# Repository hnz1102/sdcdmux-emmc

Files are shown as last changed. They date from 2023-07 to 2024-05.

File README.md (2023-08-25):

<div align="center">
  <h1><code>SDCDMUX</code></h1>
  <p>
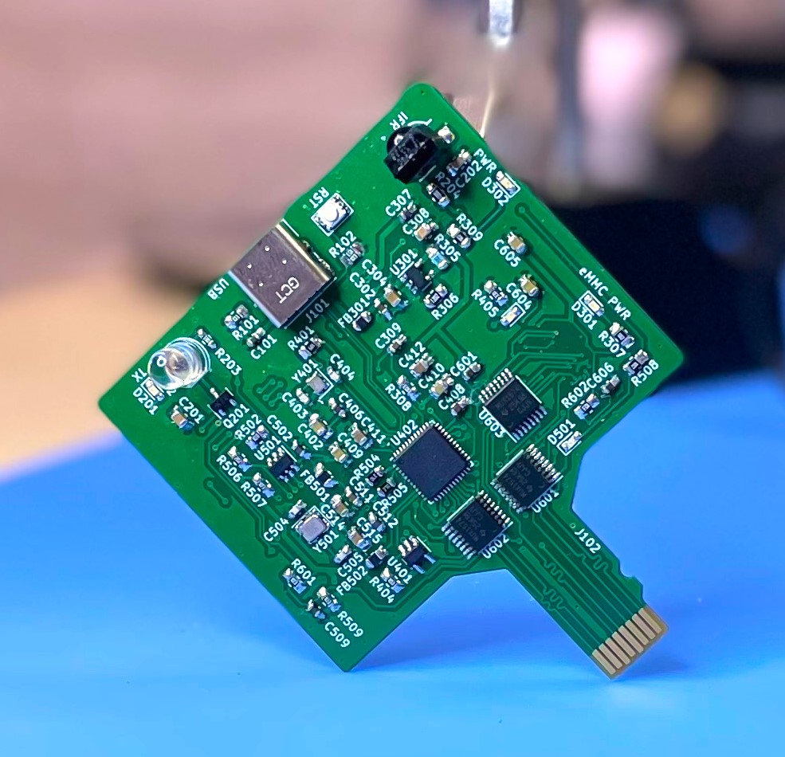
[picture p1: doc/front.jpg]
    
  </p>
</div>

# SDCDMUX : SD Card and eMMC Device Multiplexsor with Infrared Remote Control

The SDCDMUX provides a convenient and quick change of a SW image of a device that has an SD Card interface from a remote. 

When I am developing by booting from an SD memory card on a device such as the Raspberry Pi, it is not easy to rewrite the SD card image and replace it by hand. Remove the SD card, insert it into the host PC, and take a dozen minutes rewriting the SW image, after that, return the SD card to the device and turn on the power... But, This tool can change the image of the eMMC directly from the host PC, and the device can be booted as an SD card with the new image.

Usually, To boot with the new SW image, the device must be reset, but this tool can learn the ON/OFF command of the infrared power controller and outputs that command to turn the device on and off.

This tool frees me from the tedious SW image rewriting and resetting process.

https://github.com/hnz1102/sdcdmux-emmc/assets/111413646/edf4297e-6da3-4eba-aacd-01ee126e1040

### [2023.8.15] USB Type-C version Added.
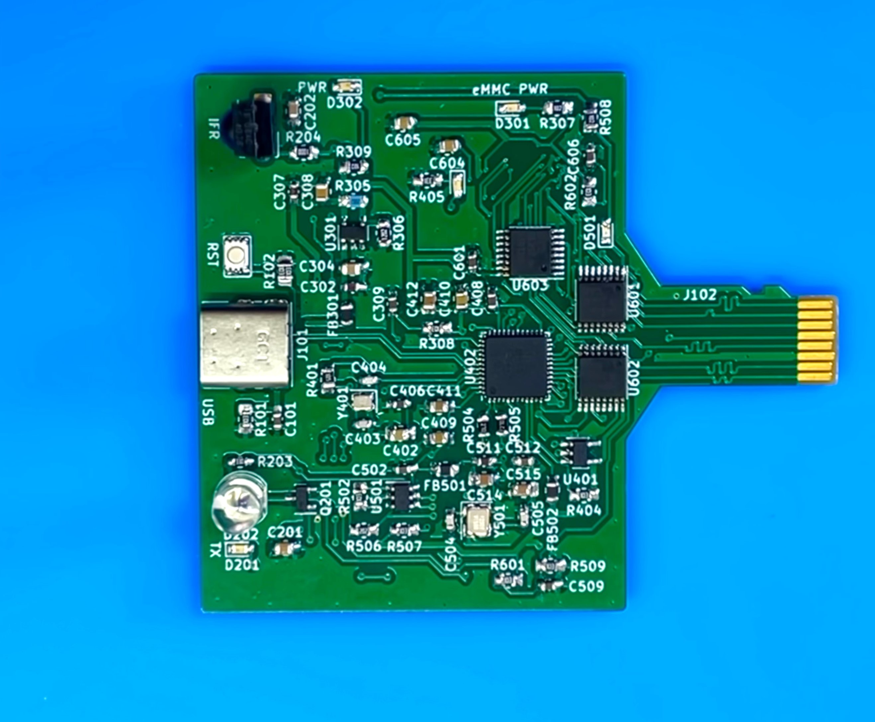
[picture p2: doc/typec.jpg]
USB Type-C

The Schematic is hardware/emmc-type-c-version/ directory.

## Features

- **Fast**. SDCDMUX can write an image to the eMMC device (32GB) instead of SD Memory Card via High-Speed USB. It is 4 times faster than an SD card. 

- **Remote Control**. SDCDMUX has an infrared interface that can receive an infrared remote control command and send it to power control devices. If you want to turn on a device, you can type the command "on" on the PC console.

- **Use Fast Switch**. When I used the prototype, Sometimes Rasbery Pi4 could not boot by read error. I tried to change faster switching devices in this tool. Then, Raspberry Pi always can boot correctly.

## Tested Devices

I have checked the following devices that can boot from this tool.

- [Raspberry Pi 4 Model B](https://www.raspberrypi.com/products/raspberry-pi-4-model-b/)
- [BeagleBone Black](https://beagleboard.org/black)
- [BeagleBone Blue](https://beagleboard.org/blue)

Only 3 devices because I have my own now.

## Infrared Remote Power Switch

The Infrared Remote Contorol Power Swtich I used is [OCR-05W OHM ELECTRIC INC.](https://www.ohm-electric.co.jp/product/c23/c2313/19582/). But I think other switch devices that can control by the infrared LED may be able to work too. 

## How to build the control SW.

This software (sdcdmux) is for Linux. 

The following example is for Ubuntu Linux Ubuntu 22.04.2 LTS.

1. Install build tools
```
$ sudo apt -y install build-essential libftdi-dev
```

2. Build the software.
```
$ cd sdcdmux
$ make
$ sudo cp sdcdmux /usr/local/bin/ 
```
3. Add a udev rule.
/etc/udev/rules.d/99-ft232h.rules
```
$ sudo su
# echo 'SUBSYSTEMS=="usb", ATTRS{idVendor}=="0403", ATTRS{idProduct}=="6014",  MODE=
"0666"' > /etc/udev/rules.d/99-ft232h.rules
# udevadm control --reload-rules
# udevadm trigger
```

## How to use SDCDMUX.

1. Connect to SDCDMUX via the USB cable with your PC. Power USB cable connect to the target device and USB adoptor. Please refer to the figure. 
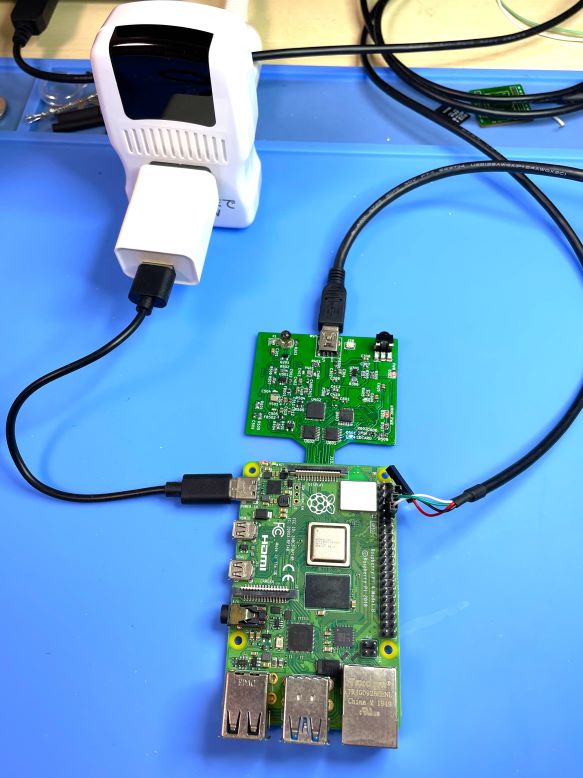
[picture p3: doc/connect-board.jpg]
cable connect

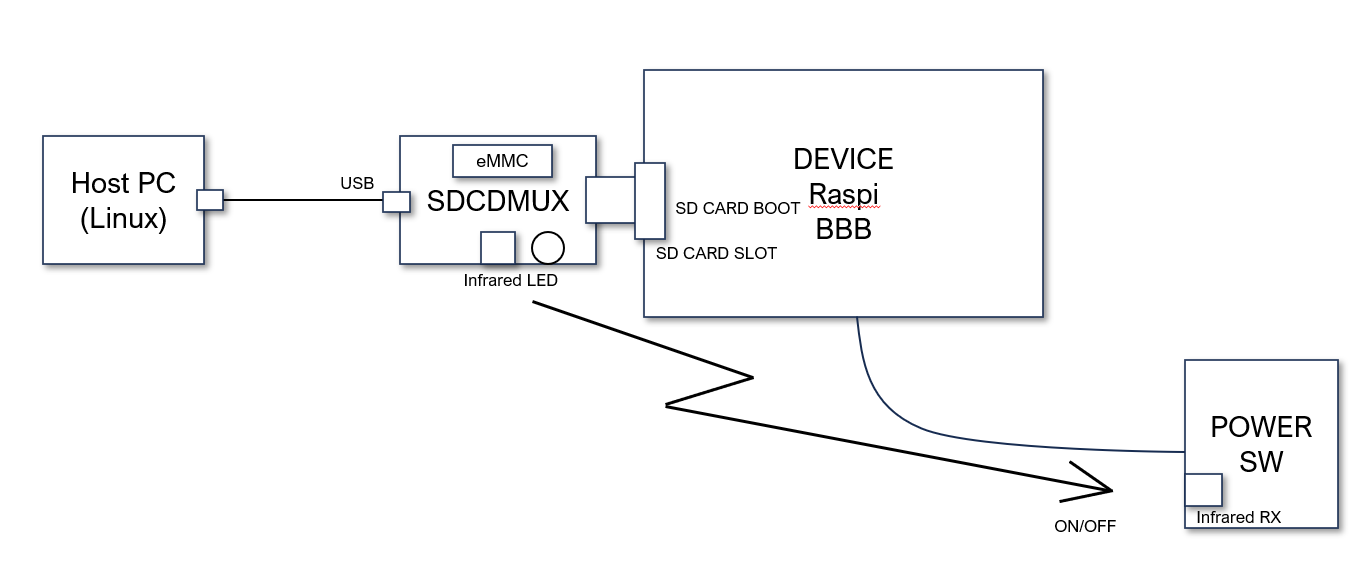
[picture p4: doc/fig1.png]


2. Use SDCDMUX

- Display current status.
```
$ sdcdmux
Memory Device is connected to : HOST.
```

- Capture infrared ON command.
```
$ sdcdmux -c on
Capture Start.. 
"Push ON button on your Infrared Remote Controller"
Recieve IFR data (18245B)
Captured command for on
```
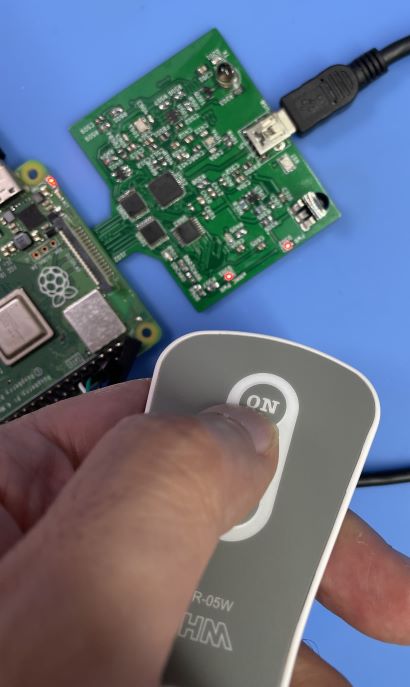
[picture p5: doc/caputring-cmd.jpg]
capture command


After capture the command, you can see the 'if-on' file in the current directory.

- Capture infrared OFF command.
```
$ sdcdmux -c off
Capture Start.. 
"Push OFF button on your Infrared Remote Controller"
Recieve IFR data (11449B)
Captured command for off
```

- Select eMMC memory to host PC side.
```
$ sdcdmux -s host
Memory Device is connected to : HOST.
```
You can see eMMC disk drive on your PC.
```
$ lsblk
:
sdb           8:16   1  29.1G  0 disk 
:
```
In my case, I can see the new disk drive as 'sdb'.

- Download the Raspberry Pi boot image and Write it to eMMC.

** !WARNING! ** DO NOT OVERWRITE YOUR SYSTEM DISK DRIVE! BE CAREFUL THE WRITING DISK DRIVE NAME.

```
$ wget https://downloads.raspberrypi.org/raspios_armhf/images/raspios_armhf-2023-05-03/2023-05-03-raspios-bullseye-armhf.img.xz
$ xzcat 2023-05-03-raspios-bullseye-armhf.img.xz | sudo dd of=/dev/sdb bs=1M status=progress
4125163520 bytes (4.1 GB, 3.8 GiB) copied, 94 s, 43.9 MB/s
0+491118 records in
0+491118 records out
4143972352 bytes (4.1 GB, 3.9 GiB) copied, 126.121 s, 32.9 MB/s
$ lsblk
sdb           8:16   1  29.1G  0 disk 
├─sdb1        8:17   1   256M  0 part 
└─sdb2        8:18   1   3.6G  0 part 
```

- Select eMMC memory to target (Raspberry Pi) device.
```
$ sdcdmux -s target
Memory Device is connected to : TARGET.
```
You can see the blue LED is turn on.

- Turn on the device using infrared on command.
```
$ sdcdmux -x on
```

- Turn off the device using infrared on command.
```
$ sdcdmux -x off
```

- Another devices control.

I also use the SDCDMUX as a controller to turn ceiling lights on and off.
```
$ sdcdmux -c lightson
Capture Start.. 
"Press ON on the remote controller of the ceiling light to make it learn the command."
Recieve IFR data (8498B)
Captured command for lightson

$ sdcdmux -c lightsoff
Capture Start.. 
"Press OFF on the remote controller of the ceiling light to make it learn the command."
Recieve IFR data (10701B)
Captured command for lightsoff

$ sdcdmux -x lightson
"Seiling lights turn on."

$ sdcdmux -x lightsoff
"Seiling lights turn off."
```

## Performance

I created an SD card type and an eMMC type. I compared their writing times.

4.2GB Image Writing Time (Average of 3 times)
|SD card (*1)|eMMC (*2)|
|----|----|
|482.3 sec (8.7MB/s)|134.7 sec (31.3MB/s)|

*1 San Disk Ultla 32GB HC1 SD CARD

*2 Delkin Devices EM32VSUKN 32GB eMMC

## SDCDMUX Board

SDCDMUX Board Schematic and a PCB layout are placed in the hardware directory. There are 2 types emmc-version and sdcard-version. This emmc-version uses an eMMC device instead of a SD memory card.
Schematic data is created by KidCad 7.0.

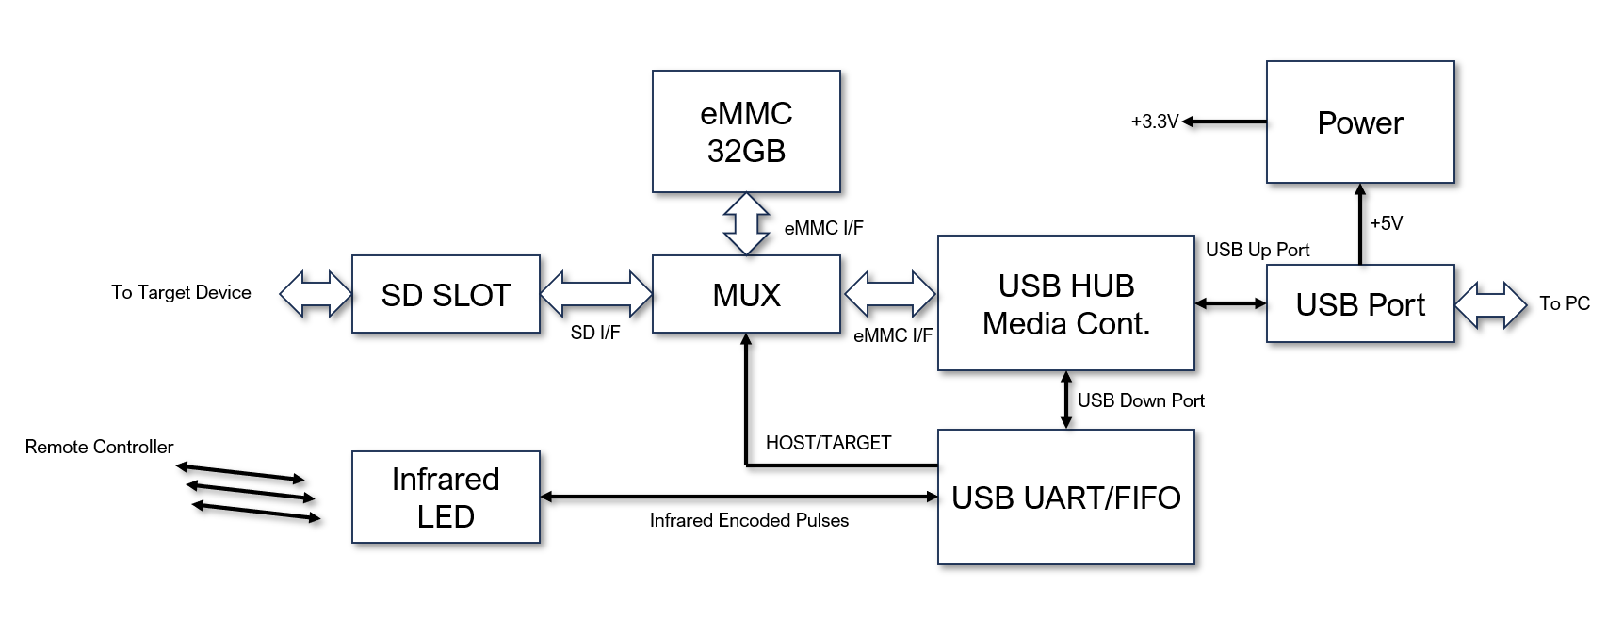
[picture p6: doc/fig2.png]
Block Diagram


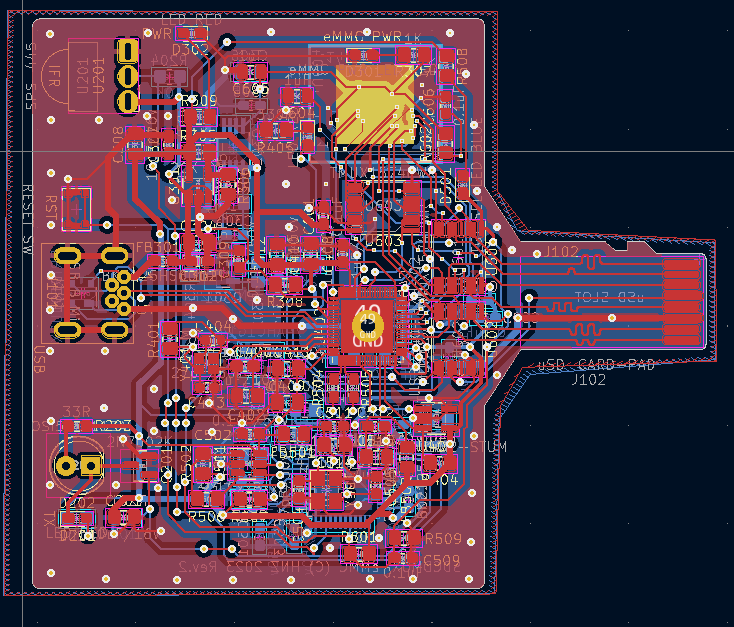
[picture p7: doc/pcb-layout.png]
PCB Layout


If you order a PCB board from a PCB maker, it must be 0.8mm thick. Otherwise, it will not fit in the SD card slot.

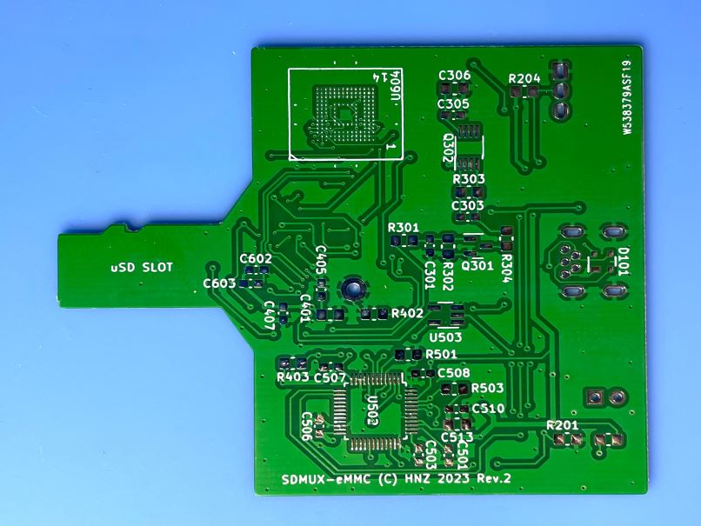
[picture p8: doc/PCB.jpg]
PCB


After building the board, It has to configure EEPROMs of the USB Media Controller and USB FIFO Interface.

The USB Media Controller has an EEPROM. It is programmed with the parameters by [USBDM tool](https://www.microchip.com/en-us/software-library/usbdm-tool).

- Manufacture String
- Serial Number String

Single Channel HiSpeed USB to Multipurpose UART/FIFO IC (FT232H) has an EEPROM too. It is programmed the parameters by [FT_Prog](https://ftdichip.com/wp-content/uploads/2023/06/FT_Prog_v3.12.32.640-Installer.zip).

- FT EEPROM - HARDWARE Specific IO Controls - C5, C6, C8 and C9 ports are I/O Mode set.

# CASE

I created the case for SDCDMUX type-C version by 3D printer. There are STL data in the hardware/emmc-type-c-version/case directory.

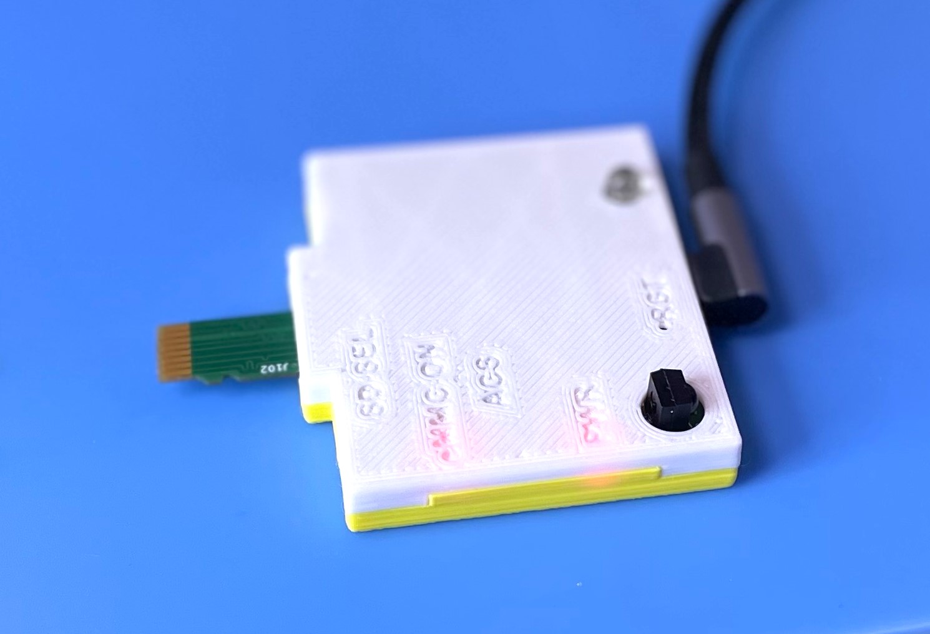
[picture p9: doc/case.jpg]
case


## LICENSE
This Software is licensed under MIT. Other Hardware Schematic documents are licensed under CC-BY-SA V4.0.

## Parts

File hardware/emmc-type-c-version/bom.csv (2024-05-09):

Reference | Value | Datasheet | Footprint | Qty | DNP | digikey | storeURL
C101,C301,C302,C305,C307,C309,C405,C406,C407,C408,C501,C502,C503,C506,C507,C508,C509,C510,C511,C512,C601,C602,C603,C606 | 0.1uF | ~ | Capacitor_SMD:C_0603_1608Metric_Pad1.08x0.95mm_HandSolder | 24 |  | 311-1824-1-ND | https://www.digikey.com/en/products/detail/yageo/CC0603MRX7R7BB104/5195231
C201,C304,C306,C308 | 10uF | ~ | Capacitor_SMD:C_0805_2012Metric_Pad1.18x1.45mm_HandSolder | 4 |  | 311-1355-1-ND | https://www.digikey.com/en/products/detail/yageo/CC0805ZKY5V6BB106/2103093
C202 | 22uF | ~ | Capacitor_SMD:C_0603_1608Metric_Pad1.08x0.95mm_HandSolder | 1 |  | 311-1815-1-ND | https://www.digikey.com/en/products/detail/yageo/CC0603MRX5R5BB226/5195222
C303 | 2.2uF | ~ | Capacitor_SMD:C_0603_1608Metric_Pad1.08x0.95mm_HandSolder | 1 |  | 311-1795-1-ND | https://www.digikey.com/en/products/detail/yageo/CC0603KRX7R5BB225/5195203
C401,C402,C409,C410,C604,C605 | 1uF | ~ | Capacitor_SMD:C_0805_2012Metric_Pad1.18x1.45mm_HandSolder | 6 |  | 311-3440-1-ND | https://www.digikey.com/en/products/detail/yageo/CC0805MRY5V7BB105/5884286
C403,C404,C504,C505 | 27pF | ~ | Capacitor_SMD:C_0603_1608Metric_Pad1.08x0.95mm_HandSolder | 4 |  | 311-1063-1-ND | https://www.digikey.com/en/products/detail/yageo/CC0603JRNPO9BN270/302797
C411,C412,C513,C514,C515 | 4.7uF | ~ | Capacitor_SMD:C_0805_2012Metric_Pad1.18x1.45mm_HandSolder | 5 |  | 490-14466-1-ND | https://www.digikey.com/en/products/detail/murata-electronics/GRM21BR71C475KE51L/6606095
D101 | PRTR5V0U2X | https://assets.nexperia.com/documents/data-sheet/PRTR5V0U2X.pdf | Package_TO_SOT_SMD:SOT-143 | 1 |  | 1727-3884-1-ND | https://www.digikey.com/en/products/detail/nexperia-usa-inc/PRTR5V0U2X-215/1163690
D201,D302,D401 | LED RED | ~ | tbctl:LED_0603_1608Metric_Pad1.05x0.95mm_HandSolder | 3 |  | 511-1587-1-ND | https://www.digikey.com/en/products/detail/rohm-semiconductor/SML-E12V8WT86/1641806
D202 | OED-EL-1L2 |  | LED_THT:LED_D5.0mm | 1 |  | 67-1001-ND | https://www.digikey.com/en/products/detail/lumex-opto-components-inc/OED-EL-1L2/270797
D301 | eMMC PWR LED RED | ~ | tbctl:LED_0603_1608Metric_Pad1.05x0.95mm_HandSolder | 1 |  | 511-1587-1-ND | https://www.digikey.com/en/products/detail/rohm-semiconductor/SML-E12V8WT86/1641806
D501 | TGT SEL LED BLUE | ~ | tbctl:LED_0603_1608Metric_Pad1.05x0.95mm_HandSolder | 1 |  | 846-1177-1-ND | https://www.digikey.com/en/products/detail/rohm-semiconductor/SMLE13BC8TT86/5053771
FB301,FB501,FB502 | BK2125HS601-T | ~ | Inductor_SMD:L_0603_1608Metric_Pad1.05x0.95mm_HandSolder | 3 |  | 490-1014-1-ND | https://www.digikey.com/en/products/detail/murata-electronics/BLM18AG601SN1D/584225
J101 | USB_C_Receptacle_USB2.0_GCT4085 | https://www.usb.org/sites/default/files/documents/usb_type-c.zip | Connector_USB:USB_C_Receptacle_GCT_USB4085 | 1 |  | 2073-USB4085-GF-ACT-ND | https://www.digikey.com/en/products/detail/gct/USB4085-GF-A/9859662
J102 | uSD-CARD-PAD | ~ | tbctl:uSD Card Pad | 1 |  | Just Pattern
Q201,Q301 | 2N7002K | https://www.diodes.com/assets/Datasheets/ds30896.pdf | Package_TO_SOT_SMD:SOT-23 | 2 |  | 2N7002K-7DICT-ND | https://www.digikey.com/en/products/detail/diodes-incorporated/2N7002K-7/1934378
Q302 | IRF7606TRPBF | http://www.irf.com/product-info/datasheets/data/irf7606pbf.pdf | Package_SO:MSOP-8_3x3mm_P0.65mm | 1 |  | IRF7606TRPBFCT-ND | https://www.digikey.com/en/products/detail/infineon-technologies/IRF7606TRPBF/856652
R101,R201,R205,R302,R303,R308,R403,R404,R502,R503,R507,R509,R601,R602 | 10K | ~ | Resistor_SMD:R_0805_2012Metric_Pad1.20x1.40mm_HandSolder | 14 |  | 311-10KARCT-ND | https://www.digikey.com/en/products/detail/yageo/RC0805JR-0710KL/728241
R102,R103 | 5.1K | ~ | Resistor_SMD:R_0805_2012Metric_Pad1.20x1.40mm_HandSolder | 2 |  | 311-5.1KARCT-ND | https://www.digikey.com/en/products/detail/yageo/RC0805JR-075K1L/728338
R202,R304,R307,R309,R508 | 1K | ~ | Resistor_SMD:R_0805_2012Metric_Pad1.20x1.40mm_HandSolder | 5 |  | 311-1.0KARCT-ND | https://www.digikey.com/en/products/detail/yageo/RC0805JR-071KL/728218
R203 | 33R | ~ | Resistor_SMD:R_0603_1608Metric_Pad0.98x0.95mm_HandSolder | 1 |  | 311-33GRCT-ND | https://www.digikey.com/en/products/detail/yageo/RC0603JR-0733RL/726771
R204 | 100 | ~ | Resistor_SMD:R_0805_2012Metric_Pad1.20x1.40mm_HandSolder | 1 |  | 311-100ARCT-ND | https://www.digikey.com/en/products/detail/yageo/RC0805JR-07100RL/728238
R301,R506 | 2K | ~ | Resistor_SMD:R_0805_2012Metric_Pad1.20x1.40mm_HandSolder | 2 |  | 311-2.0KARCT-ND | https://www.digikey.com/en/products/detail/yageo/RC0805JR-072KL/728268
R305 | 20K 1% | ~ | Resistor_SMD:R_0805_2012Metric_Pad1.20x1.40mm_HandSolder | 1 |  | 311-20.0KCRCT-ND | https://www.digikey.com/en/products/detail/yageo/RC0805FR-0720KL/727720
R306,R402,R501 | 12K 1% | ~ | Resistor_SMD:R_0805_2012Metric_Pad1.20x1.40mm_HandSolder | 3 |  | 311-12.0KCRCT-ND | https://www.digikey.com/en/products/detail/yageo/RC0805FR-0712KL/727568
R401 | 1M | ~ | Resistor_SMD:R_0805_2012Metric_Pad1.20x1.40mm_HandSolder | 1 |  | 311-1.0MARCT-ND | https://www.digikey.com/en/products/detail/yageo/RC0805JR-071ML/728219
R405 | 330R | ~ | Resistor_SMD:R_0805_2012Metric_Pad1.20x1.40mm_HandSolder | 1 |  | 311-330ARCT-ND | https://www.digikey.com/en/products/detail/yageo/RC0805JR-07330RL/728311
R504,R505 | 27R | ~ | Resistor_SMD:R_0603_1608Metric_Pad0.98x0.95mm_HandSolder | 2 |  | 311-27GRCT-ND | https://www.digikey.com/en/products/detail/yageo/RC0603JR-0727RL/726751
SW301 | RESET SW |  | tbctl:WS-TASV SMT Tact Switch | 1 |  | 732-435151014824CT-ND | https://www.digikey.com/en/products/detail/w%C3%BCrth-elektronik/435151014824/11627325
U201 | TSSP4038 |  | tbctl:TSSP4038 | 1 |  | TSSP4038-ND | https://www.digikey.com/en/products/detail/vishay-semiconductor-opto-division/TSSP4038/3789836
U301 | SPX3819M5-L | https://www.exar.com/content/document.ashx?id=22106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 | Package_TO_SOT_SMD:SOT-23-5 | 1 |  | 1016-1871-1-ND | https://www.digikey.com/en/products/detail/maxlinear-inc/SPX3819M5-L-TR/2472388
U401 | AT24MAC402-STUM | https://ww1.microchip.com/downloads/en/DeviceDoc/Atmel-8807-SEEPROM-AT24MAC402-602-Datasheet.pdf | Package_TO_SOT_SMD:SOT-23-5_HandSoldering | 1 |  | AT24MAC402-STUM-TCT-ND | https://www.digikey.com/en/products/detail/microchip-technology/AT24MAC402-STUM-T/3973071
U402 | USB2640-HZH-02 |  | tbctl:QFN-48-1EP_7x7mm_P0.5mm_EP5.15x5.15mm | 1 |  | USB2640-HZH-02-ND | https://www.digikey.com/en/products/detail/microchip-technology/USB2640-HZH-02/3873172
U501 | 93LCxxBxxOT | http://ww1.microchip.com/downloads/en/DeviceDoc/20001749K.pdf | Package_TO_SOT_SMD:SOT-23-6 | 1 |  | 93LC56BT-I/OTCT-ND | https://www.digikey.com/en/products/detail/microchip-technology/93LC56BT-I-OT/572825
U502 | FT232HL | https://www.ftdichip.com/Support/Documents/DataSheets/ICs/DS_FT232H.pdf | Package_QFP:LQFP-48_7x7mm_P0.5mm | 1 |  | 768-1348-ND | https://www.digikey.com/en/products/detail/ftdi-future-technology-devices-international-ltd/FT232HL-TRAY/4006918
U503 | 74AHC1G14 |  | Package_TO_SOT_SMD:SOT-23-5_HandSoldering | 1 |  | 74AHC1G14W5-7DICT-ND | https://www.digikey.com/en/products/detail/diodes-incorporated/74AHC1G14W5-7/2639249
U601,U602,U603 | TMUX1574PWR |  | Package_SO:TSSOP-16_4.4x5mm_P0.65mm | 3 |  | 296-53444-1-ND | https://www.digikey.com/en/products/detail/texas-instruments/TMUX1574PWR/9954224
U604 | EM32VSUKN |  | tbctl:EM32VSUKN FPGA153 | 1 |  | 3247-EM32VSUKN-BA000-2-ND | https://www.digikey.com/en/products/detail/delkin-devices-inc/EM32VSUKN-BA000-2/16357650
Y401 | 24MHz | ~ | tbctl:Crystal_SMD_2016-4Pin_2.0x1.6mm | 1 |  | XC3064CT-ND | https://www.digikey.com/en/products/detail/ecs-inc/ECS-240-12-37B-CKY-TR/9838851
Y501 | 12MHz | ~ | Crystal:Crystal_SMD_3225-4Pin_3.2x2.5mm | 1 |  | SER3682CT-ND | https://www.digikey.com/en/products/detail/epson/FA-238V-12-0000MB-K3/2403374

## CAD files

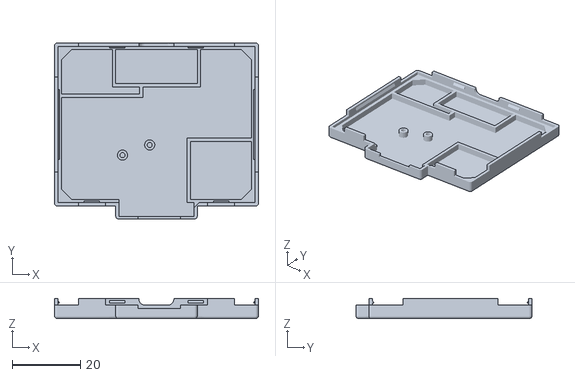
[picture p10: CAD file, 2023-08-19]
hardware/emmc-type-c-version/case/botom-body.stl
60.0 x 51.8 x 6.00

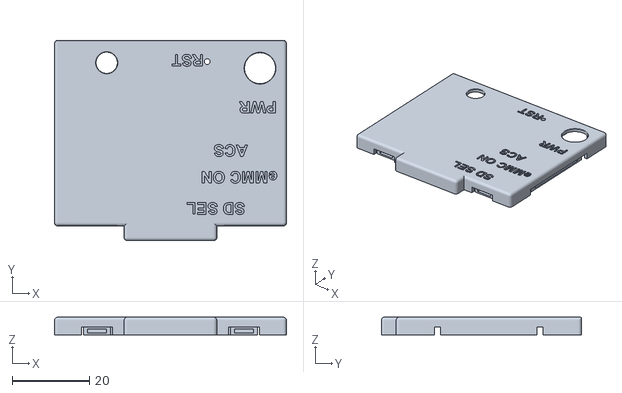
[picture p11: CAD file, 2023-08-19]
hardware/emmc-type-c-version/case/upper-body.stl
60.0 x 51.8 x 4.60

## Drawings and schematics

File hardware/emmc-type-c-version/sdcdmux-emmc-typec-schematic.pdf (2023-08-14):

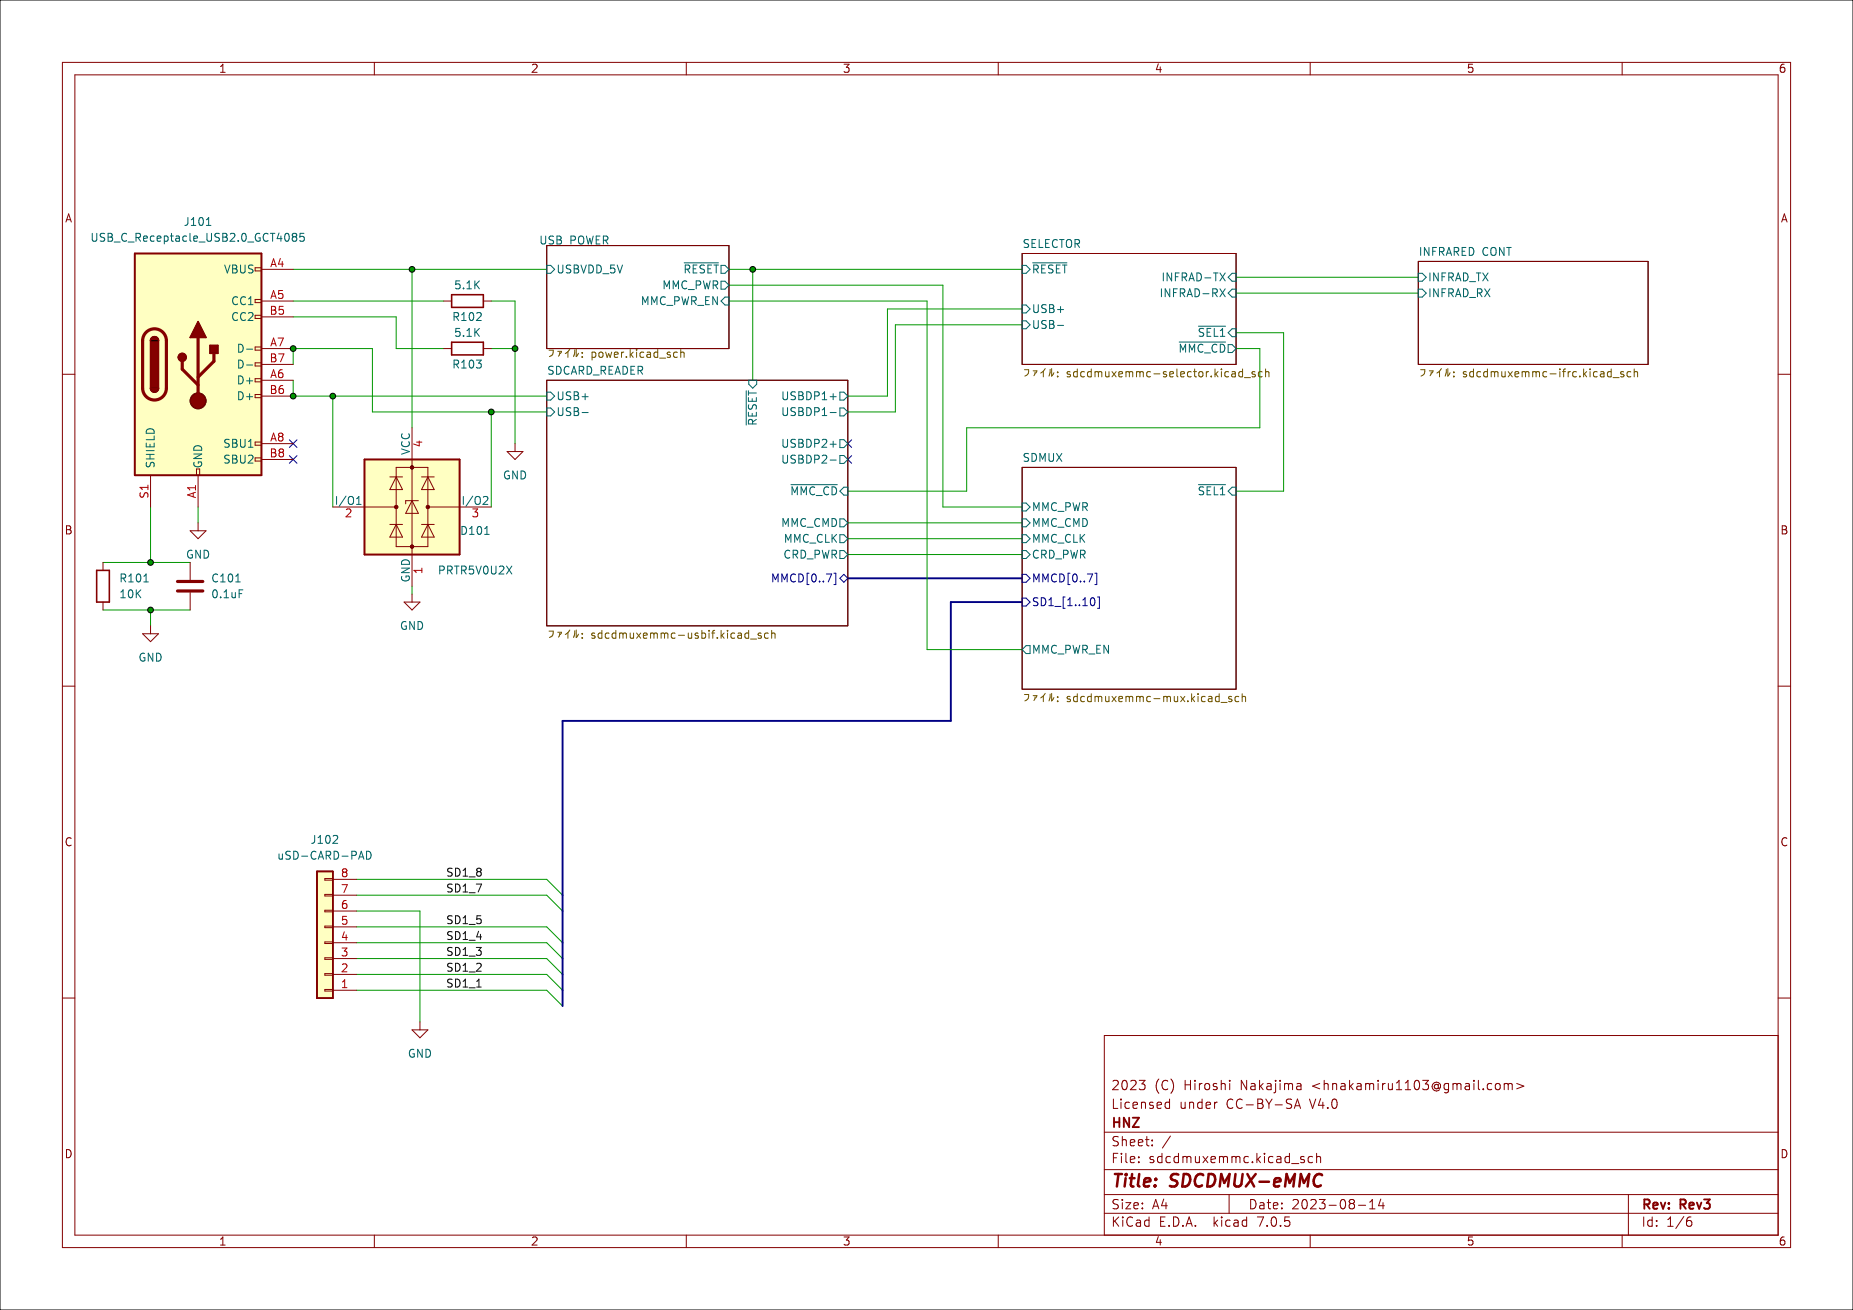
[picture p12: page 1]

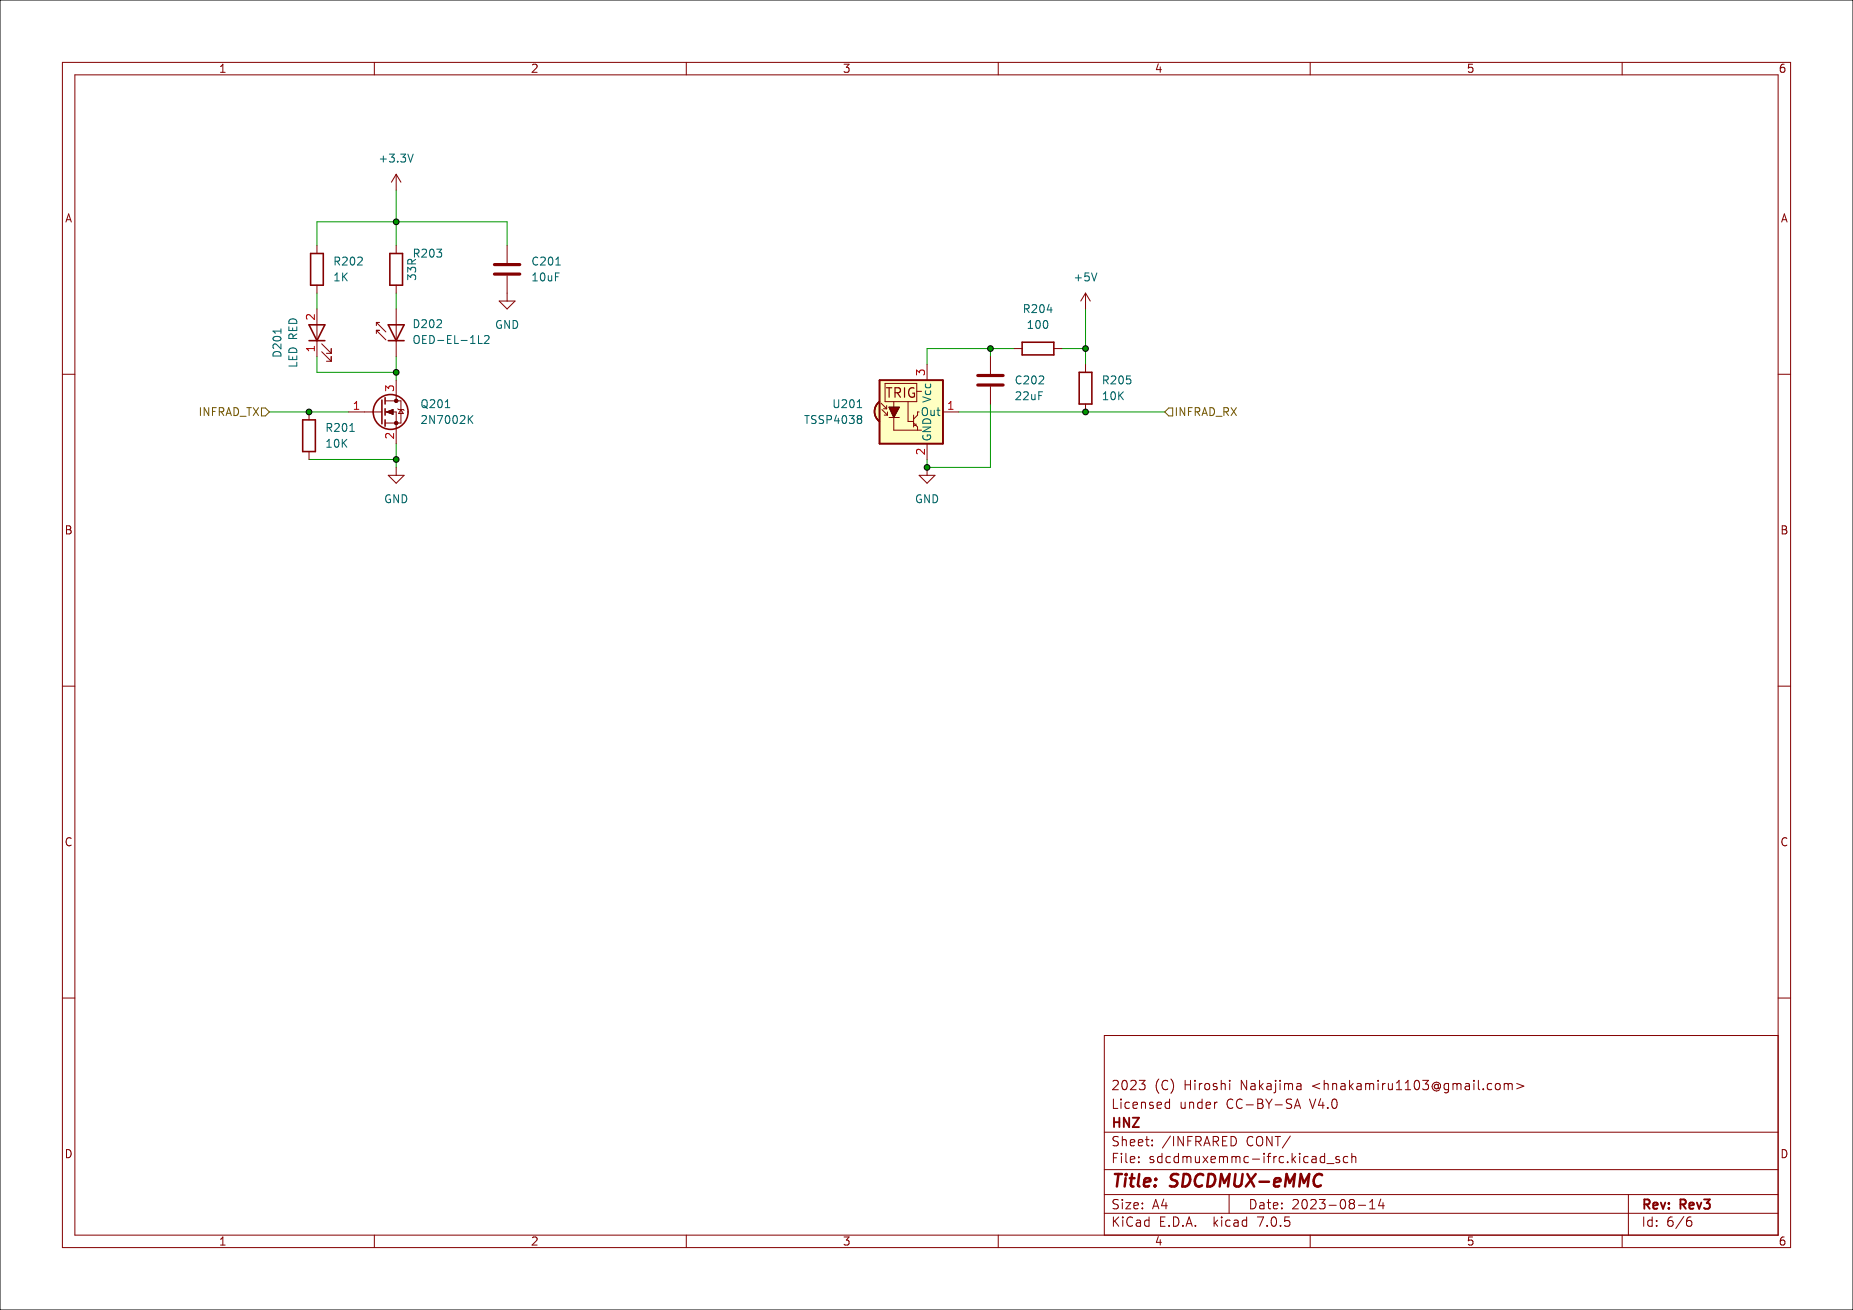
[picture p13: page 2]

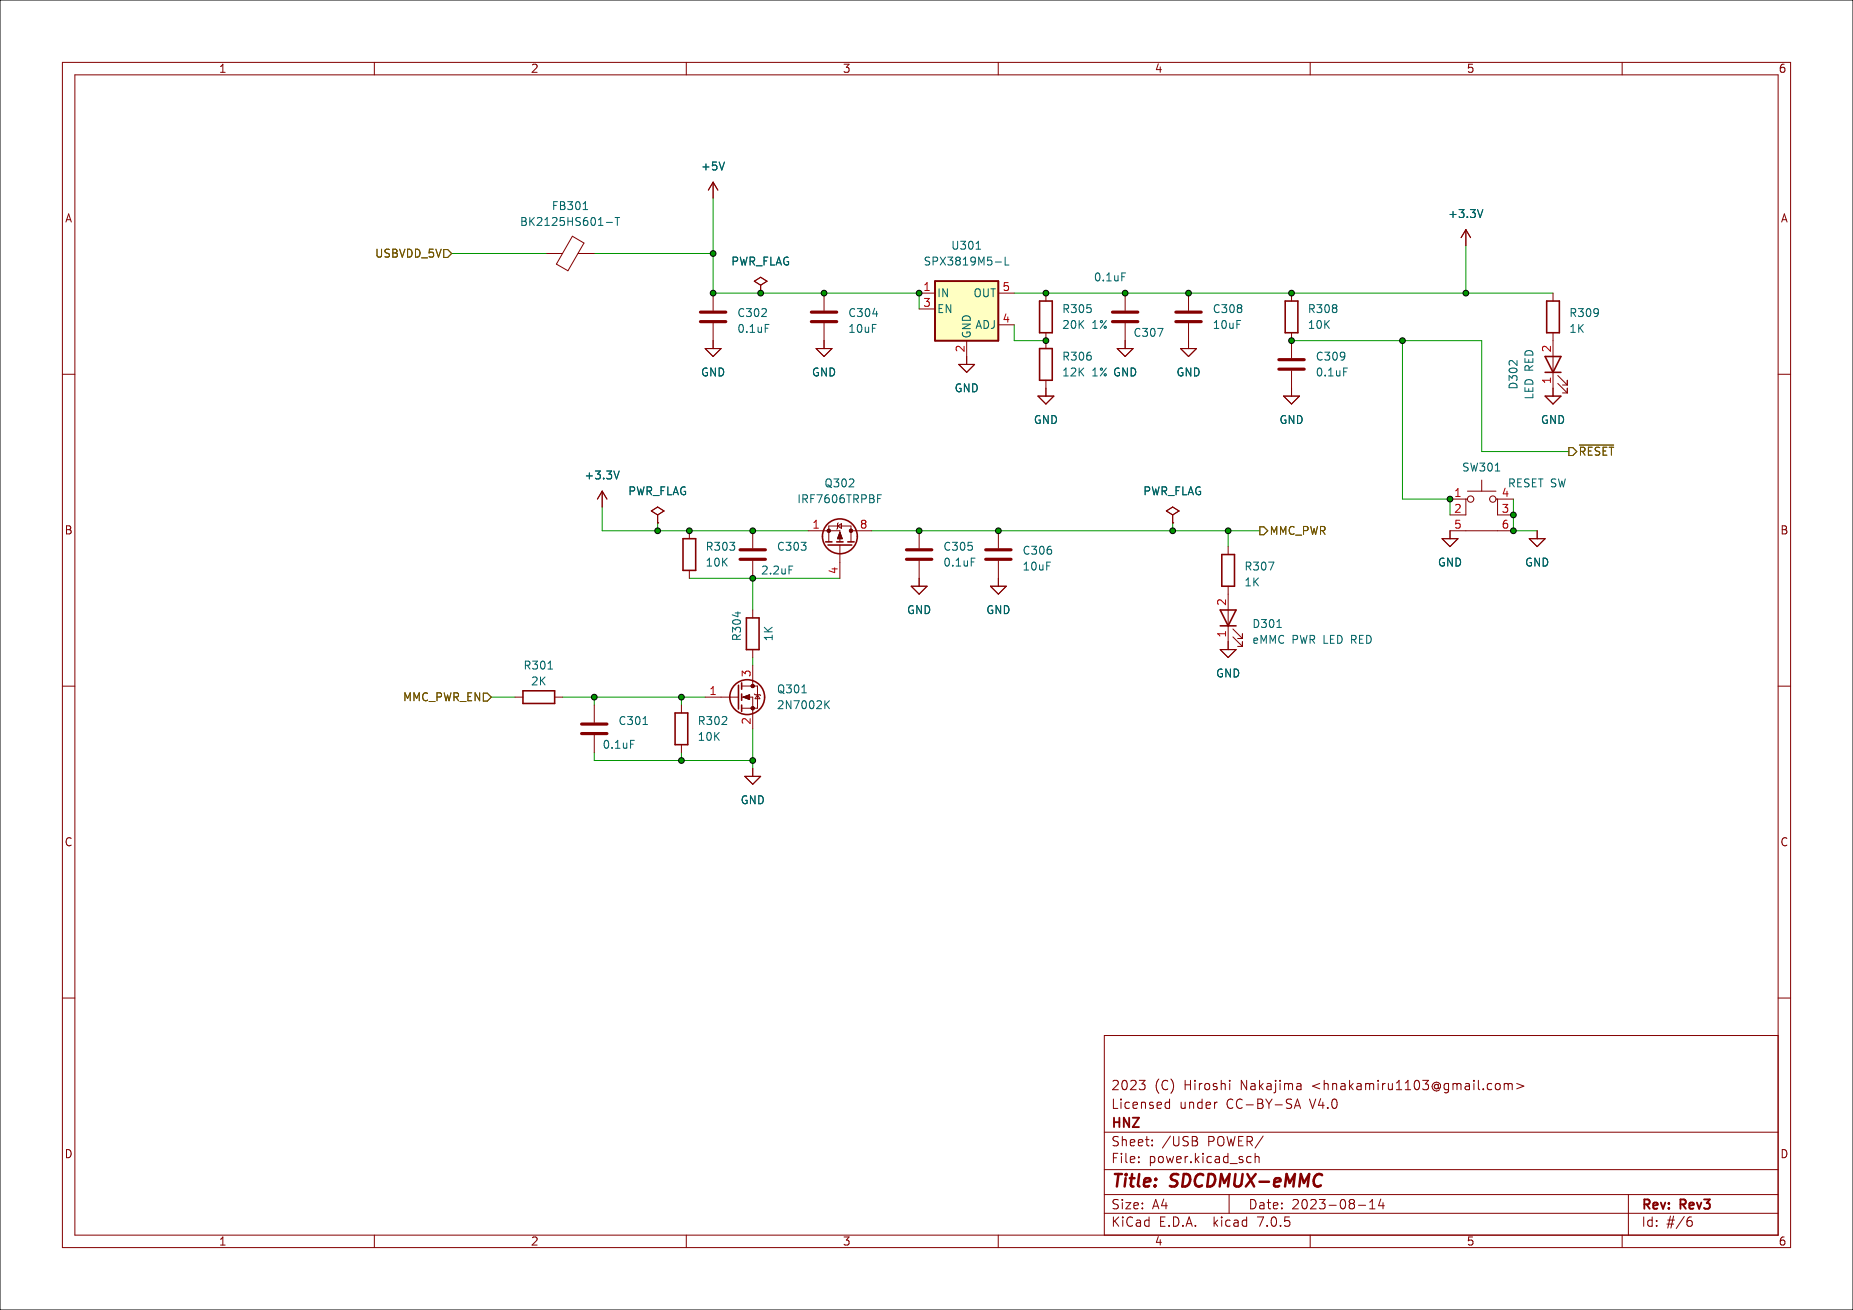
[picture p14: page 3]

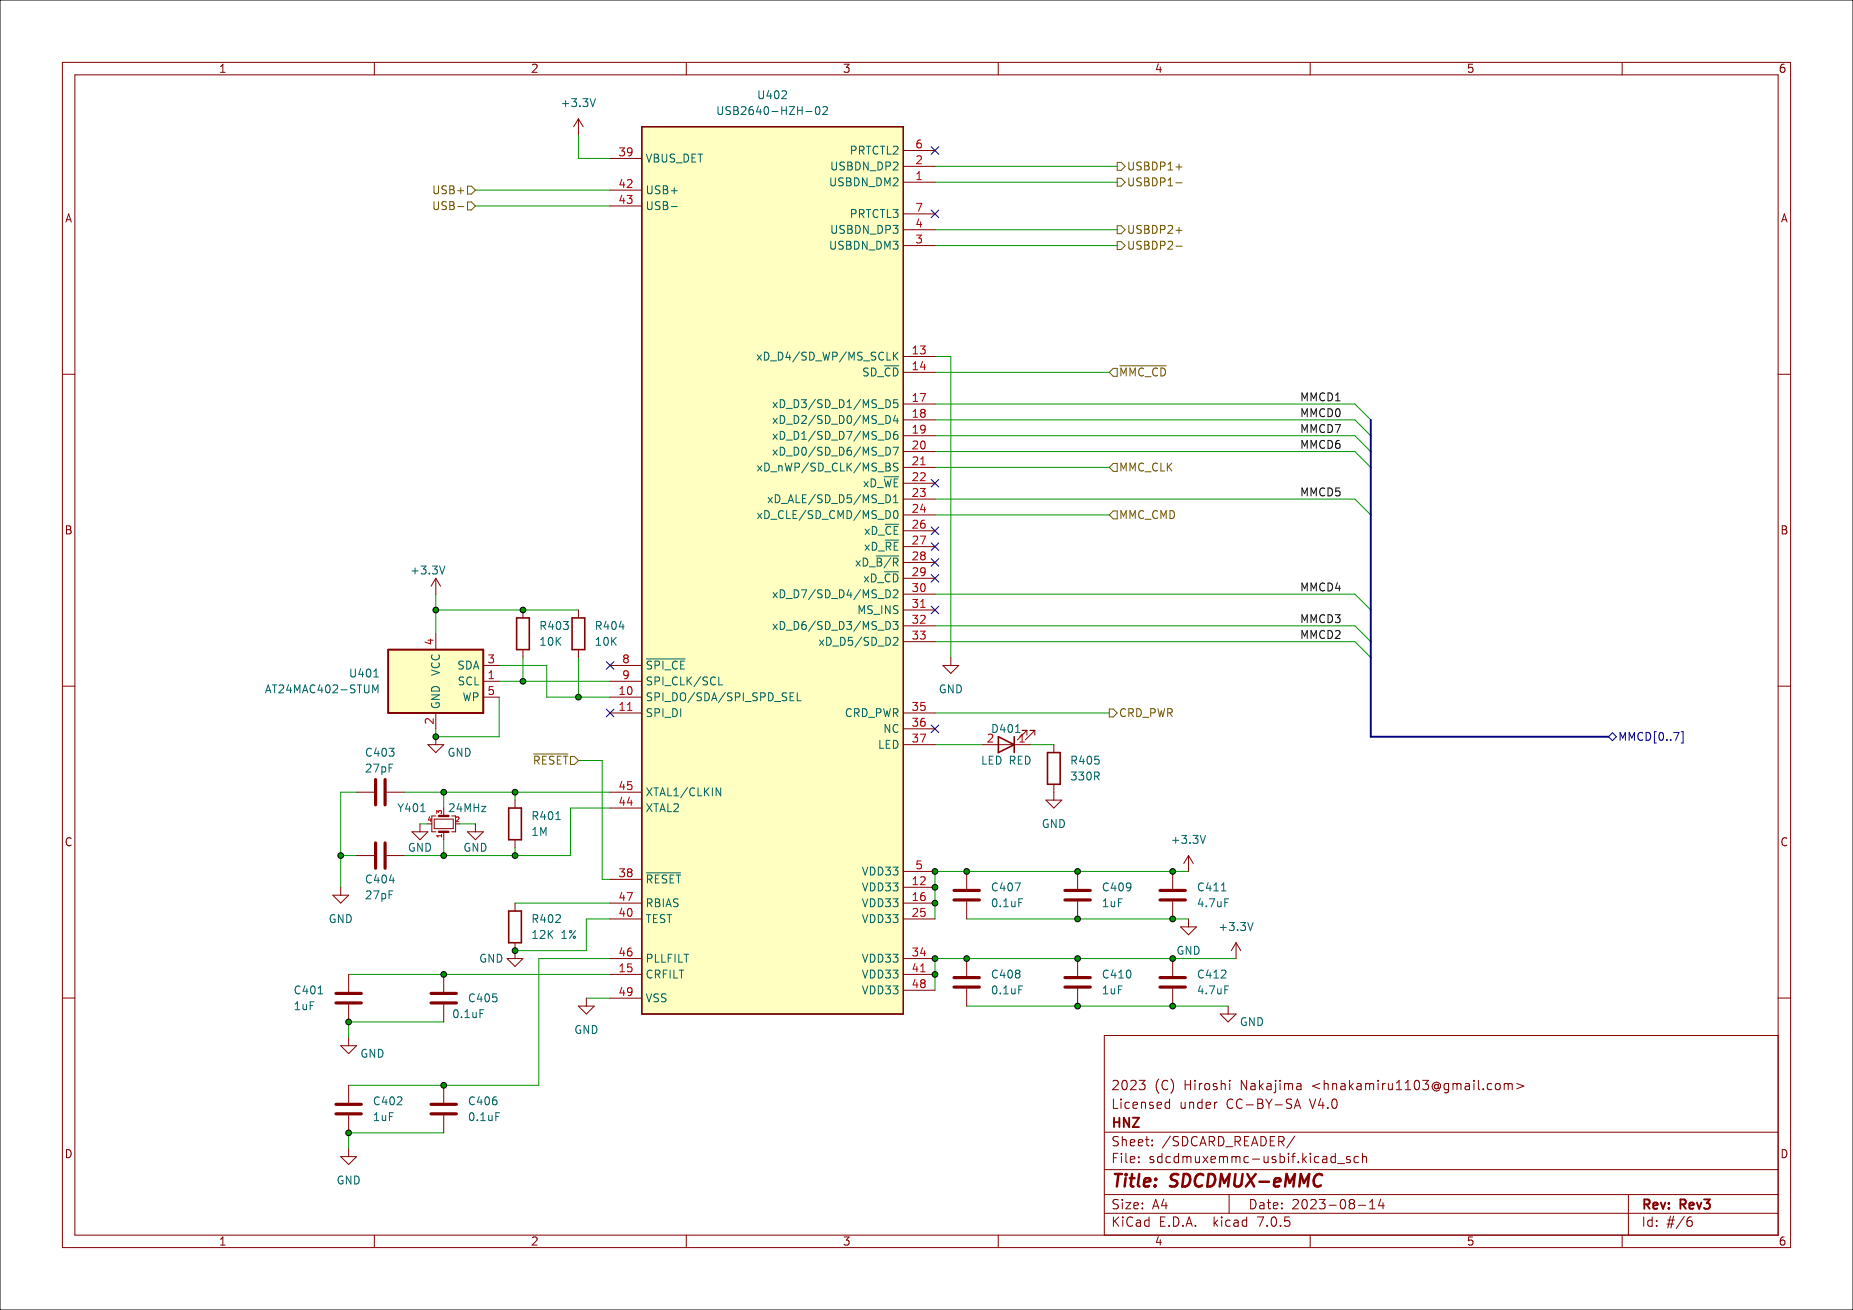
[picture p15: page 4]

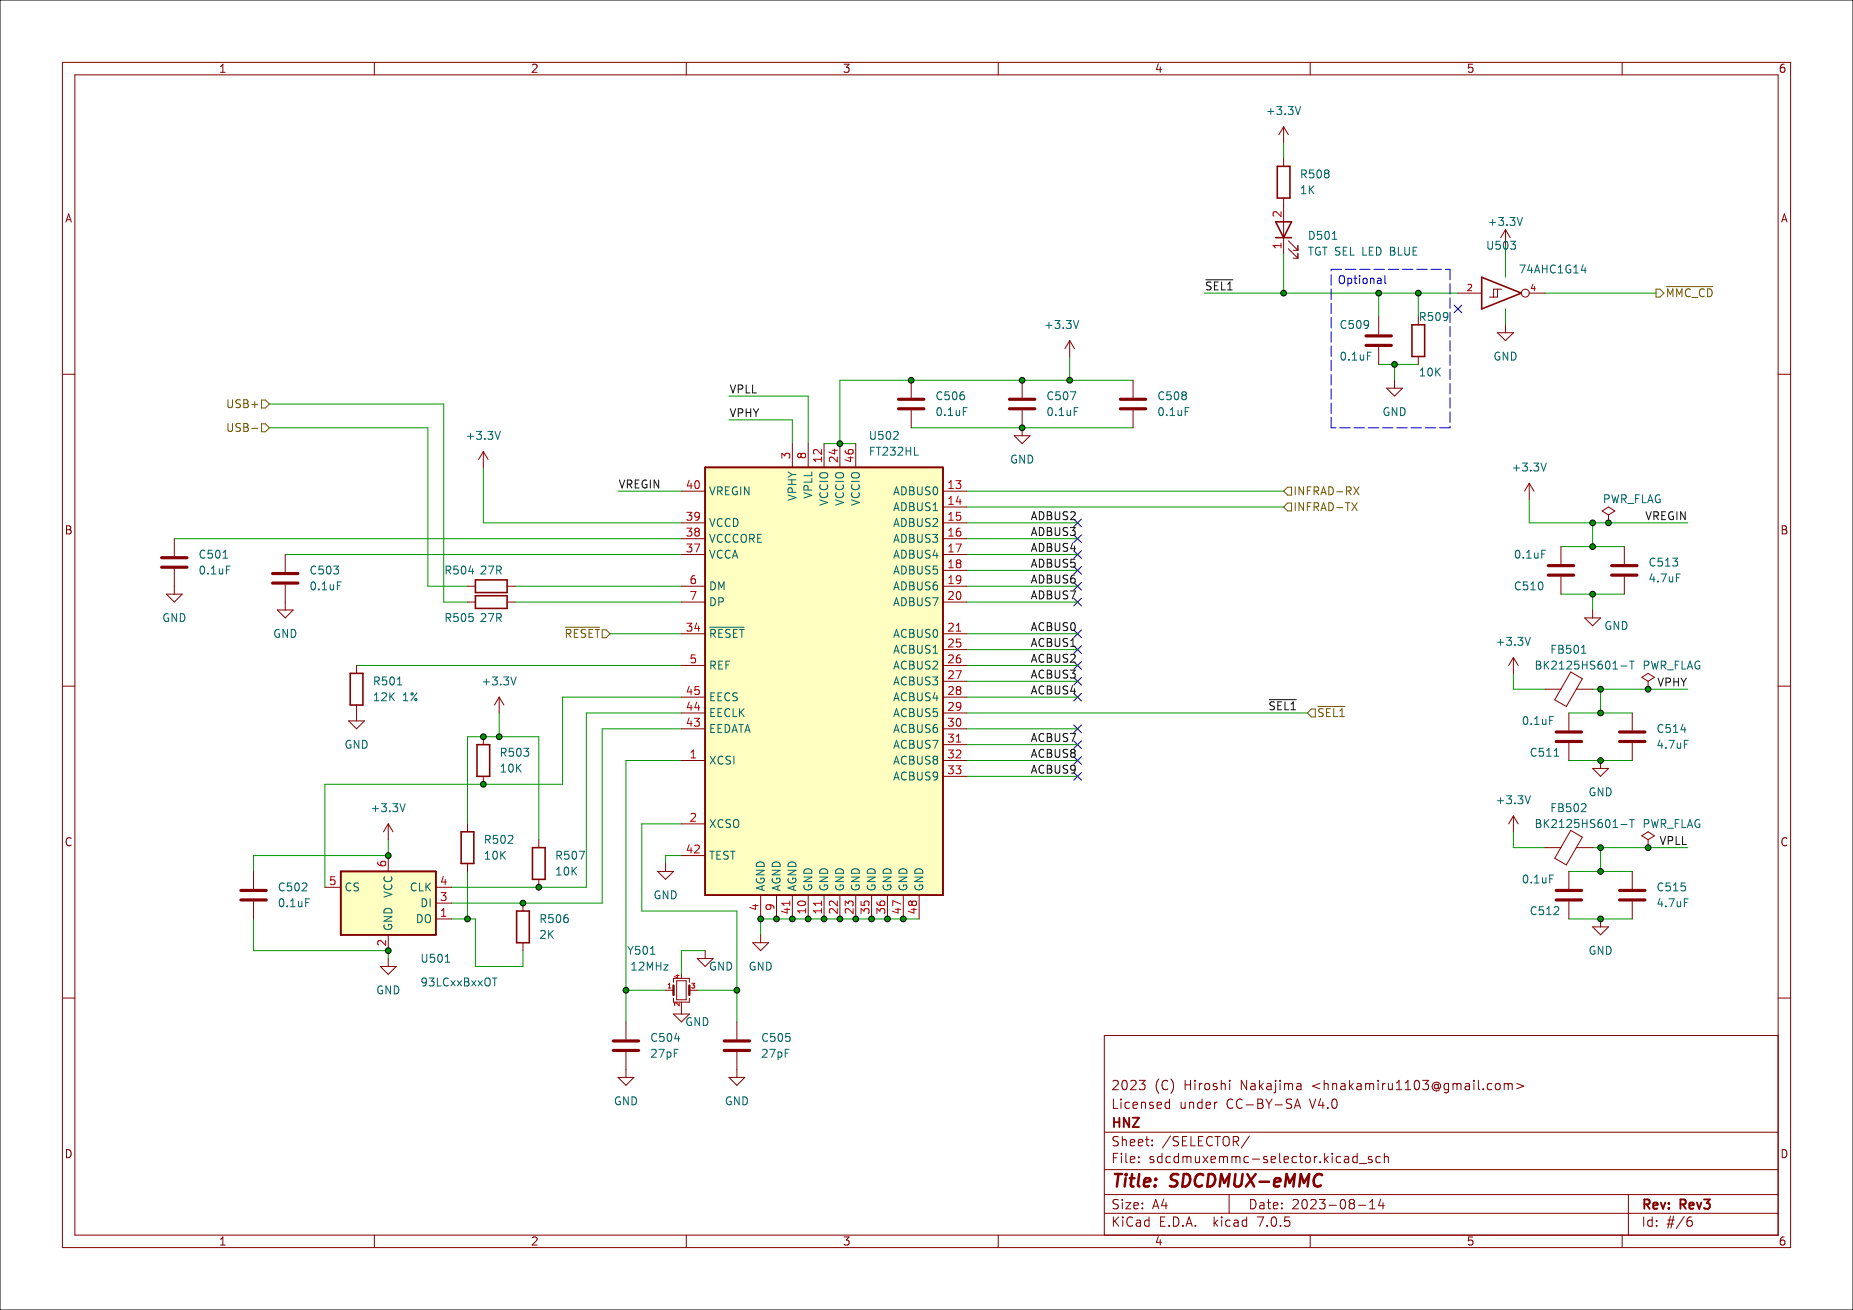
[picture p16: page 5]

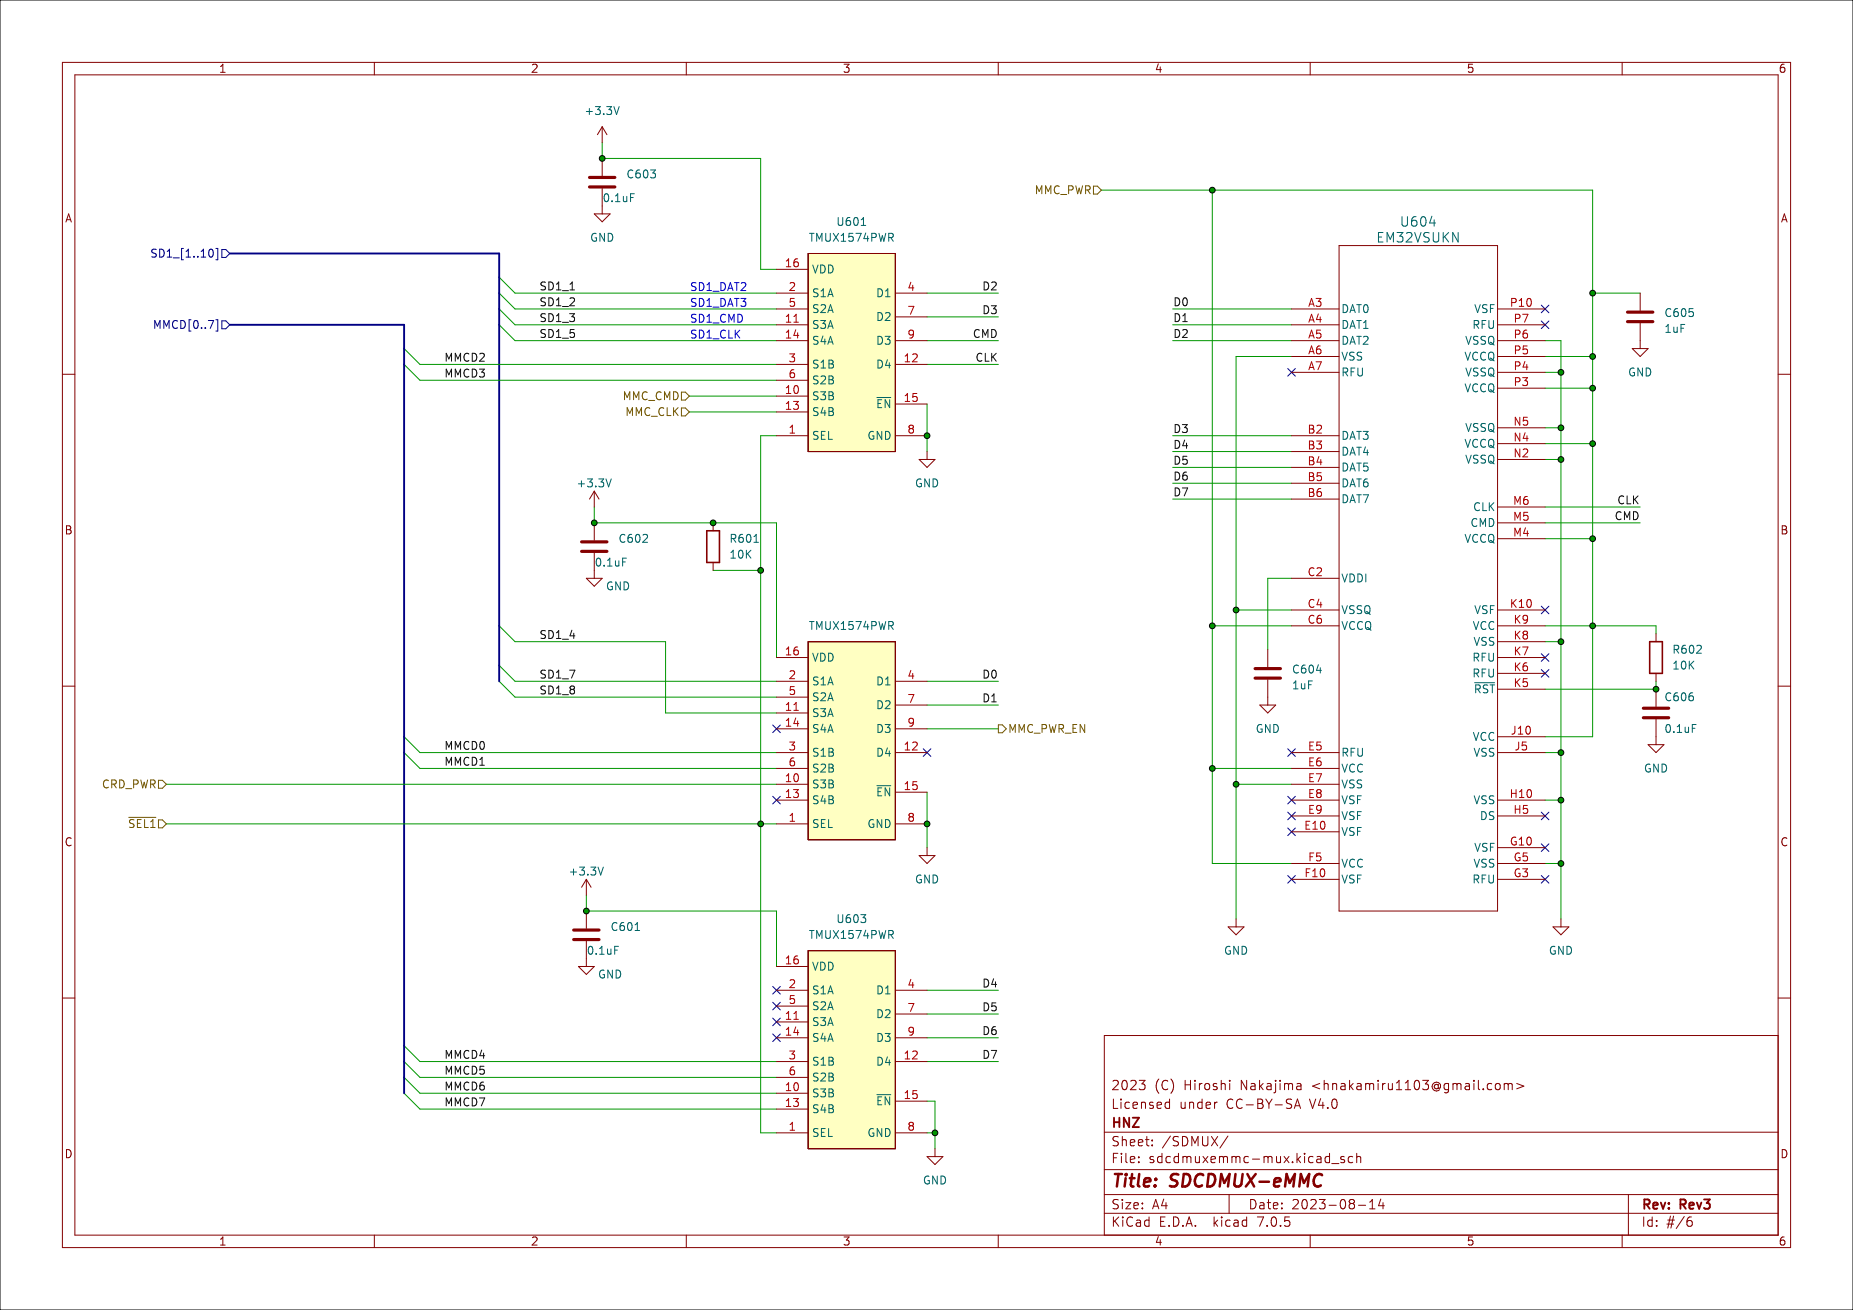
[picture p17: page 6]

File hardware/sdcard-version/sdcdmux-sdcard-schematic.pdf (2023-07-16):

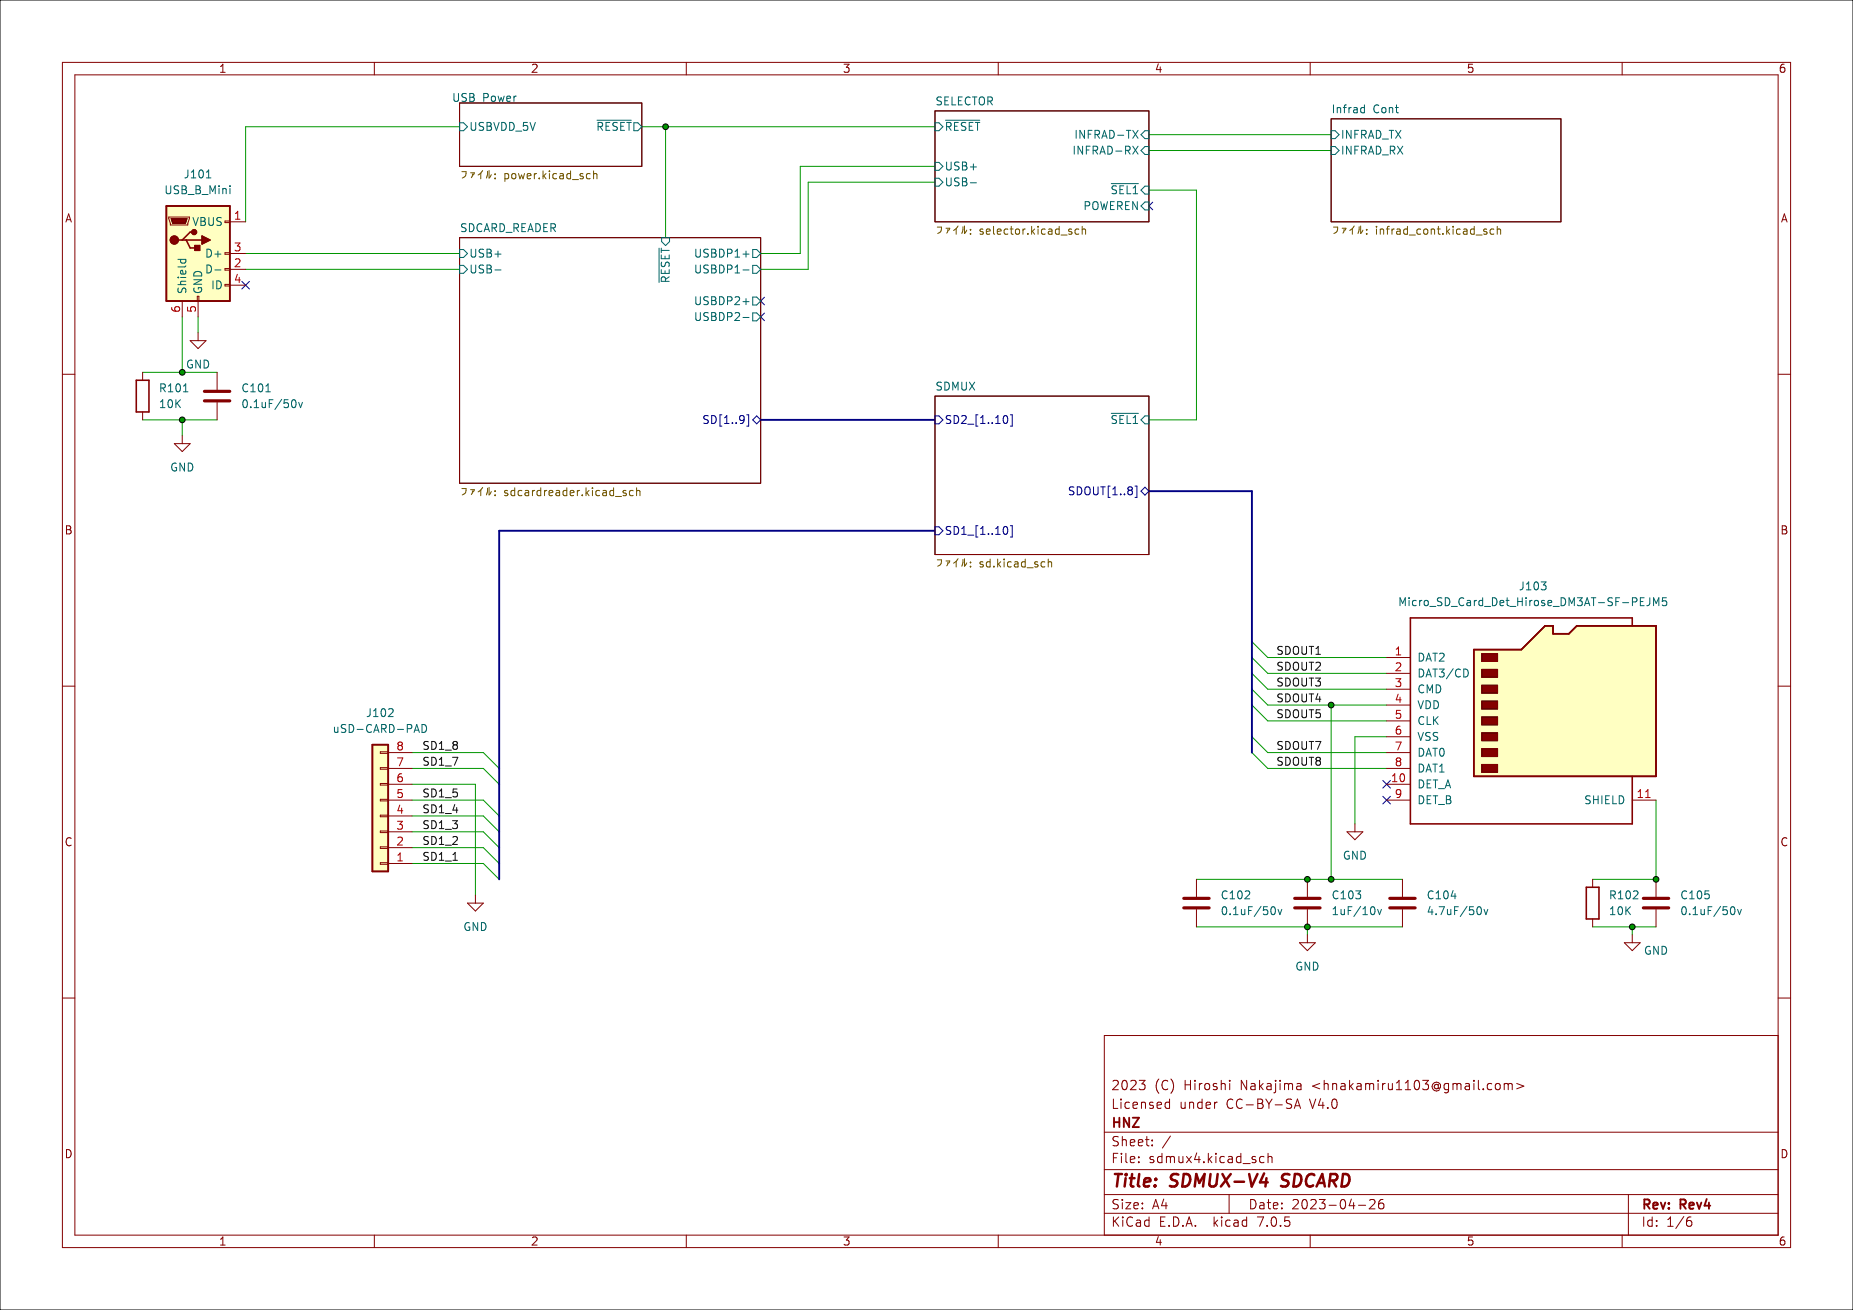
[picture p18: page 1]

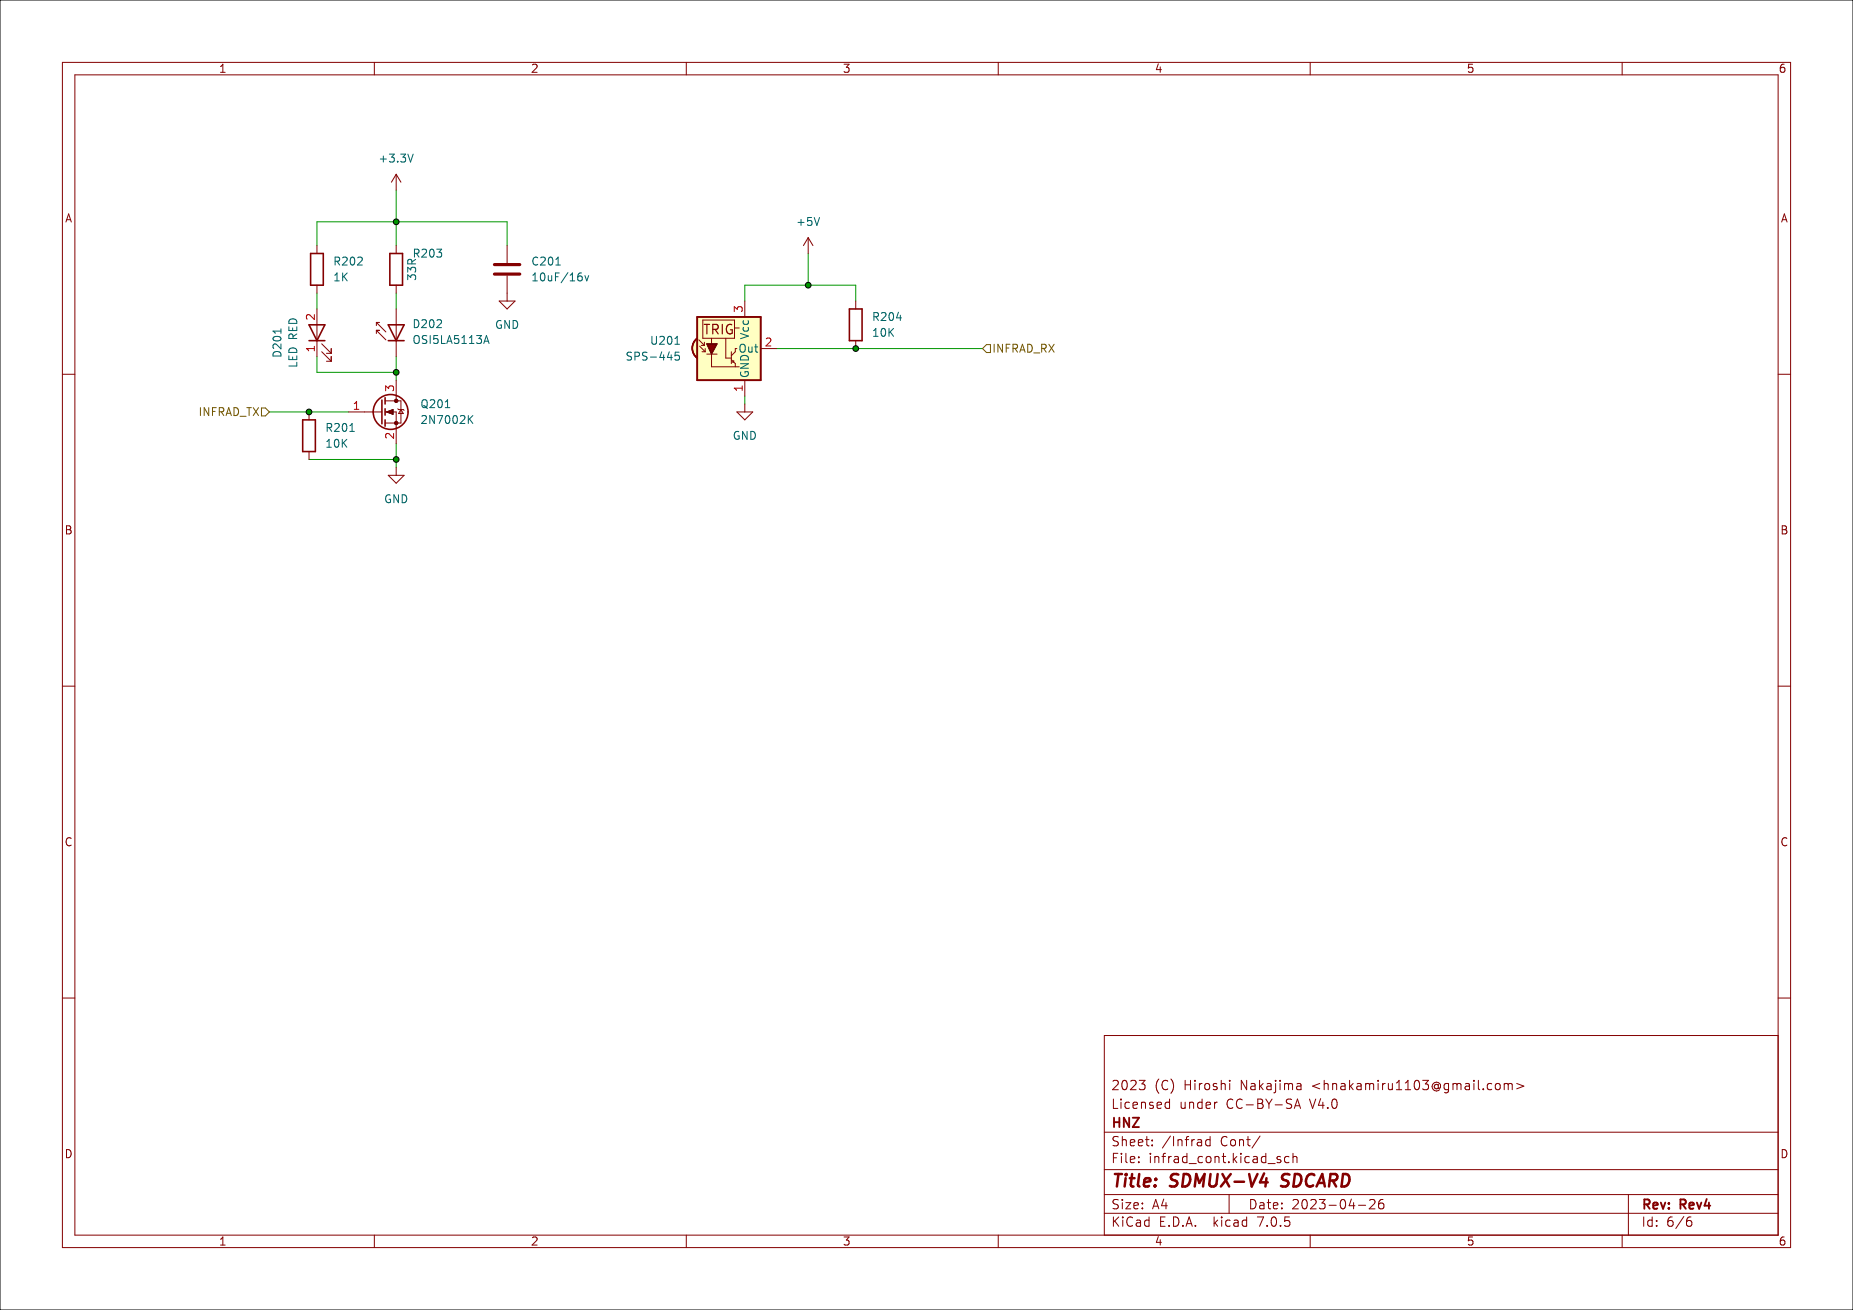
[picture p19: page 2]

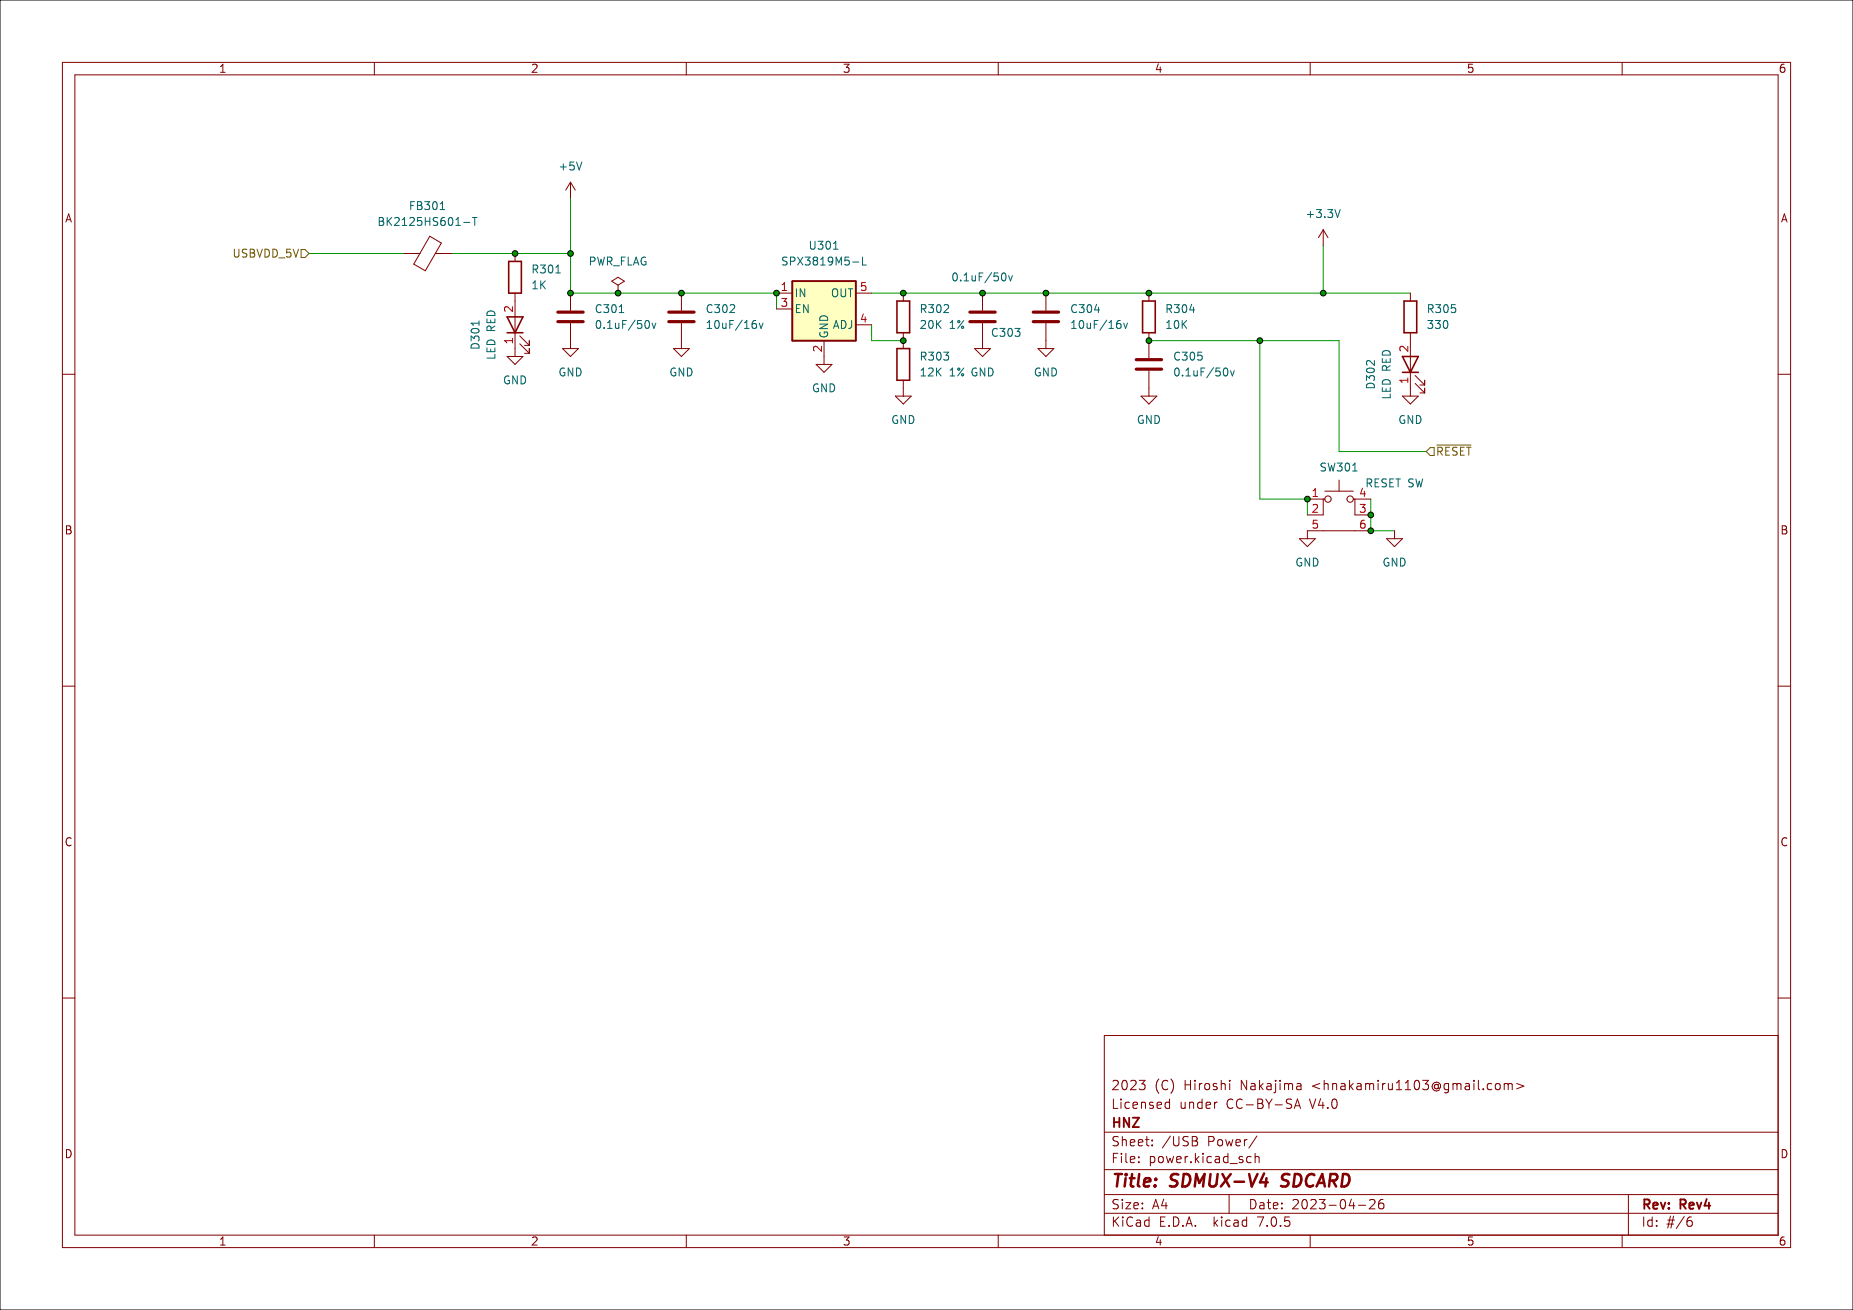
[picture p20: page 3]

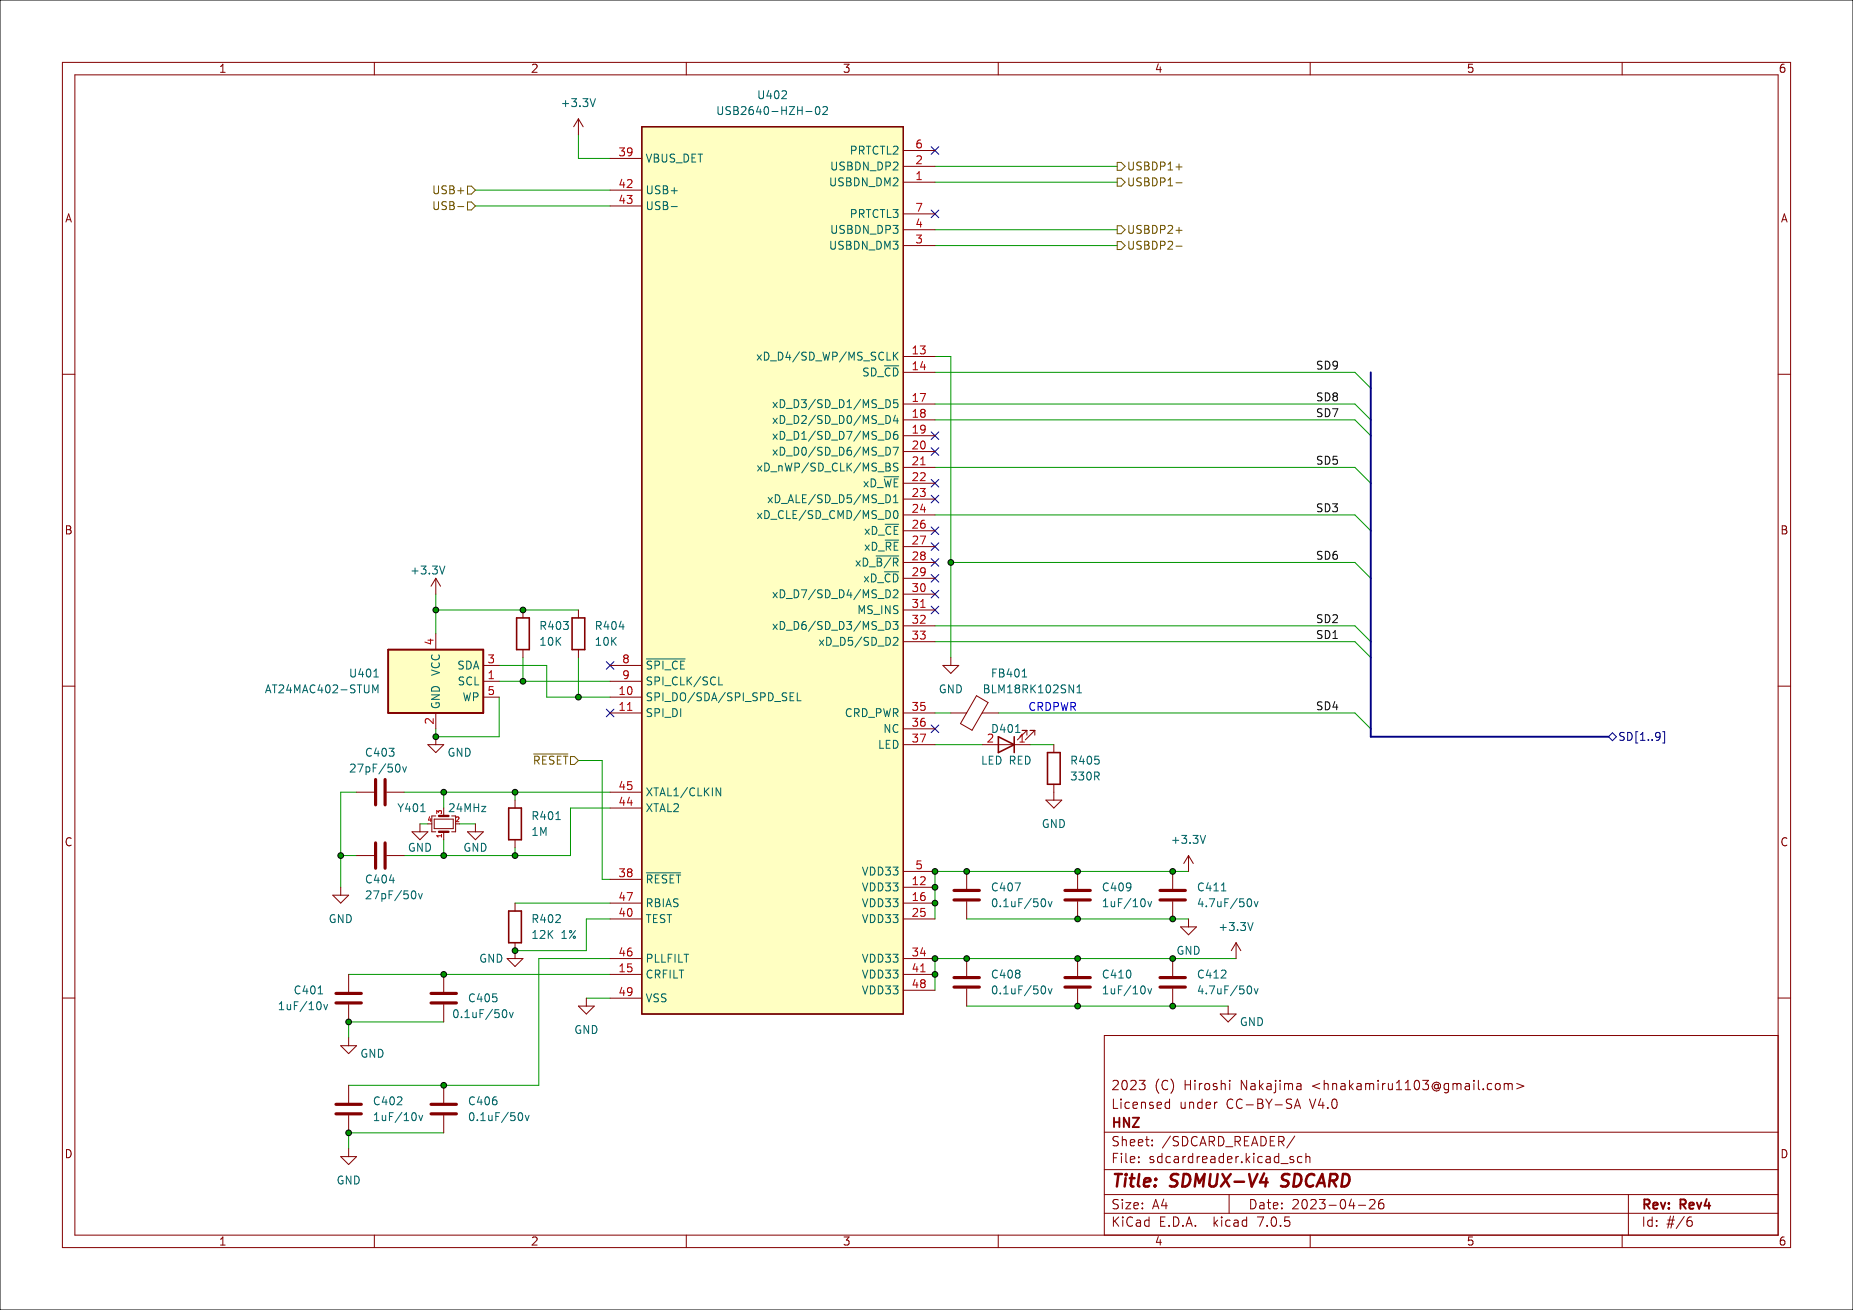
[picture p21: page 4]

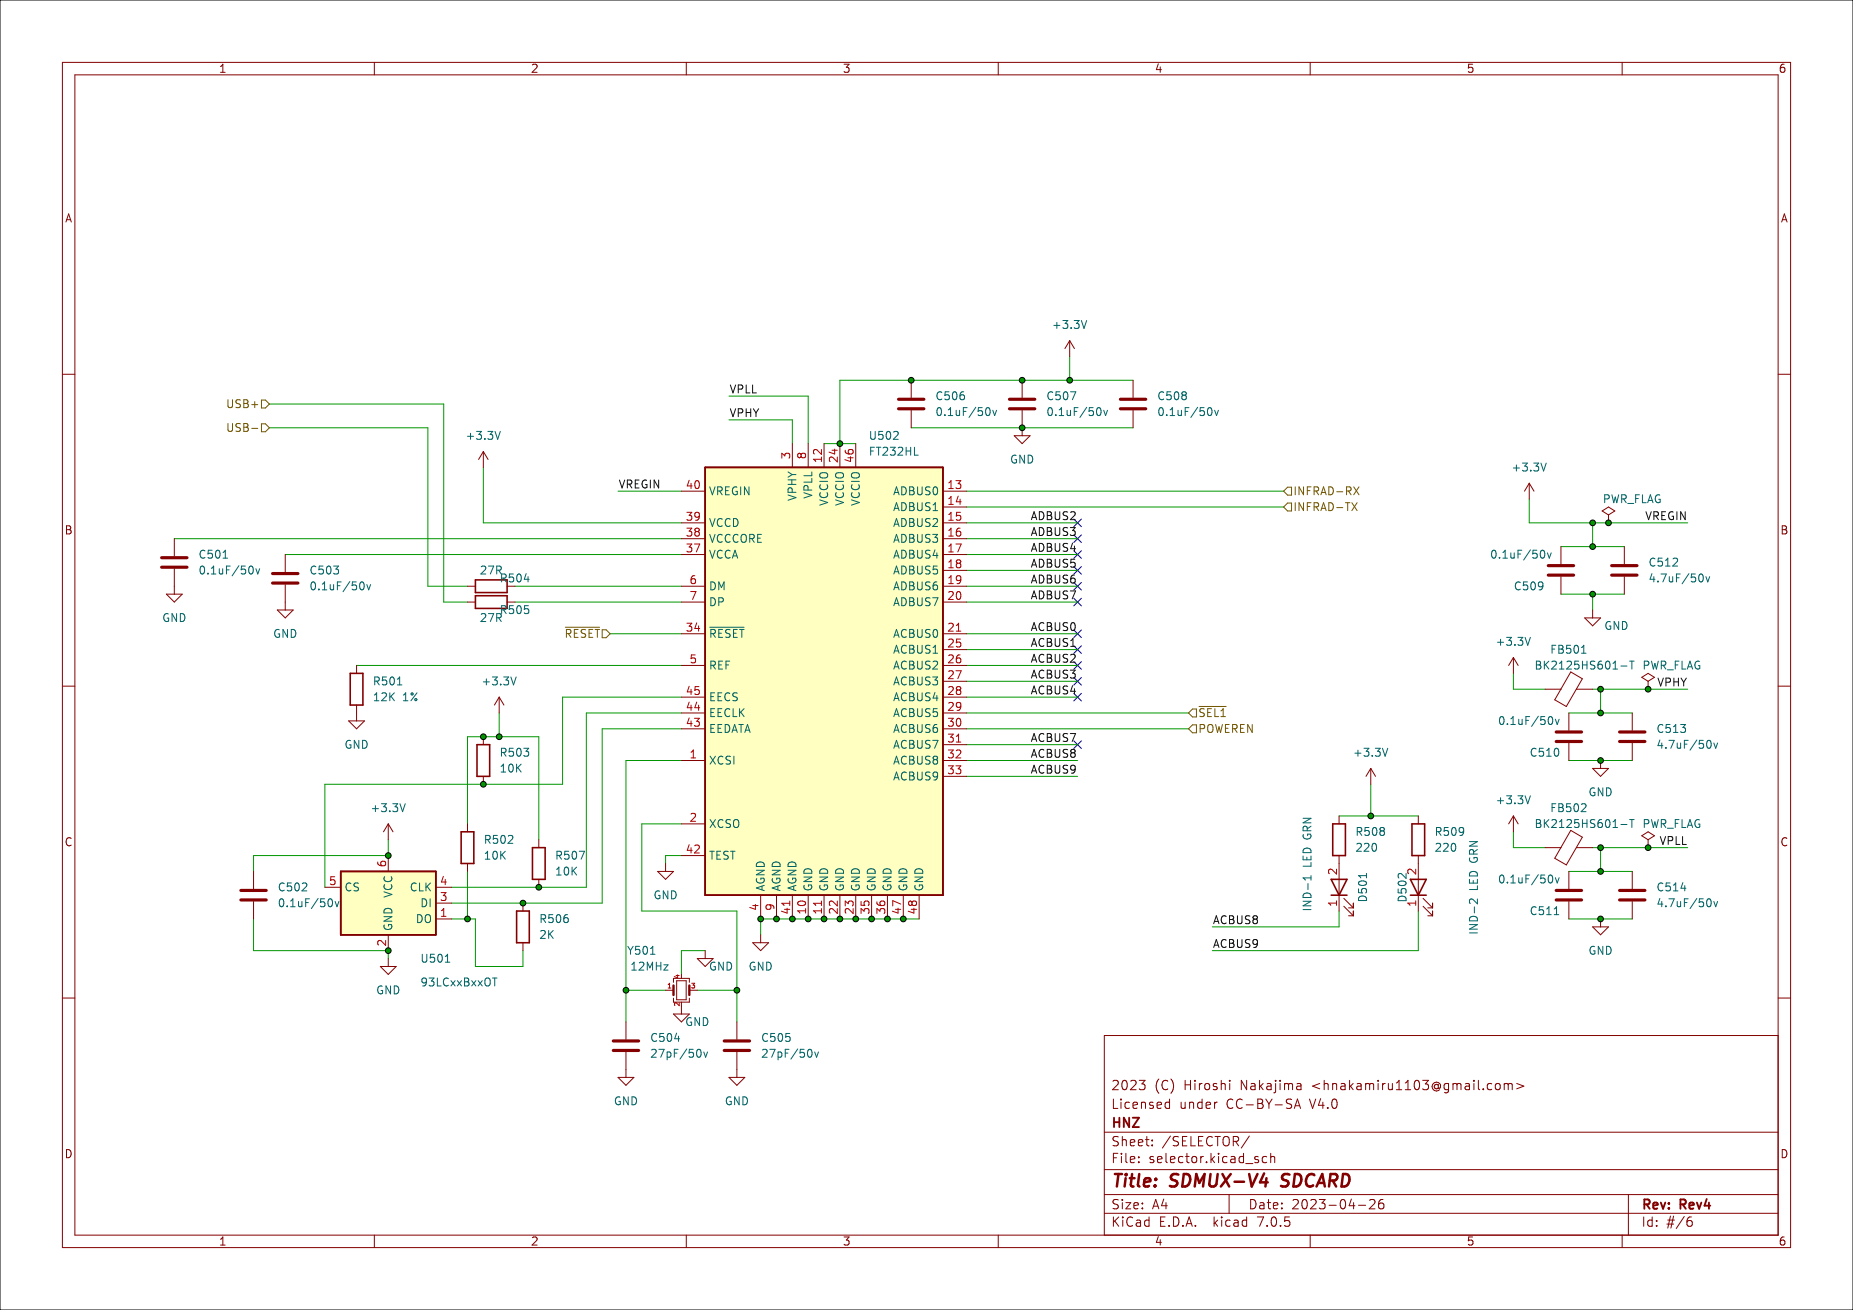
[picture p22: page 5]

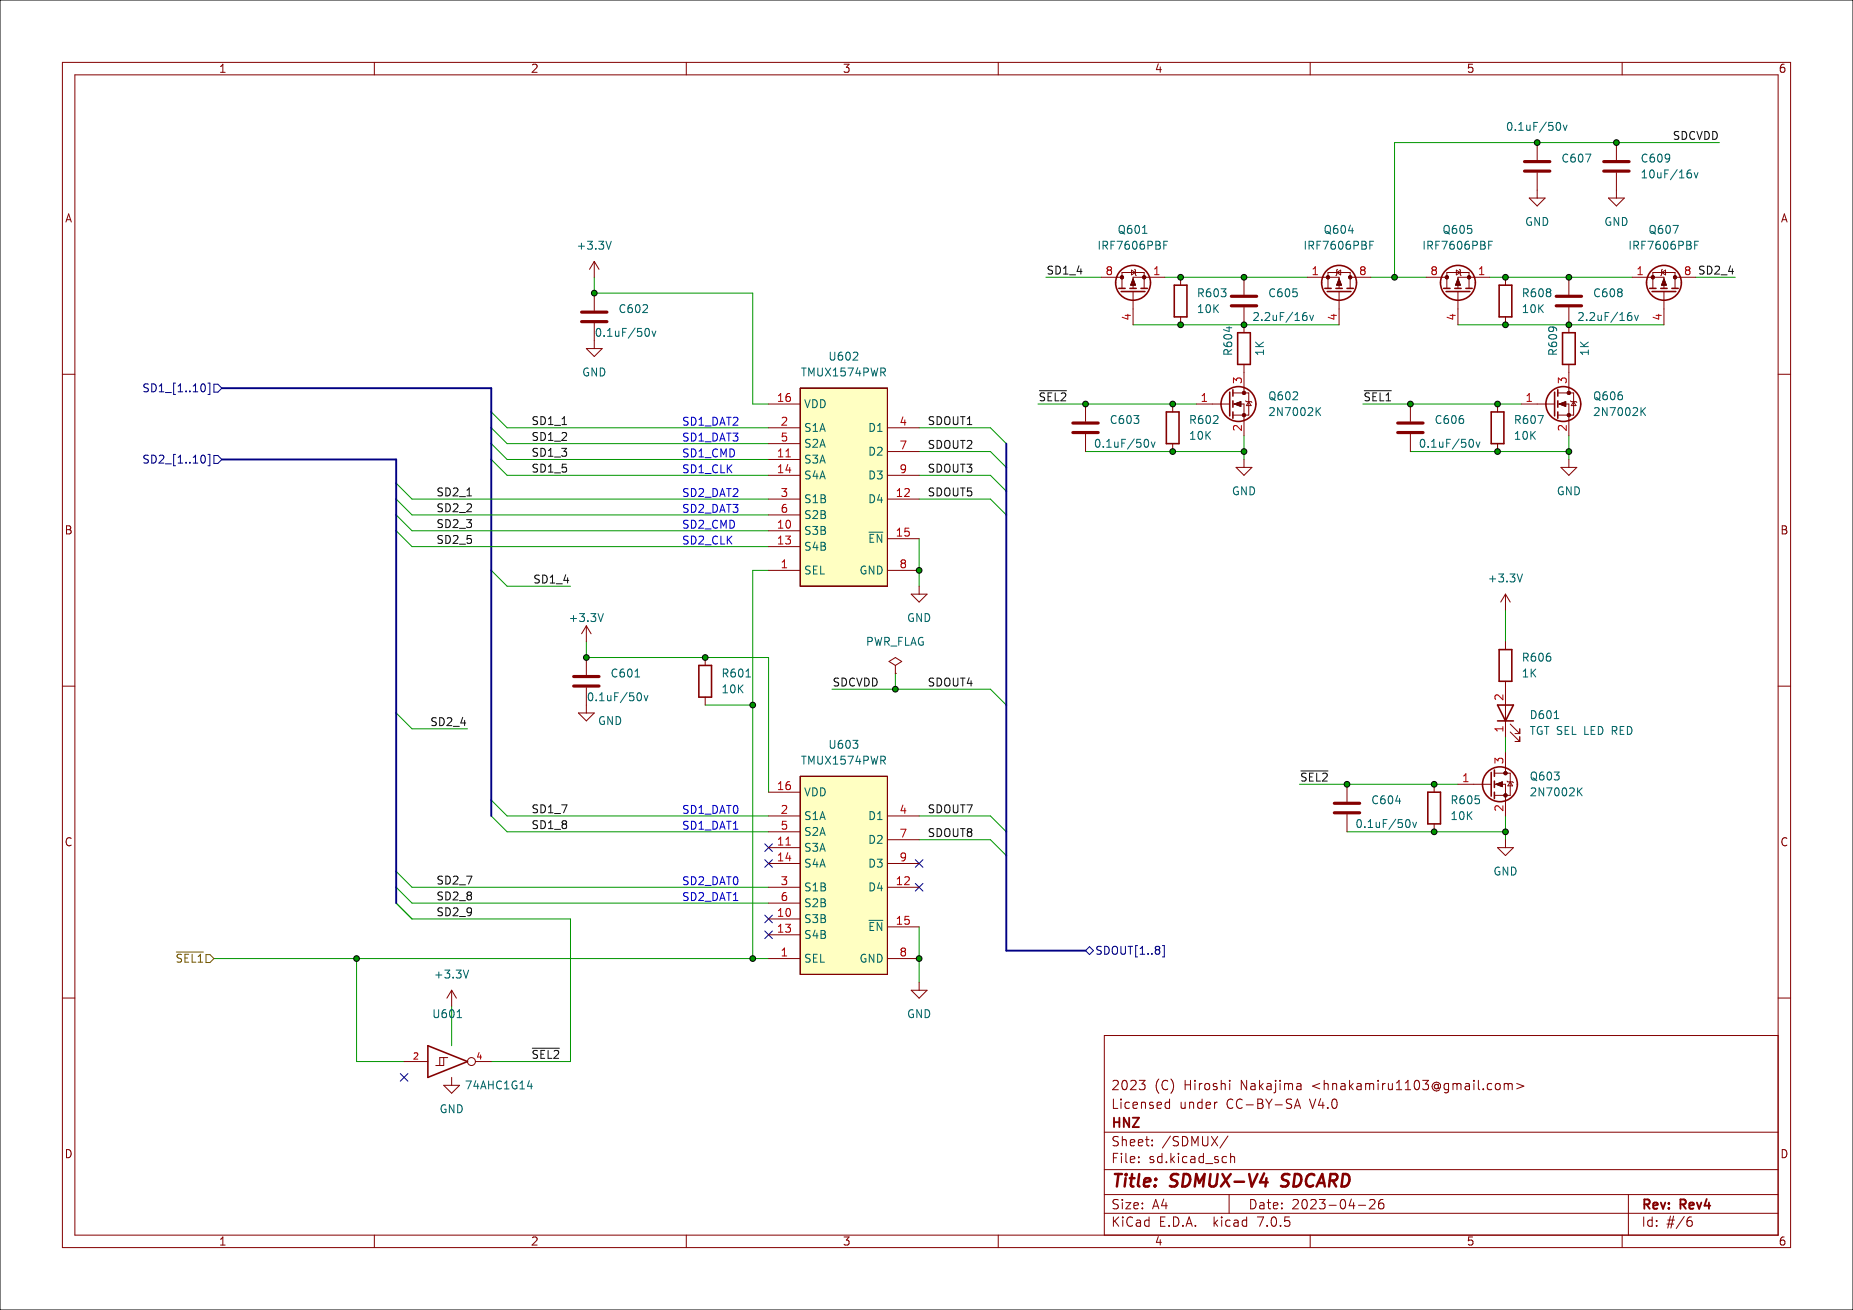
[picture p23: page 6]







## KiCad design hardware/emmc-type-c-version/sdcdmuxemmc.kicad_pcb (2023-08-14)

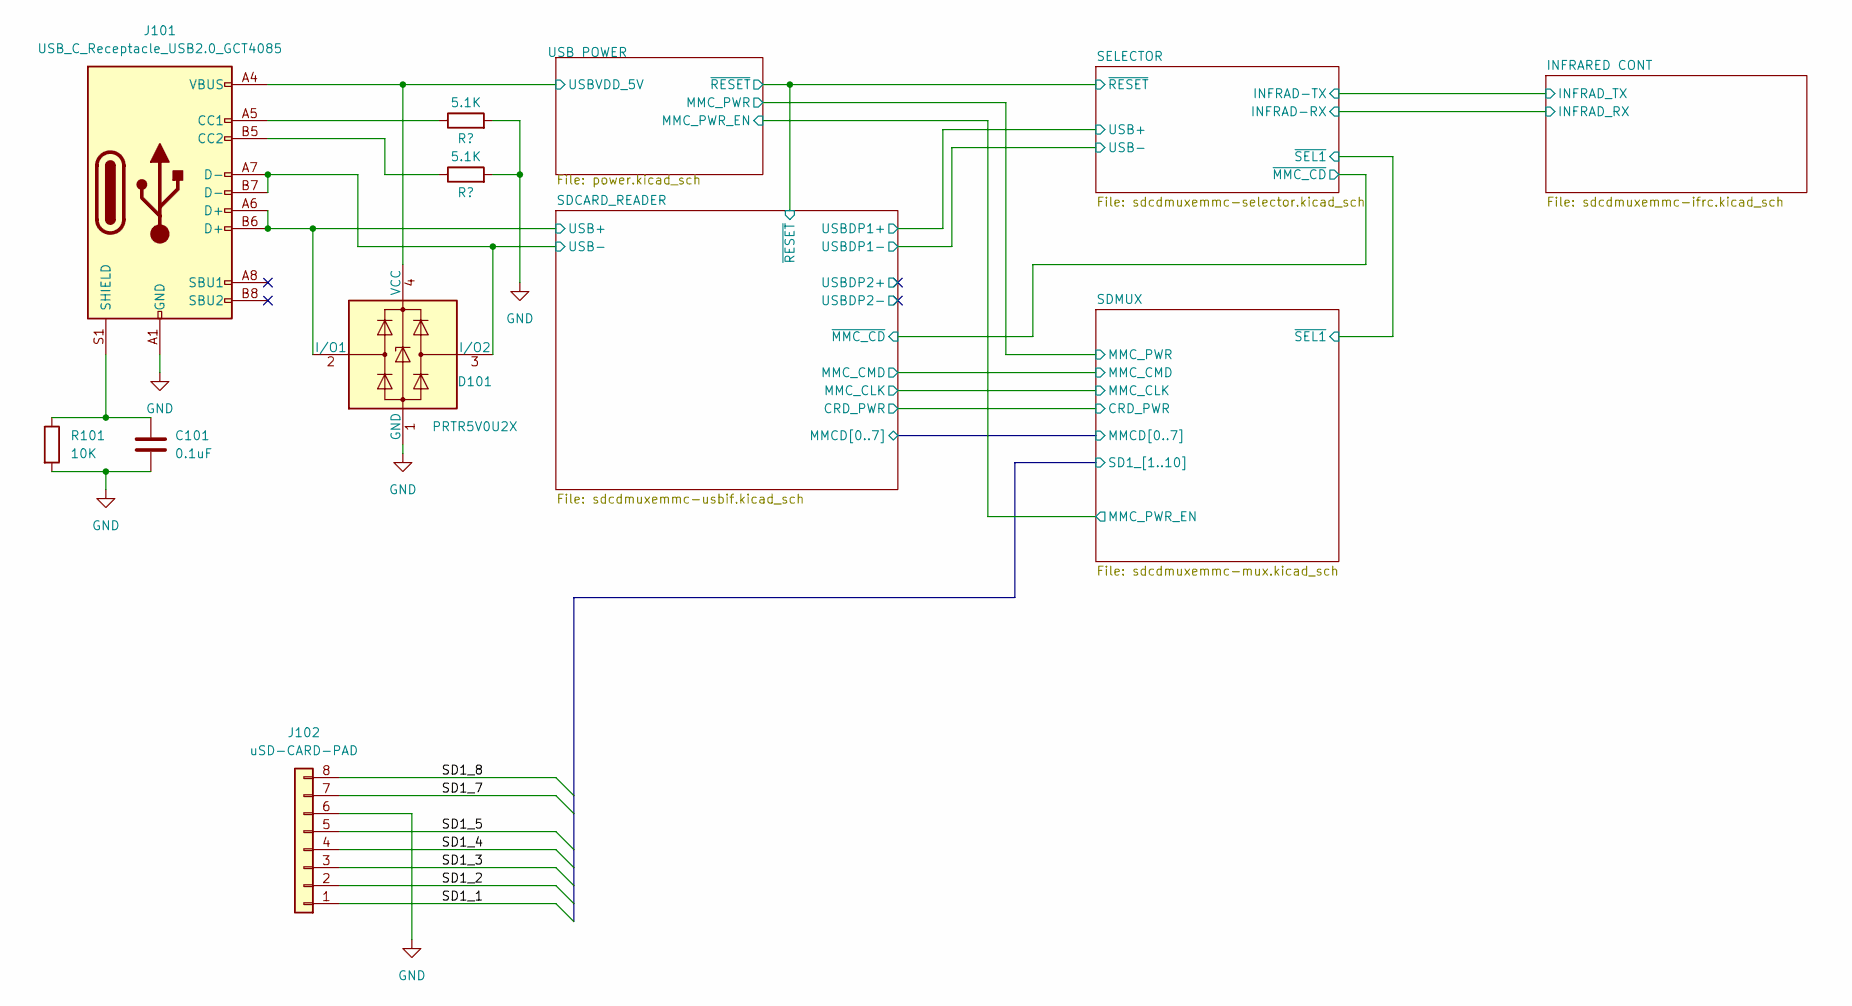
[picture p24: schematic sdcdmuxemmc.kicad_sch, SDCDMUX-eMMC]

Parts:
C101: 0.1uF; C_0603_1608Metric_Pad1.08x0.95mm_HandSolder; digikey 311-1824-1-ND
D101: PRTR5V0U2X; SOT-143; digikey 1727-3884-1-ND
J101: USB_C_Receptacle_USB2.0_GCT4085; USB_C_Receptacle_GCT_USB4085; digikey 2073-USB4085-GF-ACT-ND
J102: uSD-CARD-PAD; uSD Card Pad
R101: 10K; R_0805_2012Metric_Pad1.20x1.40mm_HandSolder; digikey 13-RC0603JR-1010KLCT-ND
R102, R103: 5.1K; R_0805_2012Metric_Pad1.20x1.40mm_HandSolder; digikey 13-RC0603JR-1010KLCT-ND

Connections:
/SDCARD_READER/USB+: D101.2 (I/O1), J101.A6 (D+), J101.B6 (D+); also elsewhere on the board
/SDCARD_READER/USB-: D101.3 (I/O2), J101.A7 (D-), J101.B7 (D-); also elsewhere on the board
/SDMUX/SD1_1: J102.1; also elsewhere on the board
/SDMUX/SD1_2: J102.2; also elsewhere on the board
/SDMUX/SD1_3: J102.3; also elsewhere on the board
/SDMUX/SD1_4: J102.4; also elsewhere on the board
/SDMUX/SD1_5: J102.5; also elsewhere on the board
/SDMUX/SD1_7: J102.7; also elsewhere on the board
/SDMUX/SD1_8: J102.8; also elsewhere on the board
/USB POWER/USBVDD_5V: D101.4 (VCC), J101.A4 (VBUS), J101.A9 (VBUS), J101.B4 (VBUS), J101.B9 (VBUS); also elsewhere on the board
GND: C101.2, D101.1 (GND), J101.A1 (GND), J101.A12 (GND), J101.B1 (GND), J101.B12 (GND), J102.6, R101.2, R102.2, R103.2; also elsewhere on the board
unnamed: J101.A5 (CC1), R102.1
unnamed: J101.B5 (CC2), R103.1
unnamed: C101.1, J101.S1 (SHIELD), R101.1

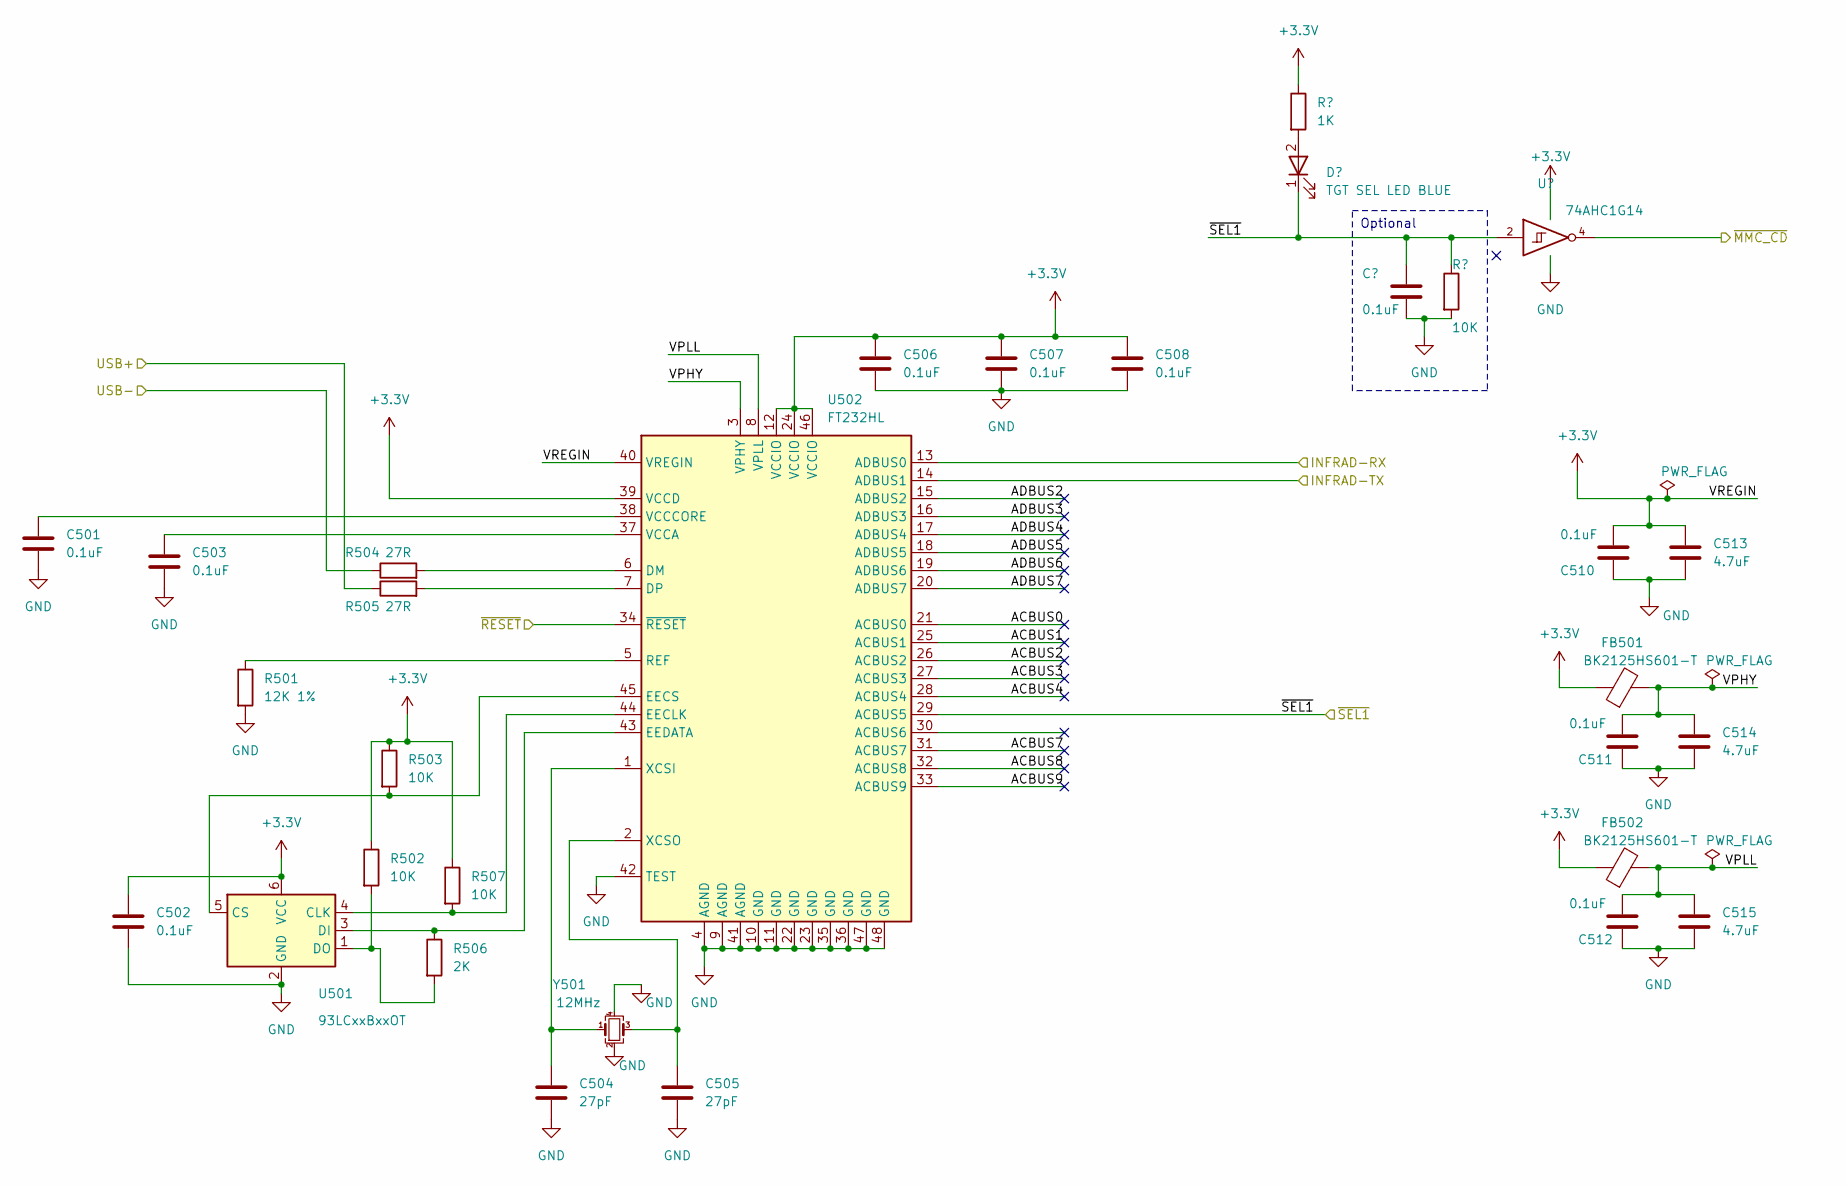
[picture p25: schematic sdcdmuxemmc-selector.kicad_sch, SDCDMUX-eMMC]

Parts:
C501, C502, C503, C506, C507, C508, C509, C510, C511, C512: 0.1uF; C_0603_1608Metric_Pad1.08x0.95mm_HandSolder; digikey 311-1824-1-ND
C504, C505: 27pF; C_0603_1608Metric_Pad1.08x0.95mm_HandSolder; digikey 311-1063-1-ND
C513, C514, C515: 4.7uF; C_0805_2012Metric_Pad1.18x1.45mm_HandSolder; digikey 311-1455-1-ND
D501: TGT SEL LED BLUE; LED_0603_1608Metric_Pad1.05x0.95mm_HandSolder; digikey 846-1177-1-ND
FB501, FB502: BK2125HS601-T; L_0805_2012Metric_Pad1.15x1.40mm_HandSolder; digikey 240-2399-1-ND
R501: 12K 1%; R_0805_2012Metric_Pad1.20x1.40mm_HandSolder; digikey 311-12.0KHRCT-ND
R502, R503, R507, R509: 10K; R_0805_2012Metric_Pad1.20x1.40mm_HandSolder; digikey 13-RC0603JR-1010KLCT-ND
R504, R505: 27R; R_0603_1608Metric_Pad0.98x0.95mm_HandSolder; digikey 311-27GRCT-ND
R506: 2K; R_0805_2012Metric_Pad1.20x1.40mm_HandSolder; digikey 311-2.0KGRCT-ND
R508: 1K; R_0805_2012Metric_Pad1.20x1.40mm_HandSolder; digikey 13-RC0603JR-101KLCT-ND
U501: 93LCxxBxxOT; SOT-23-6; digikey 93LC56BT-I/OTCT-ND
U502: FT232HL; LQFP-48_7x7mm_P0.5mm; digikey 768-1348-ND
U503: 74AHC1G14; SOT-23-5_HandSoldering; digikey 74AHC1G14W5-7DICT-ND
Y501: 12MHz; Crystal_SMD_3225-4Pin_3.2x2.5mm; digikey SER3682CT-ND

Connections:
+3.3V: C502.1, C506.1, C507.1, C508.1, C510.1, C513.1, FB501.1, FB502.1, R502.1, R503.1, R507.1, R508.1, U501.6 (VCC), U502.12 (VCCIO), U502.24 (VCCIO), U502.39 (VCCD), U502.40 (VREGIN), U502.46 (VCCIO), U503.5 (VCC); also elsewhere on the board
/INFRARED CONT/INFRAD_RX: U502.13 (ADBUS0); also elsewhere on the board
/INFRARED CONT/INFRAD_TX: U502.14 (ADBUS1); also elsewhere on the board
/SDCARD_READER/USBDP1+: R505.1; also elsewhere on the board
/SDCARD_READER/USBDP1-: R504.1; also elsewhere on the board
/SDCARD_READER/~MMC_CD: U503.4; also elsewhere on the board
/SDCARD_READER/~RESET: U502.34 (~RESET); also elsewhere on the board
/SELECTOR/ACBUS0: U502.21 (ACBUS0)
/SELECTOR/ACBUS1: U502.25 (ACBUS1)
/SELECTOR/ACBUS2: U502.26 (ACBUS2)
/SELECTOR/ACBUS3: U502.27 (ACBUS3)
/SELECTOR/ACBUS4: U502.28 (ACBUS4)
/SELECTOR/ACBUS7: U502.31 (ACBUS7)
/SELECTOR/ACBUS8: U502.32 (ACBUS8)
/SELECTOR/ACBUS9: U502.33 (ACBUS9)
/SELECTOR/ADBUS2: U502.15 (ADBUS2)
/SELECTOR/ADBUS3: U502.16 (ADBUS3)
/SELECTOR/ADBUS4: U502.17 (ADBUS4)
/SELECTOR/ADBUS5: U502.18 (ADBUS5)
/SELECTOR/ADBUS6: U502.19 (ADBUS6)
/SELECTOR/ADBUS7: U502.20 (ADBUS7)
/SELECTOR/VPHY: C511.1, C514.1, FB501.2, U502.3 (VPHY)
/SELECTOR/VPLL: C512.1, C515.1, FB502.2, U502.8 (VPLL)
/SELECTOR/~SEL1: C509.1, D501.1 (K), R509.1, U502.29 (ACBUS5), U503.2; also elsewhere on the board
GND: C501.2, C502.2, C503.2, C504.2, C505.2, C506.2, C507.2, C508.2, C509.2, C510.2, C511.2, C512.2, C513.2, C514.2, C515.2, R501.2, R509.2, U501.2 (GND), U502.4 (AGND), U502.9 (AGND), U502.10 (GND), U502.11 (GND), U502.22 (GND), U502.23 (GND), U502.35 (GND), U502.36 (GND), U502.41 (AGND), U502.42 (TEST), U502.47 (GND), U502.48 (GND), U503.3 (GND), Y501.2, Y501.4; also elsewhere on the board
unnamed: D501.2 (A), R508.2
unnamed: R507.2, U501.4 (CLK), U502.44 (EECLK)
unnamed: R503.2, U501.5 (CS), U502.45 (EECS)
unnamed: R506.1, U501.3 (DI), U502.43 (EEDATA)
unnamed: R502.2, R506.2, U501.1 (DO)
unnamed: R504.2, U502.6 (DM)
unnamed: R505.2, U502.7 (DP)
unnamed: R501.1, U502.5 (REF)
unnamed: C503.1, U502.37 (VCCA)
unnamed: C501.1, U502.38 (VCCCORE)
unnamed: C504.1, U502.1 (XCSI), Y501.1
unnamed: C505.1, U502.2 (XCSO), Y501.3

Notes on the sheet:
Optional

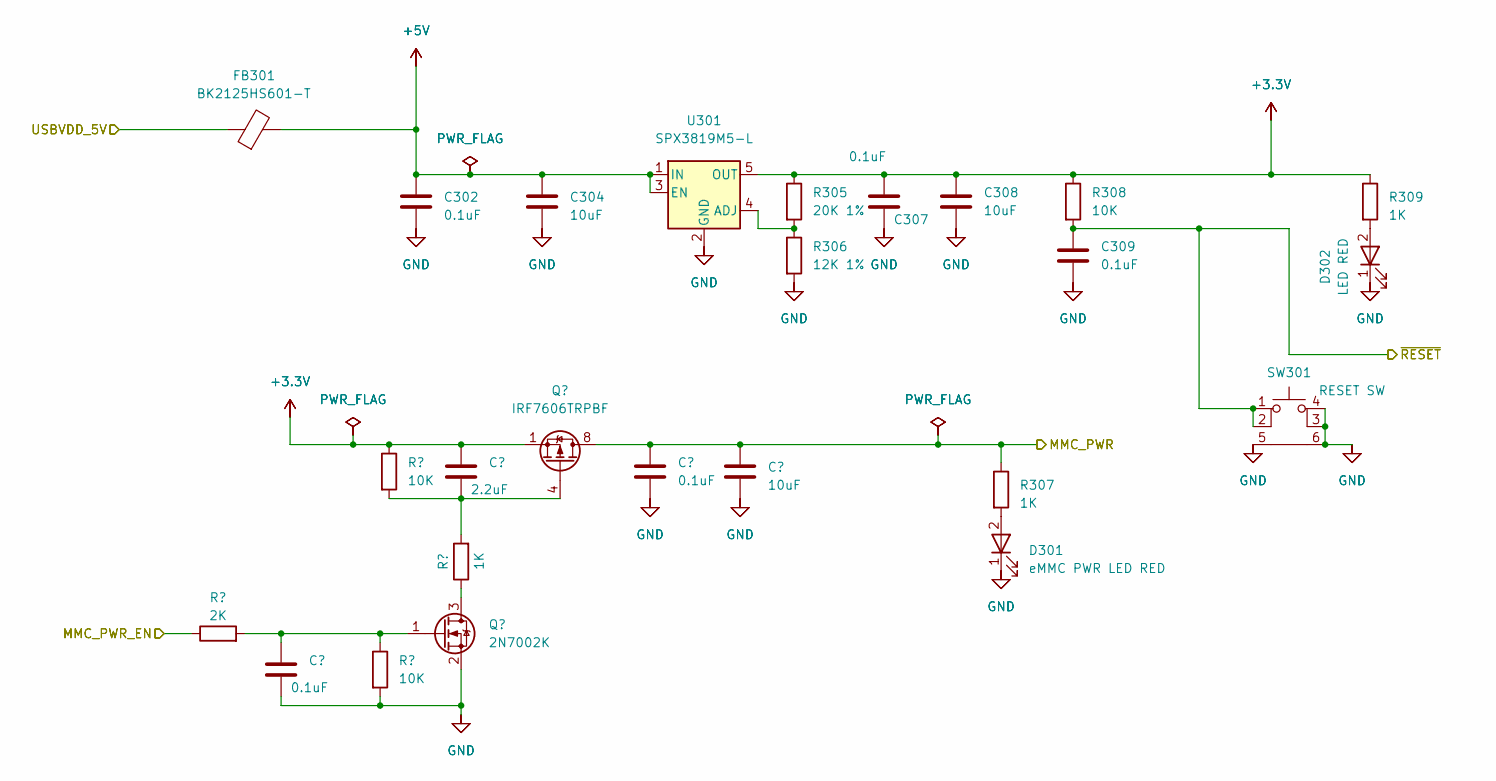
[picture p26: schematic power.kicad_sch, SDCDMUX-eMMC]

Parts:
C301, C302, C305, C307, C309: 0.1uF; C_0603_1608Metric_Pad1.08x0.95mm_HandSolder; digikey 311-1824-1-ND
C303: 2.2uF; C_0603_1608Metric_Pad1.08x0.95mm_HandSolder; digikey 311-1795-1-ND
C304, C306, C308: 10uF; C_0805_2012Metric_Pad1.18x1.45mm_HandSolder; digikey 311-3494-1-ND
D301: eMMC PWR LED RED; LED_0603_1608Metric_Pad1.05x0.95mm_HandSolder; digikey 511-1587-1-ND
D302: LED RED; LED_0603_1608Metric_Pad1.05x0.95mm_HandSolder; digikey 511-1587-1-ND
FB301: BK2125HS601-T; L_0603_1608Metric_Pad1.05x0.95mm_HandSolder; digikey 240-2399-1-ND
Q301: 2N7002K; SOT-23; digikey 2N7002K-7DICT-ND
Q302: IRF7606TRPBF; MSOP-8_3x3mm_P0.65mm; digikey IRF7606TRPBFCT-ND
R301: 2K; R_0805_2012Metric_Pad1.20x1.40mm_HandSolder; digikey 311-2.0KGRCT-ND
R302, R303, R308: 10K; R_0805_2012Metric_Pad1.20x1.40mm_HandSolder; digikey 13-RC0603JR-1010KLCT-ND
R304, R307, R309: 1K; R_0805_2012Metric_Pad1.20x1.40mm_HandSolder; digikey 13-RC0603JR-101KLCT-ND
R305: 20K 1%; R_0805_2012Metric_Pad1.20x1.40mm_HandSolder; digikey 13-RC0603FR-1320KLCT-ND
R306: 12K 1%; R_0805_2012Metric_Pad1.20x1.40mm_HandSolder; digikey 311-12.0KHRCT-ND
SW301: RESET SW; WS-TASV SMT Tact Switch; digikey 732-435151014824CT-ND
U301: SPX3819M5-L; SOT-23-5; digikey 1016-1871-1-ND

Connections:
+3.3V: C303.1, C307.1, C308.1, Q302.1 (S), Q302.2 (S), Q302.3 (S), R303.1, R305.1, R308.1, R309.1, U301.5 (OUT); also elsewhere on the board
+5V: C302.1, C304.1, FB301.2, U301.1 (IN), U301.3 (EN); also elsewhere on the board
/SDCARD_READER/~RESET: C309.1, R308.2, SW301.1, SW301.2; also elsewhere on the board
/SDMUX/MMC_PWR: C305.1, C306.1, Q302.5 (D), Q302.6 (D), Q302.7 (D), Q302.8 (D), R307.1; also elsewhere on the board
/SDMUX/MMC_PWR_EN: R301.1; also elsewhere on the board
/USB POWER/USBVDD_5V: FB301.1; also elsewhere on the board
GND: C301.2, C302.2, C304.2, C305.2, C306.2, C307.2, C308.2, C309.2, D301.1 (K), D302.1 (K), Q301.2 (S), R302.2, R306.2, SW301.3 (K), SW301.4 (A), SW301.5, SW301.6, U301.2 (GND); also elsewhere on the board
unnamed: D301.2 (A), R307.2
unnamed: D302.2 (A), R309.2
unnamed: Q301.3 (D), R304.1
unnamed: C301.1, Q301.1 (G), R301.2, R302.1
unnamed: C303.2, Q302.4 (G), R303.2, R304.2
unnamed: R305.2, R306.1, U301.4 (ADJ)

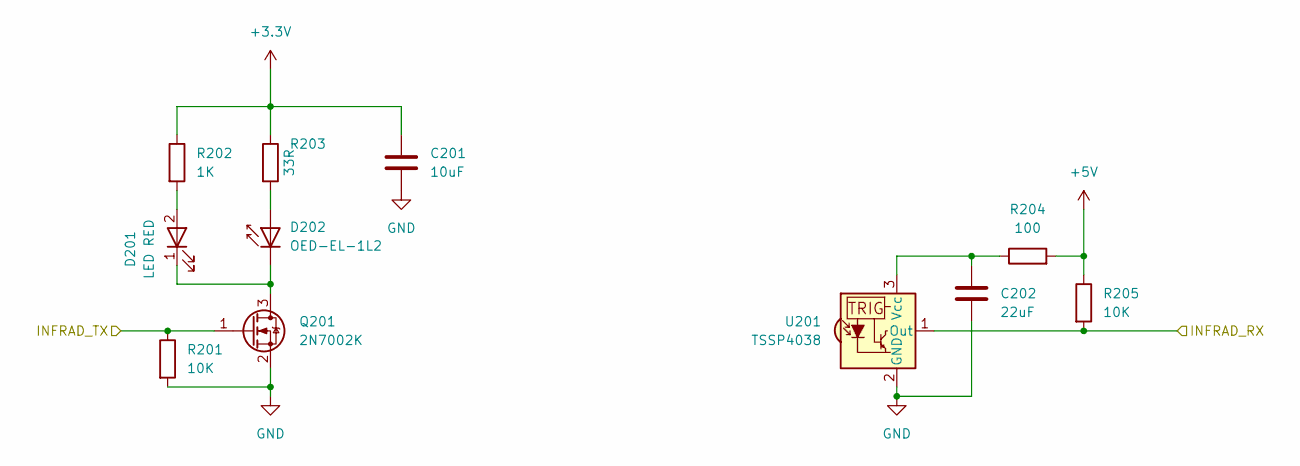
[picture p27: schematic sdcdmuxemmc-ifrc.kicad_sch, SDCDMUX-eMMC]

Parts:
C201: 10uF; C_0805_2012Metric_Pad1.18x1.45mm_HandSolder; digikey 311-3494-1-ND
C202: 22uF; C_0805_2012Metric_Pad1.18x1.45mm_HandSolder; digikey 311-3494-1-ND
D201: LED RED; LED_0603_1608Metric_Pad1.05x0.95mm_HandSolder; digikey 511-1587-1-ND
D202: OED-EL-1L2; LED_D5.0mm; digikey 67-1001-ND
Q201: 2N7002K; SOT-23; digikey 2N7002K-7DICT-ND
R201, R205: 10K; R_0805_2012Metric_Pad1.20x1.40mm_HandSolder; digikey 13-RC0603JR-1010KLCT-ND
R202: 1K; R_0805_2012Metric_Pad1.20x1.40mm_HandSolder; digikey 13-RC0603JR-101KLCT-ND
R203: 33R; R_0603_1608Metric_Pad0.98x0.95mm_HandSolder; digikey 311-33GRCT-ND
R204: 100; R_0805_2012Metric_Pad1.20x1.40mm_HandSolder; digikey 13-RC0603JR-1010KLCT-ND
U201: TSSP4038; digikey TSSP4038-ND

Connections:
+3.3V: C201.1, R202.1, R203.1; also elsewhere on the board
+5V: R204.2, R205.1; also elsewhere on the board
/INFRARED CONT/INFRAD_RX: R205.2, U201.1 (Out); also elsewhere on the board
/INFRARED CONT/INFRAD_TX: Q201.1 (G), R201.1; also elsewhere on the board
GND: C201.2, C202.2, Q201.2 (S), R201.2, U201.2 (GND); also elsewhere on the board
unnamed: D201.2 (A), R202.2
unnamed: D201.1 (K), D202.1 (K), Q201.3 (D)
unnamed: D202.2 (A), R203.2
unnamed: C202.1, R204.1, U201.3 (Vcc)

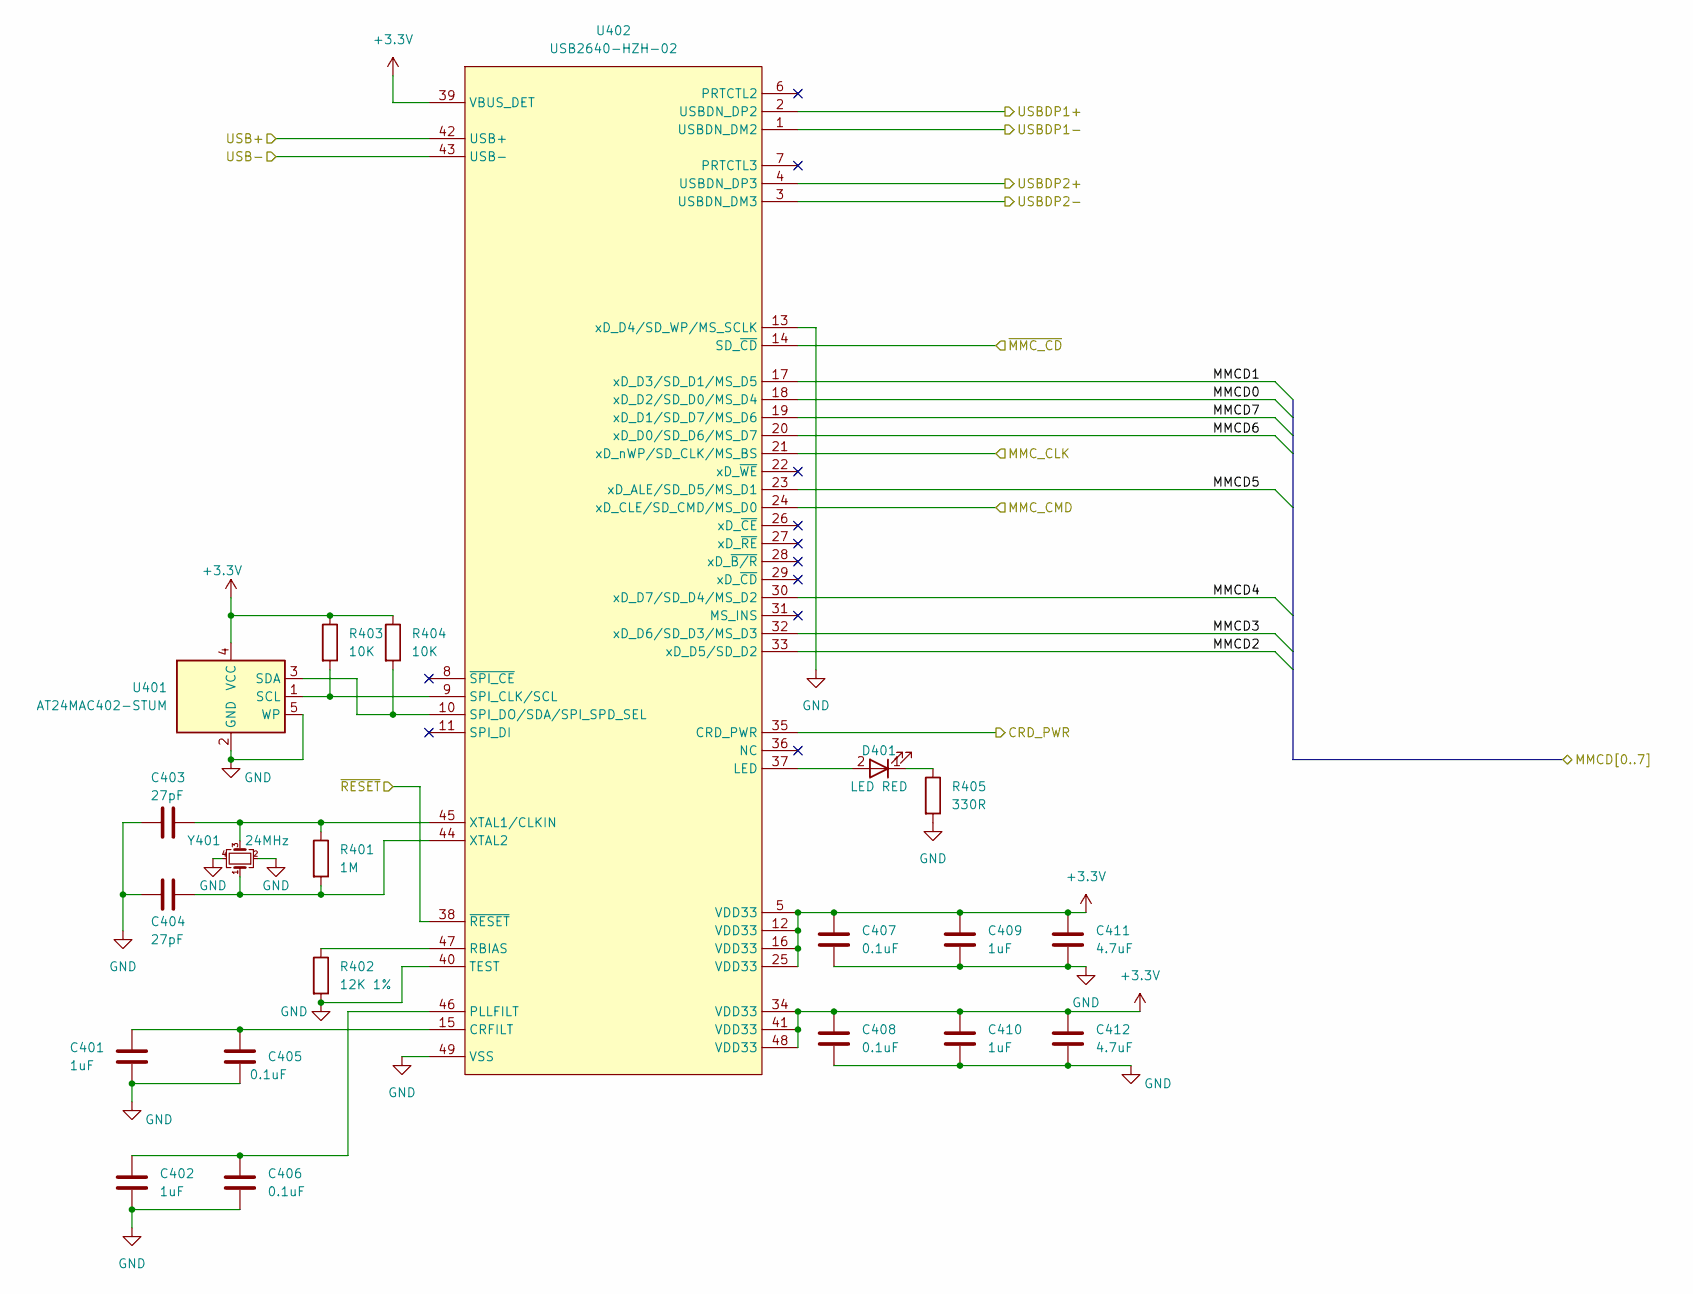
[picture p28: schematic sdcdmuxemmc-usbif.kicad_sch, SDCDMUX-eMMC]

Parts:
C401, C402, C409, C410: 1uF; C_0805_2012Metric_Pad1.18x1.45mm_HandSolder; digikey 13-CC0603KPX7R7BB105CT-ND
C403, C404: 27pF; C_0603_1608Metric; digikey 311-1063-1-ND
C405, C406, C407, C408: 0.1uF; C_0603_1608Metric_Pad1.08x0.95mm_HandSolder; digikey 311-1824-1-ND
C411, C412: 4.7uF; C_0805_2012Metric_Pad1.18x1.45mm_HandSolder; digikey 311-1455-1-ND
D401: LED RED; LED_0603_1608Metric_Pad1.05x0.95mm_HandSolder; digikey 511-1587-1-ND
R401: 1M; R_0805_2012Metric_Pad1.20x1.40mm_HandSolder; digikey 311-1.0MGRCT-ND
R402: 12K 1%; R_0805_2012Metric_Pad1.20x1.40mm_HandSolder; digikey 311-12.0KHRCT-ND
R403, R404: 10K; R_0805_2012Metric_Pad1.20x1.40mm_HandSolder; digikey 13-RC0603JR-1010KLCT-ND
R405: 330R; R_0805_2012Metric_Pad1.20x1.40mm_HandSolder; digikey 311-330GRCT-ND
U401: AT24MAC402-STUM; SOT-23-5_HandSoldering; digikey AT24MAC402-STUM-TCT-ND
U402: USB2640-HZH-02; QFN-48-1EP_7x7mm_P0.5mm_EP5.15x5.15mm; digikey USB2640-HZH-02-ND
Y401: 24MHz; Crystal_SMD_2016-4Pin_2.0x1.6mm; digikey XC3064CT-ND

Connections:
+3.3V: C407.1, C408.1, C409.1, C410.1, C411.1, C412.1, R403.1, R404.1, U401.4 (VCC), U402.5 (VDD33), U402.12 (VDD33), U402.16 (VDD33), U402.25 (VDD33), U402.34 (VDD33), U402.39 (VBUS_DET), U402.41 (VDD33), U402.48 (VDD33); also elsewhere on the board
/SDCARD_READER/CRD_PWR: U402.35 (CRD_PWR); also elsewhere on the board
/SDCARD_READER/MMCD0: U402.18 (xD_D2/SD_D0/MS_D4); also elsewhere on the board
/SDCARD_READER/MMCD1: U402.17 (xD_D3/SD_D1/MS_D5); also elsewhere on the board
/SDCARD_READER/MMCD2: U402.33 (xD_D5/SD_D2); also elsewhere on the board
/SDCARD_READER/MMCD3: U402.32 (xD_D6/SD_D3/MS_D3); also elsewhere on the board
/SDCARD_READER/MMCD4: U402.30 (xD_D7/SD_D4/MS_D2); also elsewhere on the board
/SDCARD_READER/MMCD5: U402.23 (xD_ALE/SD_D5/MS_D1); also elsewhere on the board
/SDCARD_READER/MMCD6: U402.20 (xD_D0/SD_D6/MS_D7); also elsewhere on the board
/SDCARD_READER/MMCD7: U402.19 (xD_D1/SD_D7/MS_D6); also elsewhere on the board
/SDCARD_READER/MMC_CLK: U402.21 (xD_nWP/SD_CLK/MS_BS); also elsewhere on the board
/SDCARD_READER/MMC_CMD: U402.24 (xD_CLE/SD_CMD/MS_D0); also elsewhere on the board
/SDCARD_READER/USB+: U402.42 (USB+); also elsewhere on the board
/SDCARD_READER/USB-: U402.43 (USB-); also elsewhere on the board
/SDCARD_READER/USBDP1+: U402.2 (USBDN_DP2); also elsewhere on the board
/SDCARD_READER/USBDP1-: U402.1 (USBDN_DM2); also elsewhere on the board
/SDCARD_READER/USBDP2+: U402.4 (USBDN_DP3)
/SDCARD_READER/USBDP2-: U402.3 (USBDN_DM3)
/SDCARD_READER/~MMC_CD: U402.14 (SD_~CD); also elsewhere on the board
/SDCARD_READER/~RESET: U402.38 (~RESET); also elsewhere on the board
GND: C401.2, C402.2, C403.1, C404.1, C405.2, C406.2, C407.2, C408.2, C409.2, C410.2, C411.2, C412.2, R402.2, R405.2, U401.2 (GND), U401.5 (WP), U402.13 (xD_D4/SD_WP/MS_SCLK), U402.40 (TEST), U402.49 (VSS), Y401.2, Y401.4; also elsewhere on the board
unnamed: D401.2 (A), U402.37 (LED)
unnamed: D401.1 (K), R405.1
unnamed: R403.2, U401.1 (SCL), U402.9 (SPI_CLK/SCL)
unnamed: R404.2, U401.3 (SDA), U402.10 (SPI_DO/SDA/SPI_SPD_SEL)
unnamed: C401.1, C405.1, U402.15 (CRFILT)
unnamed: C402.1, C406.1, U402.46 (PLLFILT)
unnamed: R402.1, U402.47 (RBIAS)
unnamed: C403.2, R401.1, U402.45 (XTAL1/CLKIN), Y401.3
unnamed: C404.2, R401.2, U402.44 (XTAL2), Y401.1

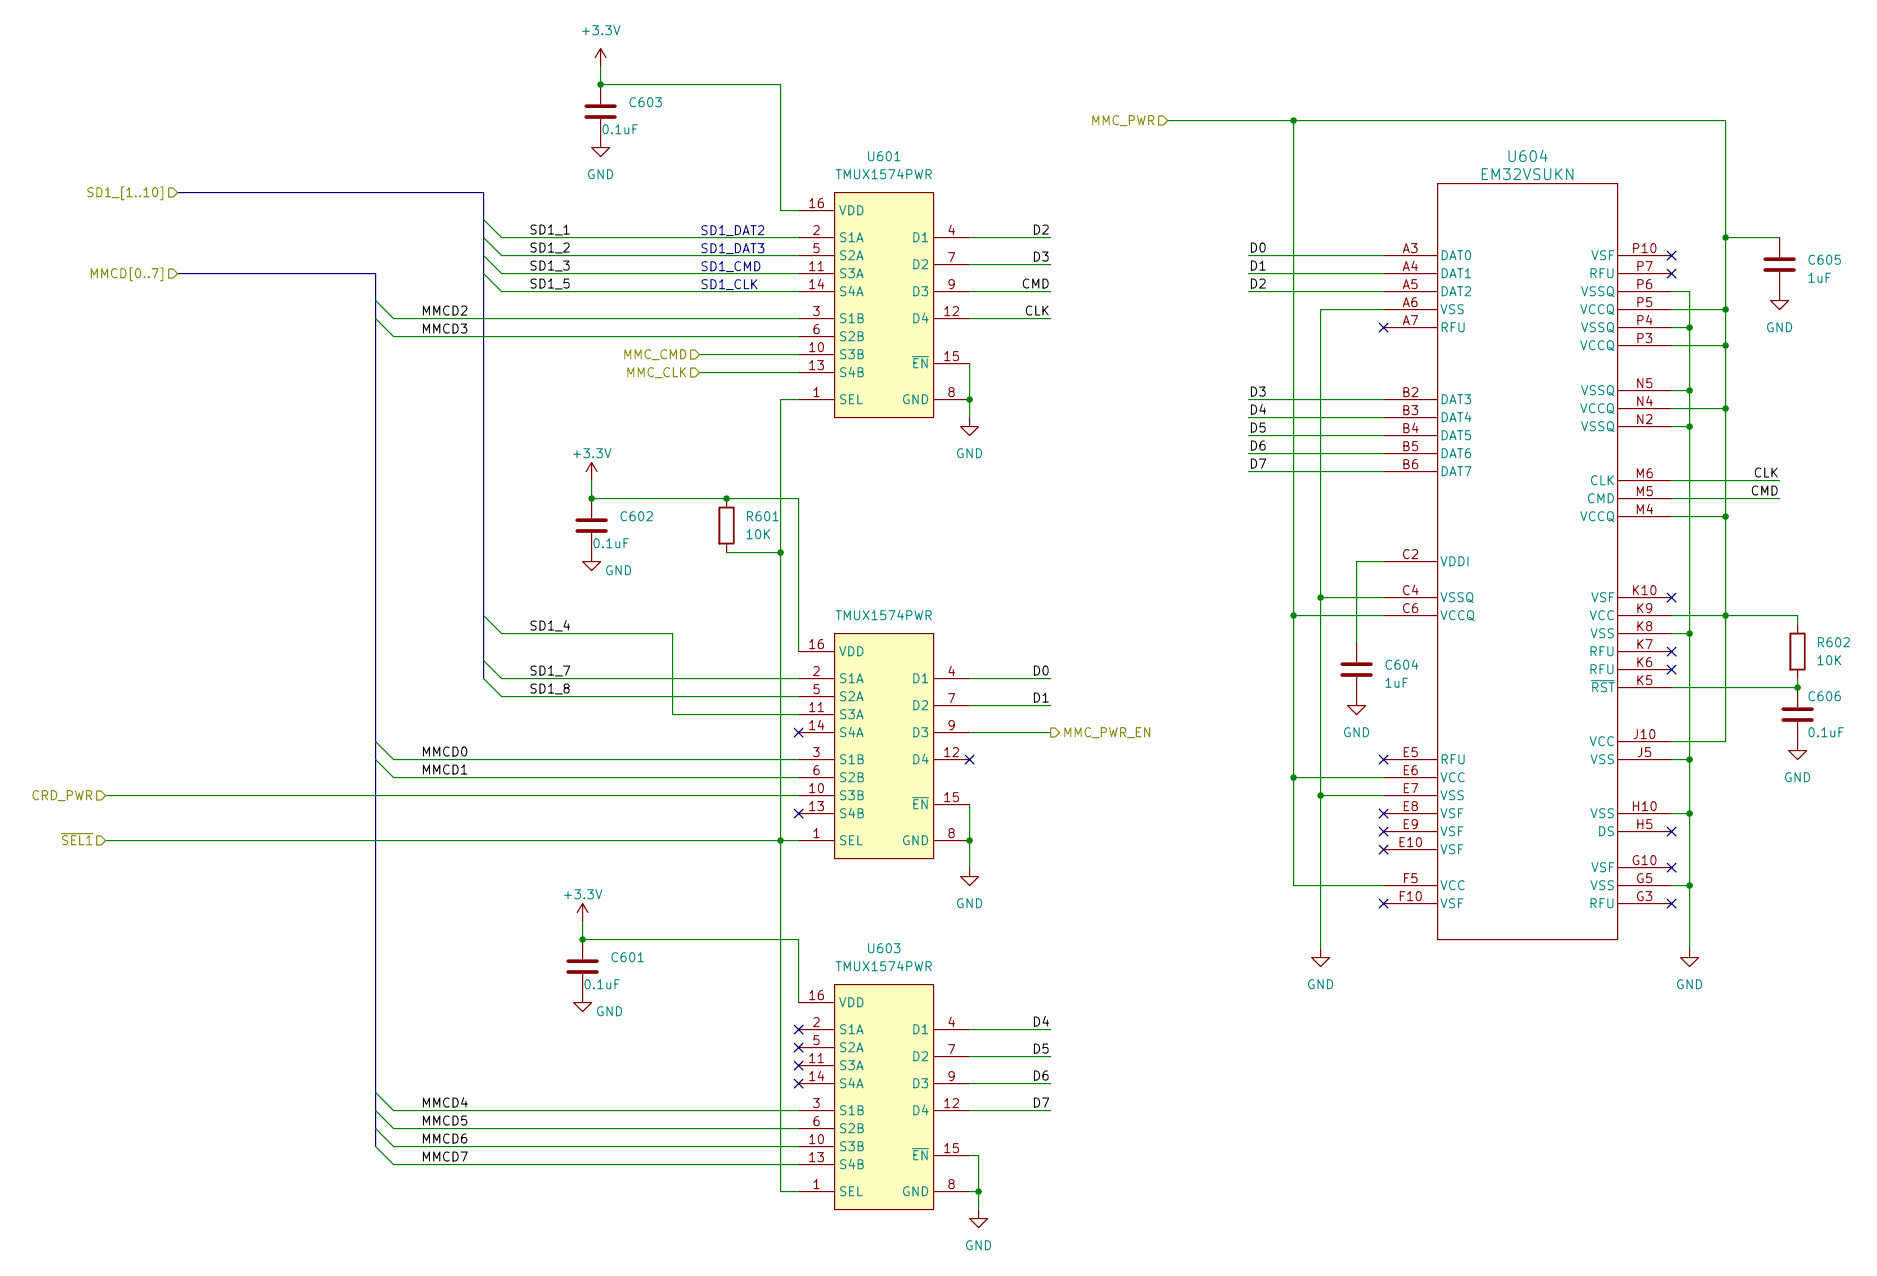
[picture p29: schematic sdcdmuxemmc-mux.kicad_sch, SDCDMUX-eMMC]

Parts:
C601, C602, C603, C606: 0.1uF; C_0603_1608Metric_Pad1.08x0.95mm_HandSolder; digikey 311-1824-1-ND
C604, C605: 1uF; C_0805_2012Metric; digikey 13-CC0603KPX7R7BB105CT-ND
R601, R602: 10K; R_0805_2012Metric_Pad1.20x1.40mm_HandSolder; digikey 13-RC0603JR-1010KLCT-ND
U601, U602, U603: TMUX1574PWR; TSSOP-16_4.4x5mm_P0.65mm; digikey 296-53444-1-ND
U604: EM32VSUKN; EM32VSUKN FPGA153; digikey 3247-EM32VSUKN-BA000-2-ND

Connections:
+3.3V: C601.1, C602.1, C603.1, R601.1, U601.16 (VDD), U602.16 (VDD), U603.16 (VDD); also elsewhere on the board
/SDCARD_READER/CRD_PWR: U602.10 (S3B); also elsewhere on the board
/SDCARD_READER/MMCD0: U602.3 (S1B); also elsewhere on the board
/SDCARD_READER/MMCD1: U602.6 (S2B); also elsewhere on the board
/SDCARD_READER/MMCD2: U601.3 (S1B); also elsewhere on the board
/SDCARD_READER/MMCD3: U601.6 (S2B); also elsewhere on the board
/SDCARD_READER/MMCD4: U603.3 (S1B); also elsewhere on the board
/SDCARD_READER/MMCD5: U603.6 (S2B); also elsewhere on the board
/SDCARD_READER/MMCD6: U603.10 (S3B); also elsewhere on the board
/SDCARD_READER/MMCD7: U603.13 (S4B); also elsewhere on the board
/SDCARD_READER/MMC_CLK: U601.13 (S4B); also elsewhere on the board
/SDCARD_READER/MMC_CMD: U601.10 (S3B); also elsewhere on the board
/SDMUX/CLK: U601.12 (D4), U604.M6 (CLK)
/SDMUX/CMD: U601.9 (D3), U604.M5 (CMD)
/SDMUX/D0: U602.4 (D1), U604.A3 (DAT0)
/SDMUX/D1: U602.7 (D2), U604.A4 (DAT1)
/SDMUX/D2: U601.4 (D1), U604.A5 (DAT2)
/SDMUX/D3: U601.7 (D2), U604.B2 (DAT3)
/SDMUX/D4: U603.4 (D1), U604.B3 (DAT4)
/SDMUX/D5: U603.7 (D2), U604.B4 (DAT5)
/SDMUX/D6: U603.9 (D3), U604.B5 (DAT6)
/SDMUX/D7: U603.12 (D4), U604.B6 (DAT7)
/SDMUX/MMC_PWR: C605.1, R602.1, U604.C6 (VCCQ), U604.E6 (VCC), U604.F5 (VCC), U604.J10 (VCC), U604.K9 (VCC), U604.M4 (VCCQ), U604.N4 (VCCQ), U604.P3 (VCCQ), U604.P5 (VCCQ); also elsewhere on the board
/SDMUX/MMC_PWR_EN: U602.9 (D3); also elsewhere on the board
/SDMUX/SD1_1: U601.2 (S1A); also elsewhere on the board
/SDMUX/SD1_2: U601.5 (S2A); also elsewhere on the board
/SDMUX/SD1_3: U601.11 (S3A); also elsewhere on the board
/SDMUX/SD1_4: U602.11 (S3A); also elsewhere on the board
/SDMUX/SD1_5: U601.14 (S4A); also elsewhere on the board
/SDMUX/SD1_7: U602.2 (S1A); also elsewhere on the board
/SDMUX/SD1_8: U602.5 (S2A); also elsewhere on the board
/SELECTOR/~SEL1: R601.2, U601.1 (SEL), U602.1 (SEL), U603.1 (SEL); also elsewhere on the board
GND: C601.2, C602.2, C603.2, C604.2, C605.2, C606.2, U601.8 (GND), U601.15 (~EN), U602.8 (GND), U602.15 (~EN), U603.8 (GND), U603.15 (~EN), U604.A6 (VSS), U604.C4 (VSSQ), U604.E7 (VSS), U604.G5 (VSS), U604.H10 (VSS), U604.J5 (VSS), U604.K8 (VSS), U604.N2 (VSSQ), U604.N5 (VSSQ), U604.P4 (VSSQ), U604.P6 (VSSQ); also elsewhere on the board
unnamed: C604.1, U604.C2 (VDDI)
unnamed: C606.1, R602.2, U604.K5 (~RST)

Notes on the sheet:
SD1_DAT3
SD1_CLK
SD1_DAT2
SD1_CMD

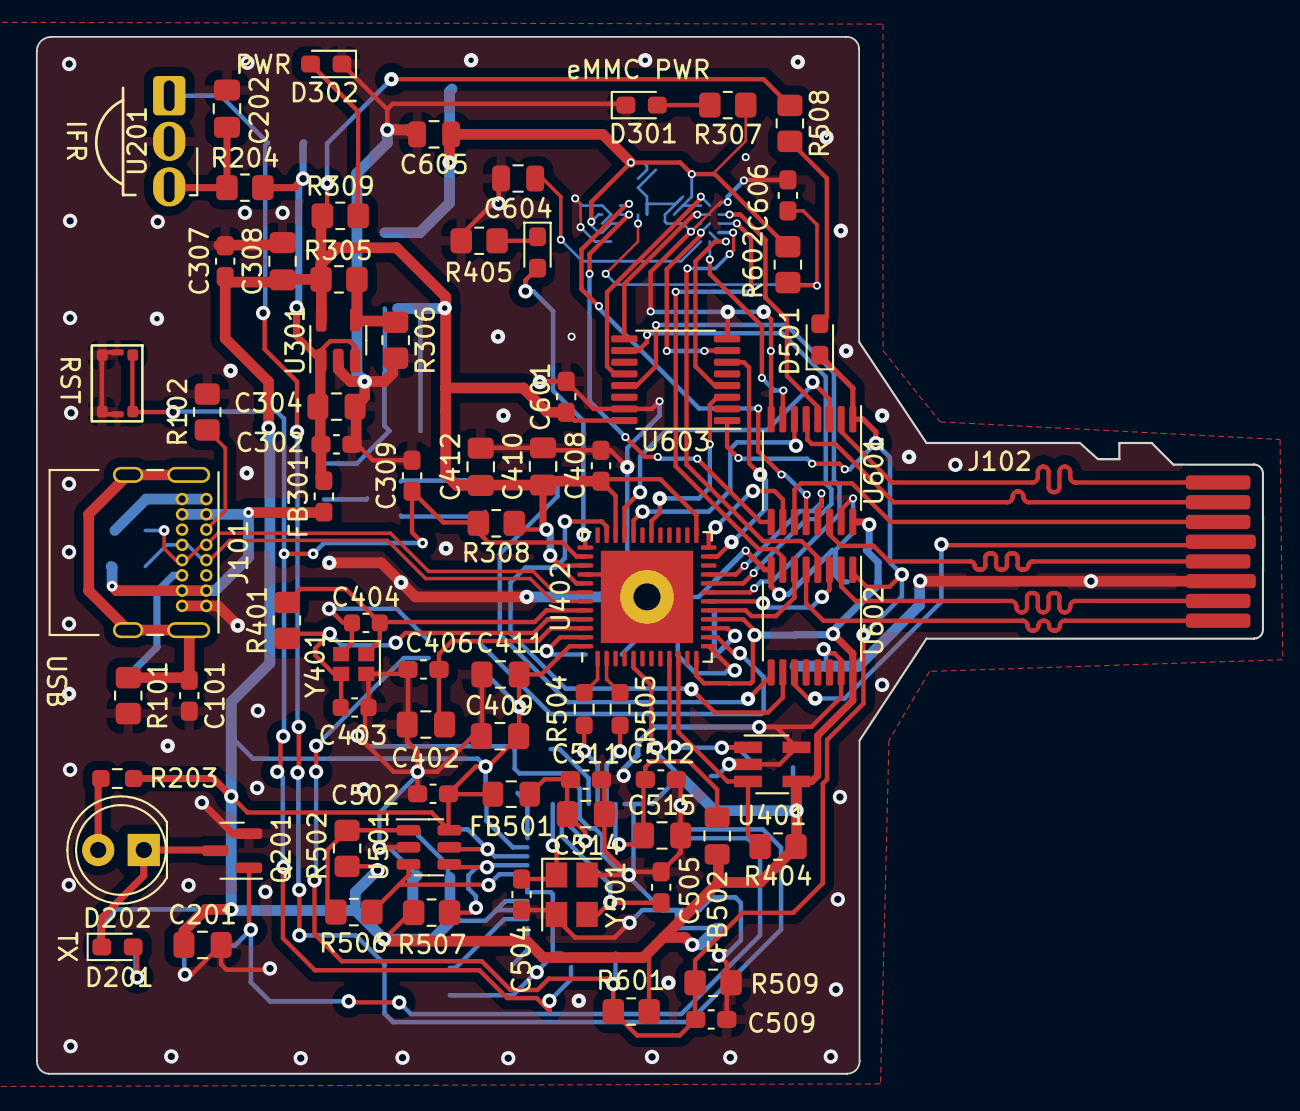
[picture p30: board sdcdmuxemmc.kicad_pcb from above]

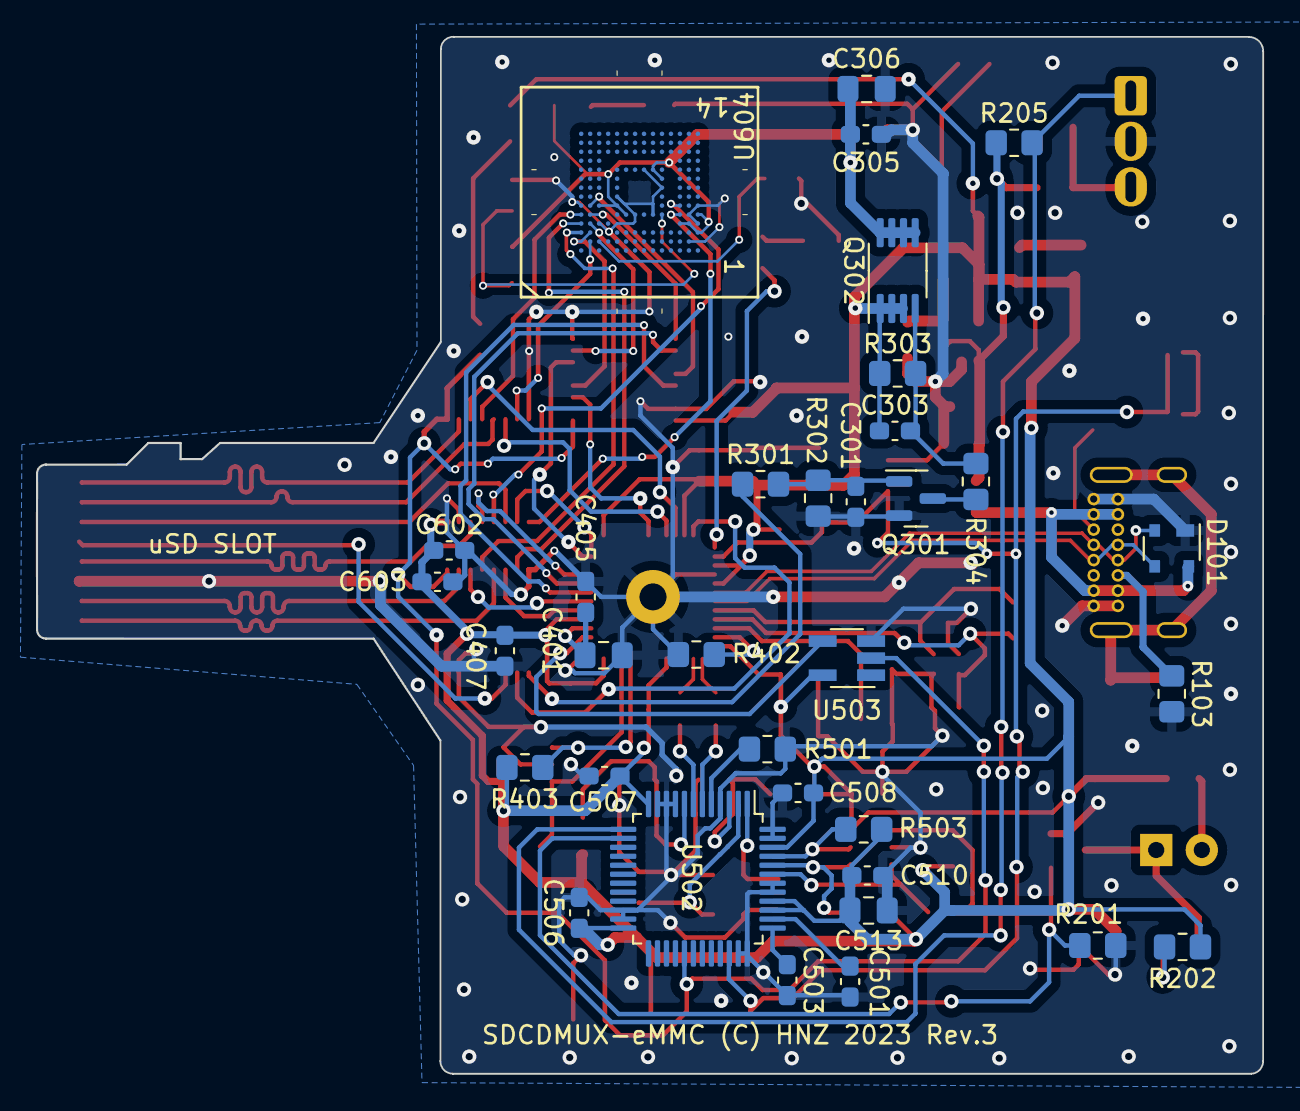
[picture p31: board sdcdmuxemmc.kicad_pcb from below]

Board: 2 copper layers, 68.3 x 57.8 mm, 107 parts (34 on the bottom side), 81 nets.

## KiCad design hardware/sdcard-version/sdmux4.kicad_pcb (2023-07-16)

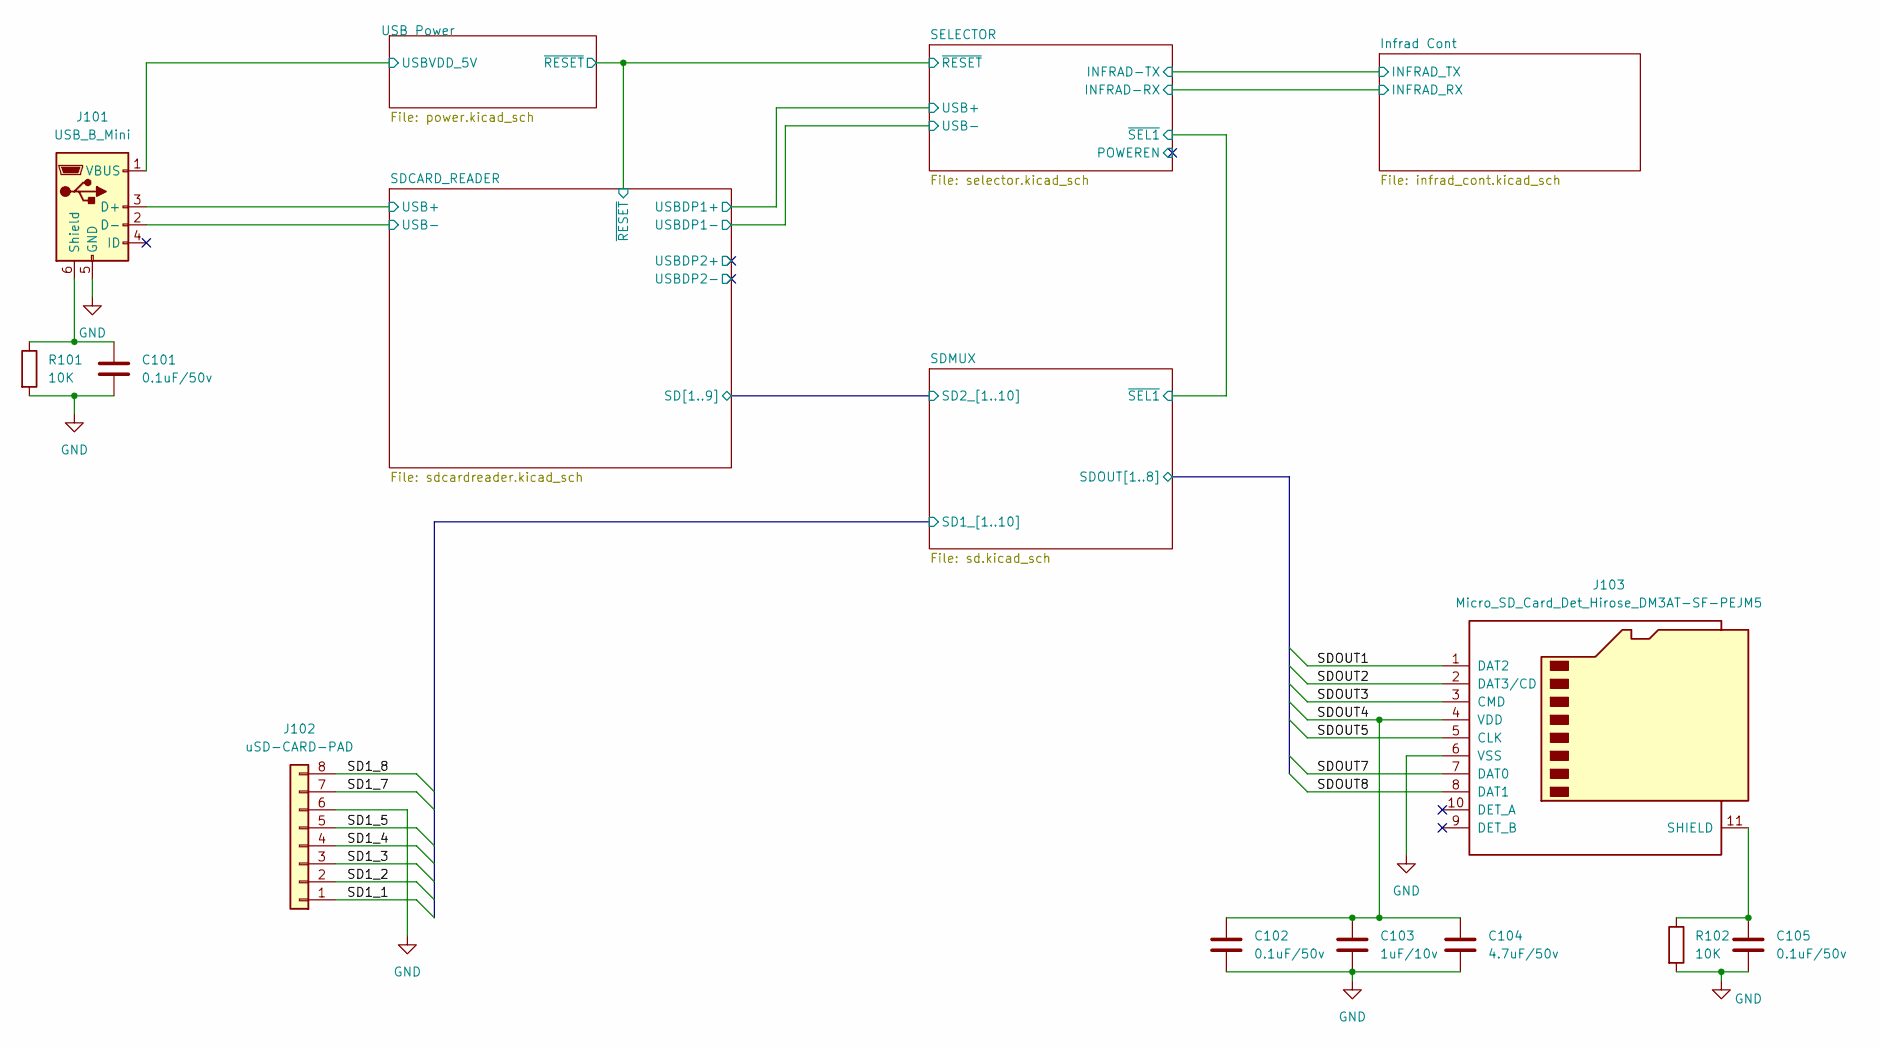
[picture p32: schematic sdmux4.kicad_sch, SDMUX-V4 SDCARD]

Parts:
C101, C102, C105: 0.1uF/50v; C_0603_1608Metric_Pad1.08x0.95mm_HandSolder
C103: 1uF/10v; C_0805_2012Metric_Pad1.18x1.45mm_HandSolder
C104: 4.7uF/50v; C_0805_2012Metric_Pad1.18x1.45mm_HandSolder
J101: USB_B_Mini; usb mini B connector c2235 dim 2
J102: uSD-CARD-PAD; uSD Card Pad
J103: Micro_SD_Card_Det_Hirose_DM3AT-SF-PEJM5; microSD_HC_Hirose_DM3AT-SF-PEJM5
R101, R102: 10K; R_0805_2012Metric_Pad1.20x1.40mm_HandSolder

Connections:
/SDCARD_READER/USB+: J101.3 (D+); also elsewhere on the board
/SDCARD_READER/USB-: J101.2 (D-); also elsewhere on the board
/SDMUX/SD1_1: J102.1; also elsewhere on the board
/SDMUX/SD1_2: J102.2; also elsewhere on the board
/SDMUX/SD1_3: J102.3; also elsewhere on the board
/SDMUX/SD1_4: J102.4; also elsewhere on the board
/SDMUX/SD1_5: J102.5; also elsewhere on the board
/SDMUX/SD1_7: J102.7; also elsewhere on the board
/SDMUX/SD1_8: J102.8; also elsewhere on the board
/SDMUX/SDOUT1: J103.1 (DAT2); also elsewhere on the board
/SDMUX/SDOUT2: J103.2 (DAT3/CD); also elsewhere on the board
/SDMUX/SDOUT3: J103.3 (CMD); also elsewhere on the board
/SDMUX/SDOUT4: C102.1, C103.1, C104.1, J103.4 (VDD); also elsewhere on the board
/SDMUX/SDOUT5: J103.5 (CLK); also elsewhere on the board
/SDMUX/SDOUT7: J103.7 (DAT0); also elsewhere on the board
/SDMUX/SDOUT8: J103.8 (DAT1); also elsewhere on the board
/USB Power/USBVDD_5V: J101.1 (VBUS); also elsewhere on the board
GND: C101.2, C102.2, C103.2, C104.2, C105.2, J101.5 (GND), J102.6, J103.6 (VSS), R101.2, R102.2; also elsewhere on the board
unnamed: C101.1, J101.6 (Shield), R101.1
unnamed: C105.1, J103.11 (SHIELD), R102.1

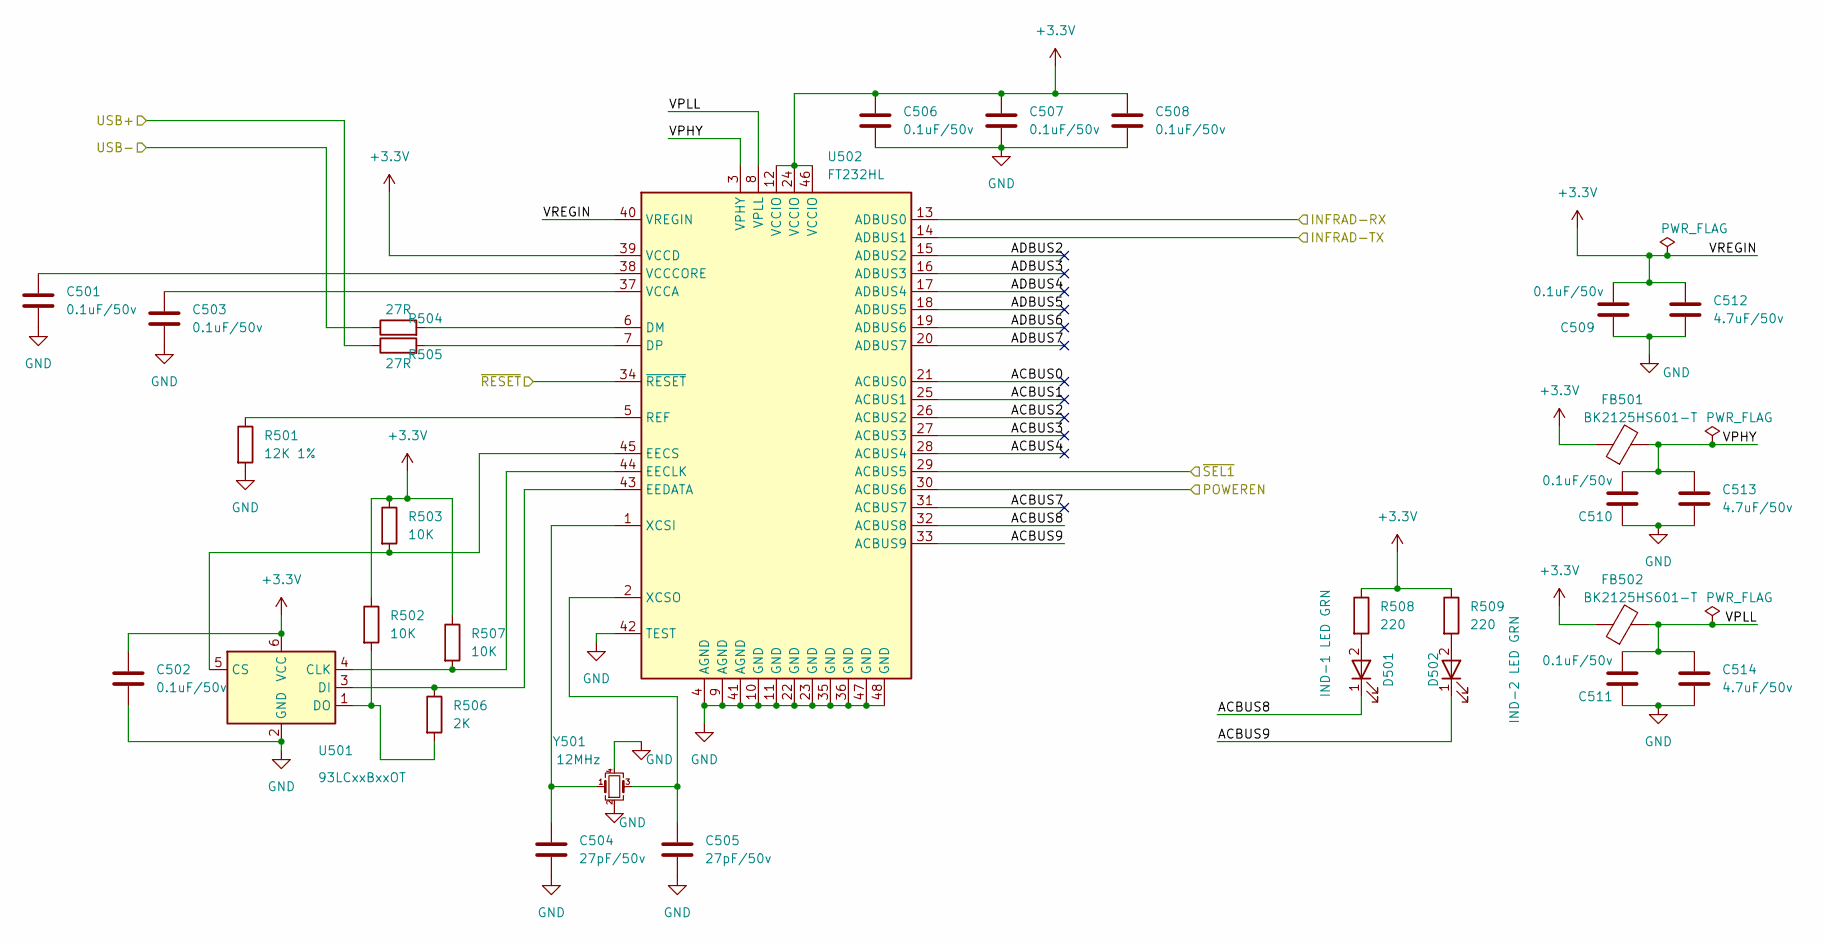
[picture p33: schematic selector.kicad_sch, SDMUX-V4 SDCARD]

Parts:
C501, C502, C503, C506, C507, C508, C509, C510, C511: 0.1uF/50v; C_0603_1608Metric_Pad1.08x0.95mm_HandSolder
C504, C505: 27pF/50v; C_0603_1608Metric_Pad1.08x0.95mm_HandSolder
C512, C513, C514: 4.7uF/50v; C_0805_2012Metric_Pad1.18x1.45mm_HandSolder
D501: IND-1 LED GRN; LED_0603_1608Metric_Pad1.05x0.95mm_HandSolder
D502: IND-2 LED GRN; LED_0603_1608Metric_Pad1.05x0.95mm_HandSolder
FB501, FB502: BK2125HS601-T; L_0805_2012Metric_Pad1.15x1.40mm_HandSolder
R501: 12K 1%; R_0805_2012Metric_Pad1.20x1.40mm_HandSolder
R502, R503, R507: 10K; R_0805_2012Metric_Pad1.20x1.40mm_HandSolder
R504, R505: 27R; R_0603_1608Metric_Pad0.98x0.95mm_HandSolder
R506: 2K; R_0805_2012Metric_Pad1.20x1.40mm_HandSolder
R508, R509: 220; R_0805_2012Metric_Pad1.20x1.40mm_HandSolder
U501: 93LCxxBxxOT; SOT-23-6
U502: FT232HL; LQFP-48_7x7mm_P0.5mm
Y501: 12MHz; Crystal_SMD_3225-4Pin_3.2x2.5mm

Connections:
+3.3V: C502.1, C506.1, C507.1, C508.1, C509.1, C512.1, FB501.1, FB502.1, R502.1, R503.1, R507.1, R508.1, R509.1, U501.6 (VCC), U502.12 (VCCIO), U502.24 (VCCIO), U502.39 (VCCD), U502.40 (VREGIN), U502.46 (VCCIO); also elsewhere on the board
/Infrad Cont/INFRAD_RX: U502.13 (ADBUS0); also elsewhere on the board
/Infrad Cont/INFRAD_TX: U502.14 (ADBUS1); also elsewhere on the board
/SDCARD_READER/USBDP1+: R505.1; also elsewhere on the board
/SDCARD_READER/USBDP1-: R504.1; also elsewhere on the board
/SDCARD_READER/~RESET: U502.34 (~RESET); also elsewhere on the board
/SDMUX/~SEL1: U502.29 (ACBUS5); also elsewhere on the board
/SELECTOR/ACBUS0: U502.21 (ACBUS0)
/SELECTOR/ACBUS1: U502.25 (ACBUS1)
/SELECTOR/ACBUS2: U502.26 (ACBUS2)
/SELECTOR/ACBUS3: U502.27 (ACBUS3)
/SELECTOR/ACBUS4: U502.28 (ACBUS4)
/SELECTOR/ACBUS7: U502.31 (ACBUS7)
/SELECTOR/ACBUS8: D501.1 (K), U502.32 (ACBUS8)
/SELECTOR/ACBUS9: D502.1 (K), U502.33 (ACBUS9)
/SELECTOR/ADBUS2: U502.15 (ADBUS2)
/SELECTOR/ADBUS3: U502.16 (ADBUS3)
/SELECTOR/ADBUS4: U502.17 (ADBUS4)
/SELECTOR/ADBUS5: U502.18 (ADBUS5)
/SELECTOR/ADBUS6: U502.19 (ADBUS6)
/SELECTOR/ADBUS7: U502.20 (ADBUS7)
/SELECTOR/POWEREN: U502.30 (ACBUS6)
/SELECTOR/VPHY: C510.1, C513.1, FB501.2, U502.3 (VPHY)
/SELECTOR/VPLL: C511.1, C514.1, FB502.2, U502.8 (VPLL)
GND: C501.2, C502.2, C503.2, C504.2, C505.2, C506.2, C507.2, C508.2, C509.2, C510.2, C511.2, C512.2, C513.2, C514.2, R501.2, U501.2 (GND), U502.4 (AGND), U502.9 (AGND), U502.10 (GND), U502.11 (GND), U502.22 (GND), U502.23 (GND), U502.35 (GND), U502.36 (GND), U502.41 (AGND), U502.42 (TEST), U502.47 (GND), U502.48 (GND), Y501.2, Y501.4; also elsewhere on the board
unnamed: D501.2 (A), R508.2
unnamed: D502.2 (A), R509.2
unnamed: R507.2, U501.4 (CLK), U502.44 (EECLK)
unnamed: R503.2, U501.5 (CS), U502.45 (EECS)
unnamed: R506.1, U501.3 (DI), U502.43 (EEDATA)
unnamed: R502.2, R506.2, U501.1 (DO)
unnamed: R504.2, U502.6 (DM)
unnamed: R505.2, U502.7 (DP)
unnamed: R501.1, U502.5 (REF)
unnamed: C503.1, U502.37 (VCCA)
unnamed: C501.1, U502.38 (VCCCORE)
unnamed: C504.1, U502.1 (XCSI), Y501.1
unnamed: C505.1, U502.2 (XCSO), Y501.3

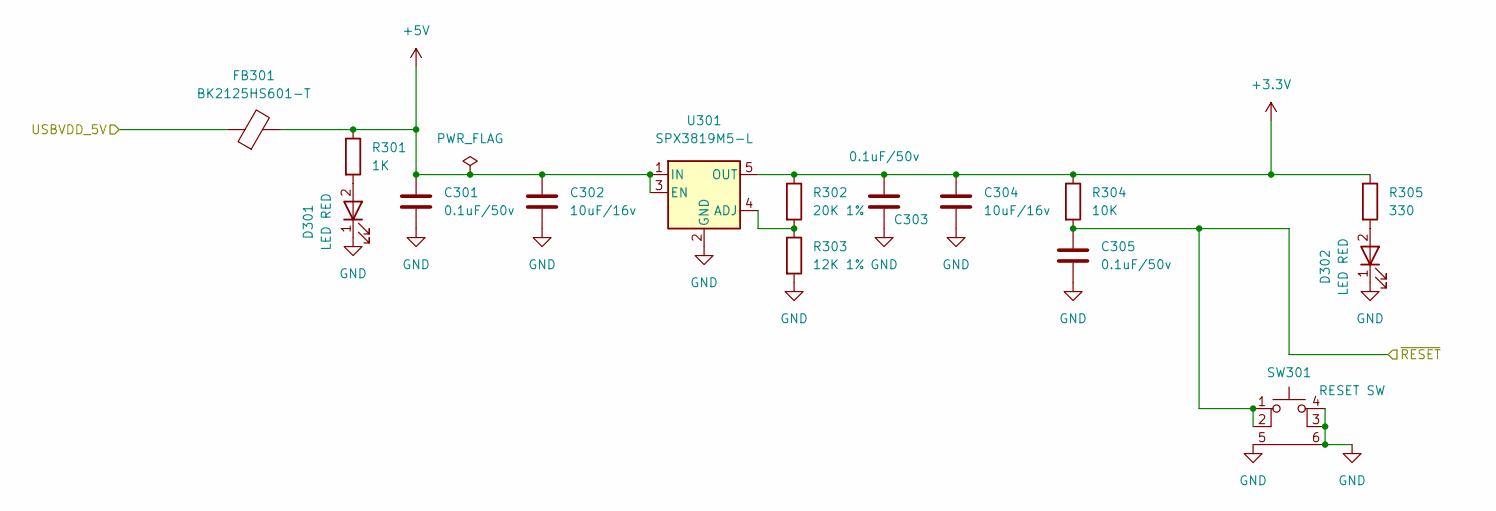
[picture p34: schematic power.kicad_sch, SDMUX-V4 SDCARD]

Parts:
C301, C303, C305: 0.1uF/50v; C_0603_1608Metric_Pad1.08x0.95mm_HandSolder
C302, C304: 10uF/16v; C_0805_2012Metric_Pad1.18x1.45mm_HandSolder
D301, D302: LED RED; LED_0603_1608Metric_Pad1.05x0.95mm_HandSolder
FB301: BK2125HS601-T; L_0603_1608Metric_Pad1.05x0.95mm_HandSolder
R301: 1K; R_0805_2012Metric_Pad1.20x1.40mm_HandSolder
R302: 20K 1%; R_0805_2012Metric_Pad1.20x1.40mm_HandSolder
R303: 12K 1%; R_0805_2012Metric_Pad1.20x1.40mm_HandSolder
R304: 10K; R_0805_2012Metric_Pad1.20x1.40mm_HandSolder
R305: 330; R_0805_2012Metric_Pad1.20x1.40mm_HandSolder
SW301: RESET SW; WS-TASV SMT Tact Switch
U301: SPX3819M5-L; SOT-23-5

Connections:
+3.3V: C303.1, C304.1, R302.1, R304.1, R305.1, U301.5 (OUT); also elsewhere on the board
+5V: C301.1, C302.1, FB301.2, R301.1, U301.1 (IN), U301.3 (EN); also elsewhere on the board
/SDCARD_READER/~RESET: C305.1, R304.2, SW301.1, SW301.2; also elsewhere on the board
/USB Power/USBVDD_5V: FB301.1; also elsewhere on the board
GND: C301.2, C302.2, C303.2, C304.2, C305.2, D301.1 (K), D302.1 (K), R303.2, SW301.3 (K), SW301.4 (A), SW301.5, SW301.6, U301.2 (GND); also elsewhere on the board
unnamed: D301.2 (A), R301.2
unnamed: D302.2 (A), R305.2
unnamed: R302.2, R303.1, U301.4 (ADJ)

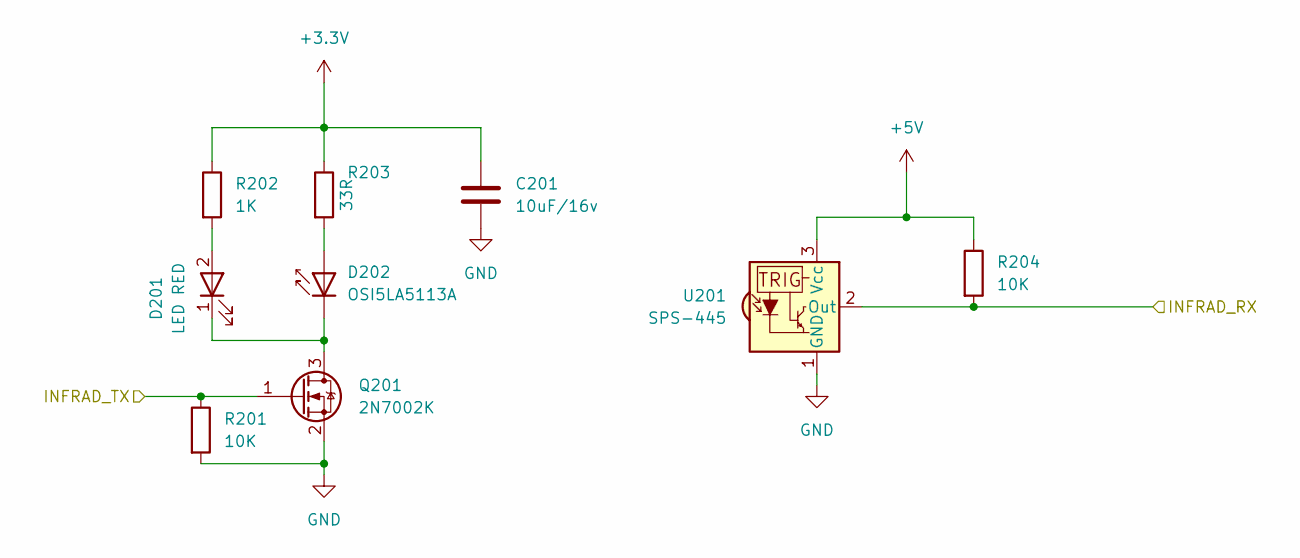
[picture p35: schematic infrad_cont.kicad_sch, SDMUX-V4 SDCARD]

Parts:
C201: 10uF/16v; C_0805_2012Metric_Pad1.18x1.45mm_HandSolder
D201: LED RED; LED_0603_1608Metric_Pad1.05x0.95mm_HandSolder
D202: OSI5LA5113A; LED_D5.0mm
Q201: 2N7002K; SOT-23
R201, R204: 10K; R_0805_2012Metric_Pad1.20x1.40mm_HandSolder
R202: 1K; R_0805_2012Metric_Pad1.20x1.40mm_HandSolder
R203: 33R; R_0603_1608Metric_Pad0.98x0.95mm_HandSolder
U201: SPS-445; SPS445 3pin

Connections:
+3.3V: C201.1, R202.1, R203.1; also elsewhere on the board
+5V: R204.1, U201.3 (Vcc); also elsewhere on the board
/Infrad Cont/INFRAD_RX: R204.2, U201.2 (Out); also elsewhere on the board
/Infrad Cont/INFRAD_TX: Q201.1 (G), R201.1; also elsewhere on the board
GND: C201.2, Q201.2 (S), R201.2, U201.1 (GND); also elsewhere on the board
unnamed: D201.2 (A), R202.2
unnamed: D201.1 (K), D202.1 (K), Q201.3 (D)
unnamed: D202.2 (A), R203.2


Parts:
C401, C402, C409, C410: 1uF/10v; C_0805_2012Metric_Pad1.18x1.45mm_HandSolder
C403, C404: 27pF/50v; C_0603_1608Metric
C405, C406, C407, C408: 0.1uF/50v; C_0603_1608Metric_Pad1.08x0.95mm_HandSolder
C411, C412: 4.7uF/50v; C_0805_2012Metric_Pad1.18x1.45mm_HandSolder
D401: LED RED; LED_0603_1608Metric_Pad1.05x0.95mm_HandSolder
FB401: BLM18RK102SN1; L_0603_1608Metric_Pad1.05x0.95mm_HandSolder
R401: 1M; R_0805_2012Metric_Pad1.20x1.40mm_HandSolder
R402: 12K 1%; R_0805_2012Metric_Pad1.20x1.40mm_HandSolder
R403, R404: 10K; R_0805_2012Metric_Pad1.20x1.40mm_HandSolder
R405: 330R; R_0805_2012Metric_Pad1.20x1.40mm_HandSolder
U401: AT24MAC402-STUM; SOT-23-5_HandSoldering
U402: USB2640-HZH-02; QFN-48-1EP_7x7mm_P0.5mm_EP5.15x5.15mm
Y401: 24MHz; Crystal_SMD_2016-4Pin_2.0x1.6mm

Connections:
+3.3V: C407.1, C408.1, C409.1, C410.1, C411.1, C412.1, R403.1, R404.1, U401.4 (VCC), U402.5 (VDD33), U402.12 (VDD33), U402.16 (VDD33), U402.25 (VDD33), U402.34 (VDD33), U402.39 (VBUS_DET), U402.41 (VDD33), U402.48 (VDD33); also elsewhere on the board
/SDCARD_READER/SD1: U402.33 (xD_D5/SD_D2); also elsewhere on the board
/SDCARD_READER/SD2: U402.32 (xD_D6/SD_D3/MS_D3); also elsewhere on the board
/SDCARD_READER/SD3: U402.24 (xD_CLE/SD_CMD/MS_D0); also elsewhere on the board
/SDCARD_READER/SD4: FB401.2; also elsewhere on the board
/SDCARD_READER/SD5: U402.21 (xD_nWP/SD_CLK/MS_BS); also elsewhere on the board
/SDCARD_READER/SD7: U402.18 (xD_D2/SD_D0/MS_D4); also elsewhere on the board
/SDCARD_READER/SD8: U402.17 (xD_D3/SD_D1/MS_D5); also elsewhere on the board
/SDCARD_READER/SD9: U402.14 (SD_~CD); also elsewhere on the board
/SDCARD_READER/USB+: U402.42 (USB+); also elsewhere on the board
/SDCARD_READER/USB-: U402.43 (USB-); also elsewhere on the board
/SDCARD_READER/USBDP1+: U402.2 (USBDN_DP2); also elsewhere on the board
/SDCARD_READER/USBDP1-: U402.1 (USBDN_DM2); also elsewhere on the board
/SDCARD_READER/USBDP2+: U402.4 (USBDN_DP3)
/SDCARD_READER/USBDP2-: U402.3 (USBDN_DM3)
/SDCARD_READER/~RESET: U402.38 (~RESET); also elsewhere on the board
GND: C401.2, C402.2, C403.1, C404.1, C405.2, C406.2, C407.2, C408.2, C409.2, C410.2, C411.2, C412.2, R402.2, R405.2, U401.2 (GND), U401.5 (WP), U402.13 (xD_D4/SD_WP/MS_SCLK), U402.40 (TEST), U402.49 (VSS), Y401.2, Y401.4; also elsewhere on the board
unnamed: D401.2 (A), U402.37 (LED)
unnamed: D401.1 (K), R405.1
unnamed: R403.2, U401.1 (SCL), U402.9 (SPI_CLK/SCL)
unnamed: R404.2, U401.3 (SDA), U402.10 (SPI_DO/SDA/SPI_SPD_SEL)
unnamed: FB401.1, U402.35 (CRD_PWR)
unnamed: C401.1, C405.1, U402.15 (CRFILT)
unnamed: C402.1, C406.1, U402.46 (PLLFILT)
unnamed: R402.1, U402.47 (RBIAS)
unnamed: C403.2, R401.1, U402.45 (XTAL1/CLKIN), Y401.3
unnamed: C404.2, R401.2, U402.44 (XTAL2), Y401.1

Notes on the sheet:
CRDPWR


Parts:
C601, C602, C603, C604, C606, C607: 0.1uF/50v; C_0603_1608Metric_Pad1.08x0.95mm_HandSolder
C605, C608: 2.2uF/16v; C_0603_1608Metric_Pad1.08x0.95mm_HandSolder
C609: 10uF/16v; C_0805_2012Metric_Pad1.18x1.45mm_HandSolder
D601: TGT SEL LED RED; LED_0603_1608Metric_Pad1.05x0.95mm_HandSolder
Q601, Q604, Q605, Q607: IRF7606PBF; MSOP-8_3x3mm_P0.65mm
Q602, Q603, Q606: 2N7002K; SOT-23
R601, R602, R603, R605, R607, R608: 10K; R_0805_2012Metric_Pad1.20x1.40mm_HandSolder
R604, R606, R609: 1K; R_0805_2012Metric_Pad1.20x1.40mm_HandSolder
U601: 74AHC1G14; SOT-23-5_HandSoldering
U602, U603: TMUX1574PWR; TSSOP-16_4.4x5mm_P0.65mm

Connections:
+3.3V: C601.1, C602.1, R601.1, R606.1, U601.5 (VCC), U602.16 (VDD), U603.16 (VDD); also elsewhere on the board
/SDCARD_READER/SD1: U602.3 (S1B); also elsewhere on the board
/SDCARD_READER/SD2: U602.6 (S2B); also elsewhere on the board
/SDCARD_READER/SD3: U602.10 (S3B); also elsewhere on the board
/SDCARD_READER/SD4: Q607.5 (D), Q607.6 (D), Q607.7 (D), Q607.8 (D); also elsewhere on the board
/SDCARD_READER/SD5: U602.13 (S4B); also elsewhere on the board
/SDCARD_READER/SD7: U603.3 (S1B); also elsewhere on the board
/SDCARD_READER/SD8: U603.6 (S2B); also elsewhere on the board
/SDCARD_READER/SD9: C603.1, C604.1, Q602.1 (G), Q603.1 (G), R602.1, R605.1, U601.4; also elsewhere on the board
/SDMUX/SD1_1: U602.2 (S1A); also elsewhere on the board
/SDMUX/SD1_2: U602.5 (S2A); also elsewhere on the board
/SDMUX/SD1_3: U602.11 (S3A); also elsewhere on the board
/SDMUX/SD1_4: Q601.5 (D), Q601.6 (D), Q601.7 (D), Q601.8 (D); also elsewhere on the board
/SDMUX/SD1_5: U602.14 (S4A); also elsewhere on the board
/SDMUX/SD1_7: U603.2 (S1A); also elsewhere on the board
/SDMUX/SD1_8: U603.5 (S2A); also elsewhere on the board
/SDMUX/SDOUT1: U602.4 (D1); also elsewhere on the board
/SDMUX/SDOUT2: U602.7 (D2); also elsewhere on the board
/SDMUX/SDOUT3: U602.9 (D3); also elsewhere on the board
/SDMUX/SDOUT4: C607.1, C609.1, Q604.5 (D), Q604.6 (D), Q604.7 (D), Q604.8 (D), Q605.5 (D), Q605.6 (D), Q605.7 (D), Q605.8 (D); also elsewhere on the board
/SDMUX/SDOUT5: U602.12 (D4); also elsewhere on the board
/SDMUX/SDOUT7: U603.4 (D1); also elsewhere on the board
/SDMUX/SDOUT8: U603.7 (D2); also elsewhere on the board
/SDMUX/~SEL1: C606.1, Q606.1 (G), R601.2, R607.1, U601.2, U602.1 (SEL), U603.1 (SEL); also elsewhere on the board
GND: C601.2, C602.2, C603.2, C604.2, C606.2, C607.2, C609.2, Q602.2 (S), Q603.2 (S), Q606.2 (S), R602.2, R605.2, R607.2, U601.3 (GND), U602.8 (GND), U602.15 (~EN), U603.8 (GND), U603.15 (~EN); also elsewhere on the board
unnamed: C605.1, Q601.1 (S), Q601.2 (S), Q601.3 (S), Q604.1 (S), Q604.2 (S), Q604.3 (S), R603.1
unnamed: C608.1, Q605.1 (S), Q605.2 (S), Q605.3 (S), Q607.1 (S), Q607.2 (S), Q607.3 (S), R608.1
unnamed: D601.2 (A), R606.2
unnamed: D601.1 (K), Q603.3 (D)
unnamed: C605.2, Q601.4 (G), Q604.4 (G), R603.2, R604.2
unnamed: Q602.3 (D), R604.1
unnamed: C608.2, Q605.4 (G), Q607.4 (G), R608.2, R609.2
unnamed: Q606.3 (D), R609.1

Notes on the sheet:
SD1_DAT3
SD2_DAT3
SD1_DAT1
SD2_DAT1
SD2_CLK
SD1_CLK
SD2_DAT0
SD2_DAT2
SD1_DAT2
SD1_DAT0
SD2_CMD
SD1_CMD



Board: 2 copper layers, 68.3 x 57.7 mm, 115 parts (49 on the bottom side), 77 nets.

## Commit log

2023-07-16 Add SD-CARD version schematics
    [bom.csv, infrad_cont.kicad_sch, power.kicad_sch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]
2023-07-20 Using the libftdi driver instead of libftd2xx.
2023-08-05 Update BOM list
    [bom.csv]
2023-08-14 Added USB type-C version
    [bom.csv, power.kicad_sch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]
2023-08-15 Update BOM for type-c version
    [bom.csv]
2023-08-19 Add case for type-c version
    [botom-body.stl, upper-body.stl]
2024-05-09 Corrected part number in the BOM
    [bom.csv, power.kicad_sch, sdcdmuxemmc-ifrc.kicad_sch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]
